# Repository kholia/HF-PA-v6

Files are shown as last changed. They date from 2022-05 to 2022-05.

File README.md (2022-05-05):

### HF-PA-v6

RF "Lego" blocks.

The idea behind this work is to build radio-things (TM) in stages which
connect to each other.

Note: This `HF-PA-v6` is like https://github.com/kholia/HF-PA-v5 which has been
broken out in stages. This makes the designing, and debugging processes much
easier.

#### Results

IRF510 @ 14 MHz -> 20v @ drain. RF output > 7.5W. No LPF. Clean'ish looking
output. No oscillations. BS170 @ 5.5v. DC bias set high for max'ish "Idq".

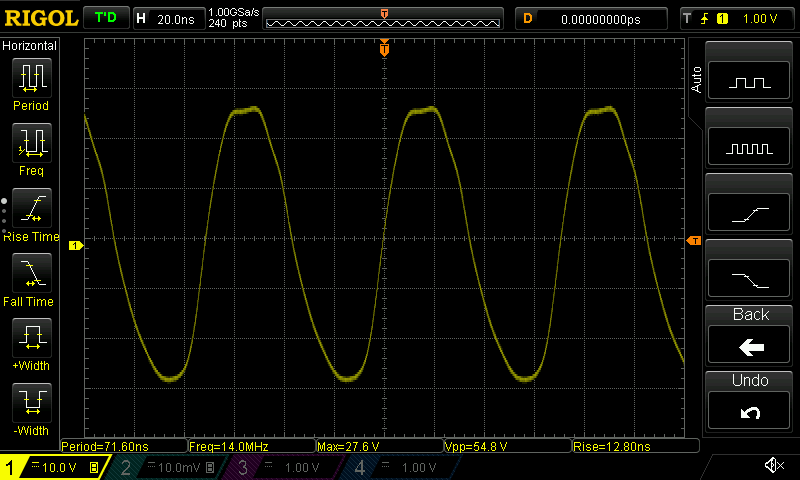
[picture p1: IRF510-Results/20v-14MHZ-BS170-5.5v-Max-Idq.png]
Lots of usable power @ 14 MHz


IRF510 @ 21 MHz -> 15v @ drain. 12.75W DC input. RF output > 3W. No LPF.
Clean'ish looking output. No oscillations. BS170 @ 5.5v. DC bias set high for
max'ish "Idq". Almost 4W can be achieved with max "Idq".

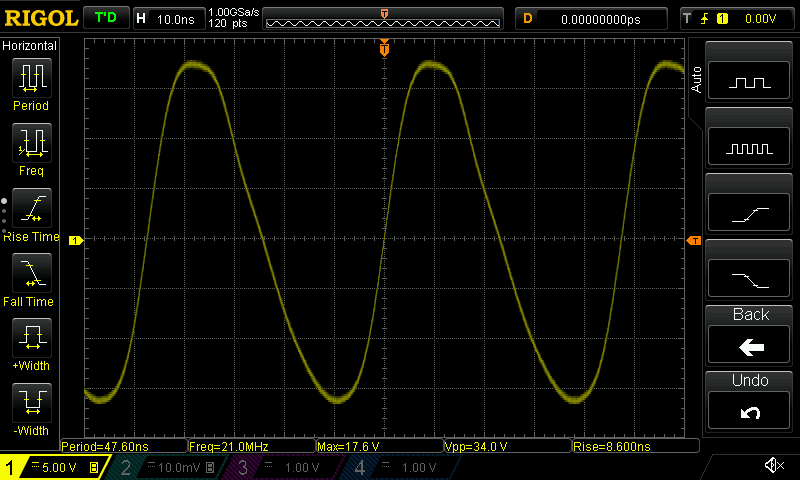
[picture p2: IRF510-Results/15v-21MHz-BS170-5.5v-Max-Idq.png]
Demo 0


IRF510 @ 28 MHz -> 14v @ drain. 9W DC input. RF output > 2W (on meter). No LPF.
Clean'ish looking output. No oscillations. BS170 @ 5.5v. DC bias set high for
max'ish "Idq".

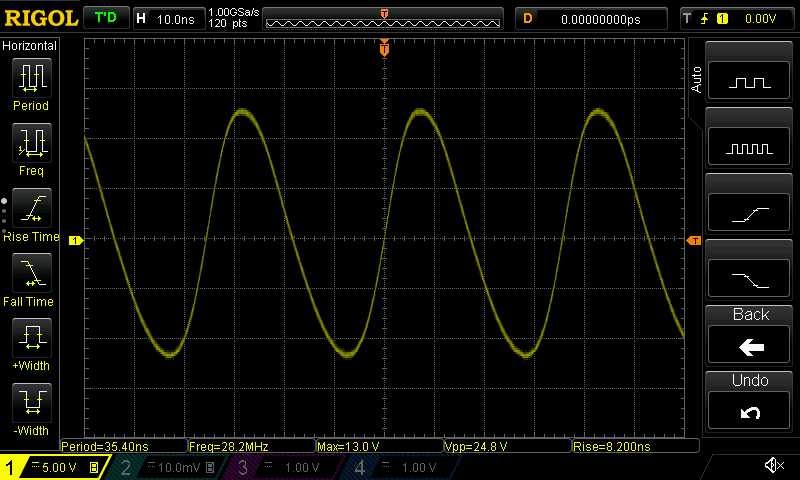
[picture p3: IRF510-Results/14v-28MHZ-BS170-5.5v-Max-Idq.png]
28 MHz - Usable Power


IRF510 @ 28 MHz -> 17v @ drain. RF output > 2.25W (on scope), 3.5W on RF power
meter. No LPF. Clean'ish looking output. No oscillations. BS170 @ 6v. DC bias
set high for max "Idq" @ 4.2v roughly.

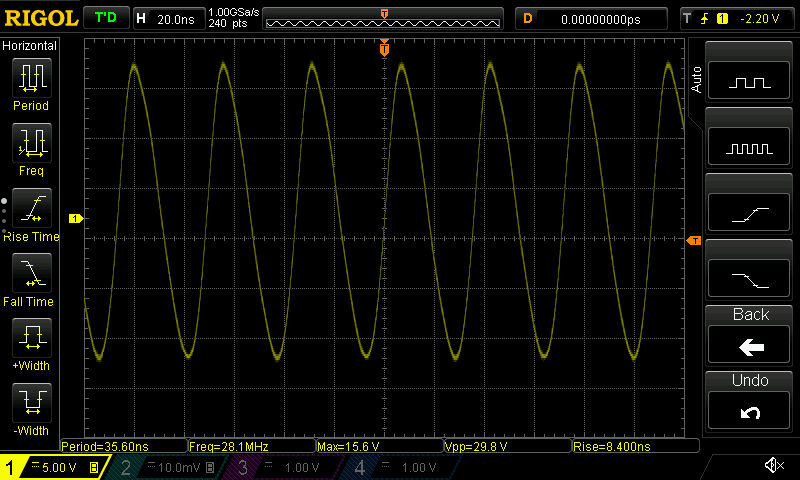
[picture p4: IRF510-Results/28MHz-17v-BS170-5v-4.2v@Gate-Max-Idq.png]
28 MHz - Usable Power 2


Note: We can even use 30v (and higher+) drain voltages (PA voltages) with
IRF510 - with much more care though!

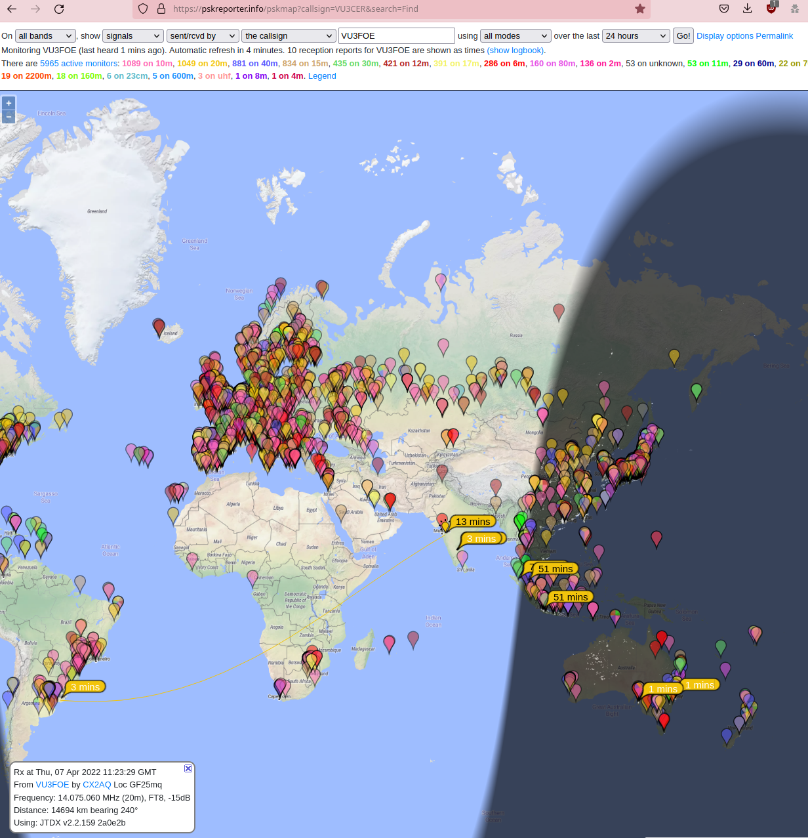
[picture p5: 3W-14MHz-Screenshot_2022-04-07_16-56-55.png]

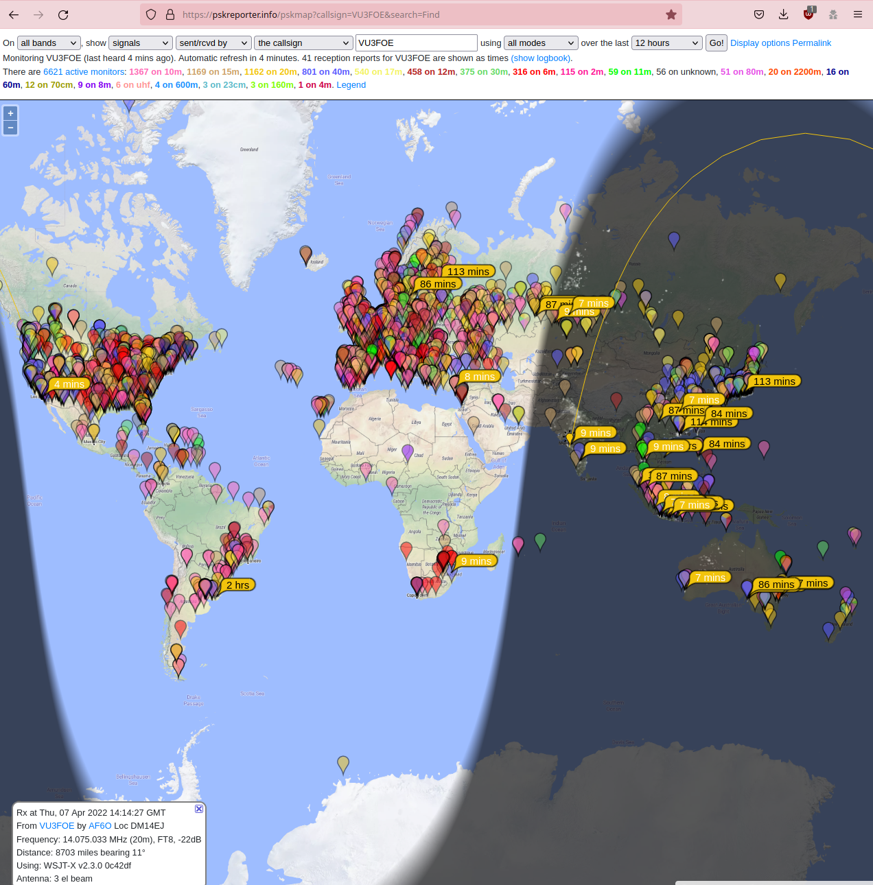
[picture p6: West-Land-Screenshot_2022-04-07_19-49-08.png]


Even 3W can get worldwide DX contacts when propagation is playing along ;)

7W (or less) of HF RF power offers global communications coverage when
propagation is good:

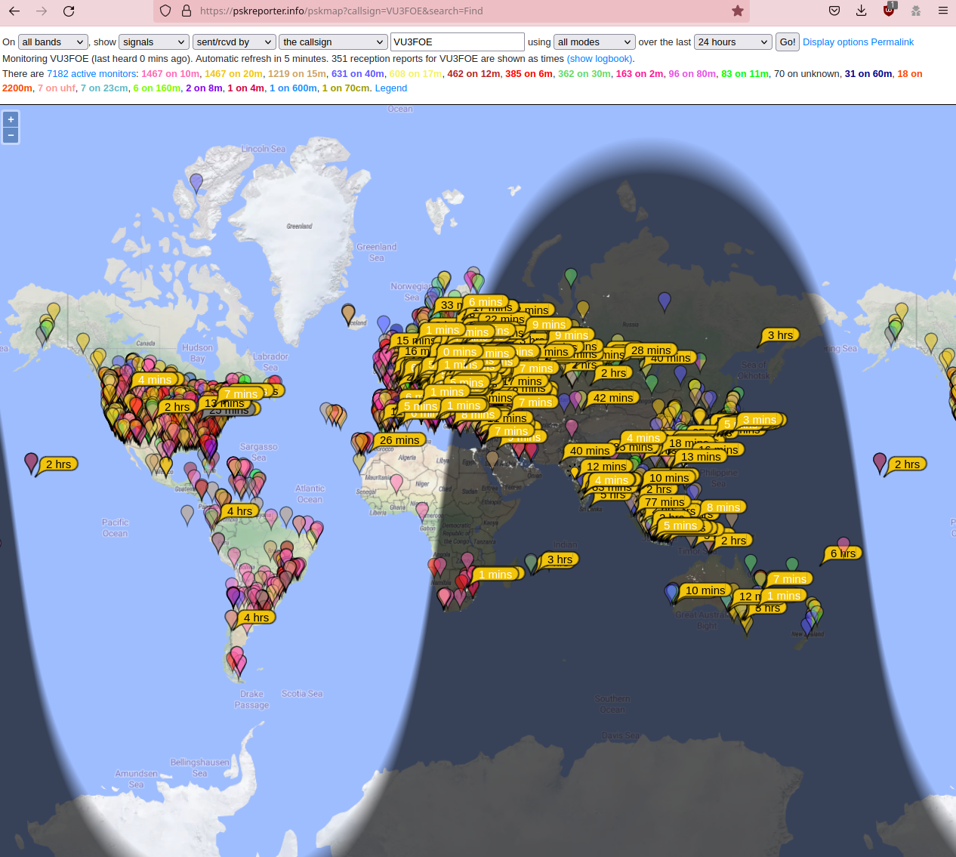
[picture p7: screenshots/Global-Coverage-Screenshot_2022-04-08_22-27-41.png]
Global Coverage

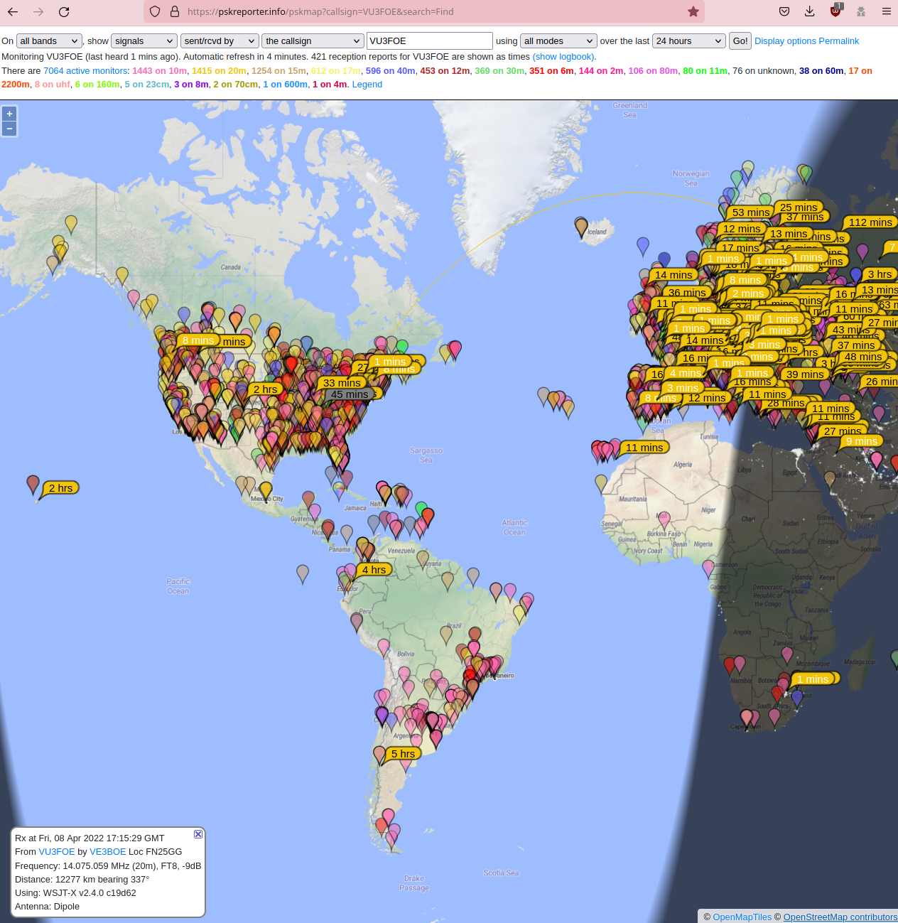
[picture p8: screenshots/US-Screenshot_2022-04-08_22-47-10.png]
US - Many Spots

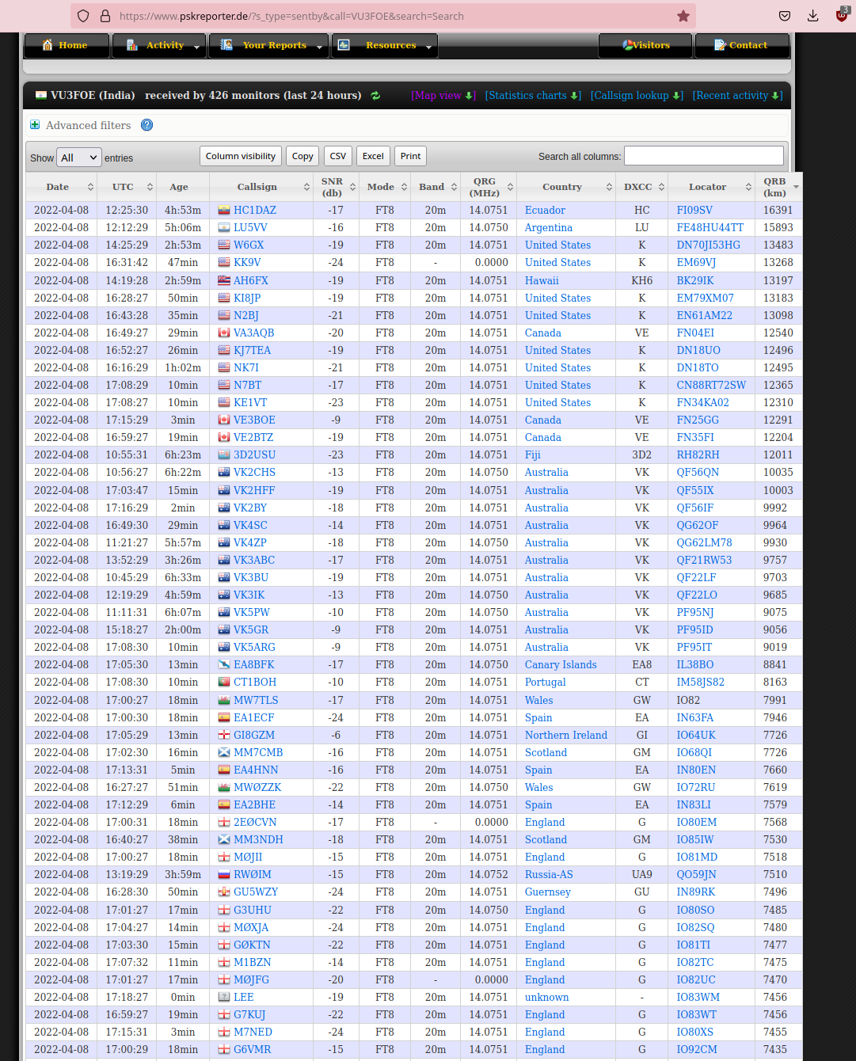
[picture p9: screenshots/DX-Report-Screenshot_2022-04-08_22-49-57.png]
DX Report


#### Notes

[BS170 Driver Performance](./BS170-Driver-Performance.txt)

As Vds is increased, the Vgs needs to be increased too - see the following
graph.

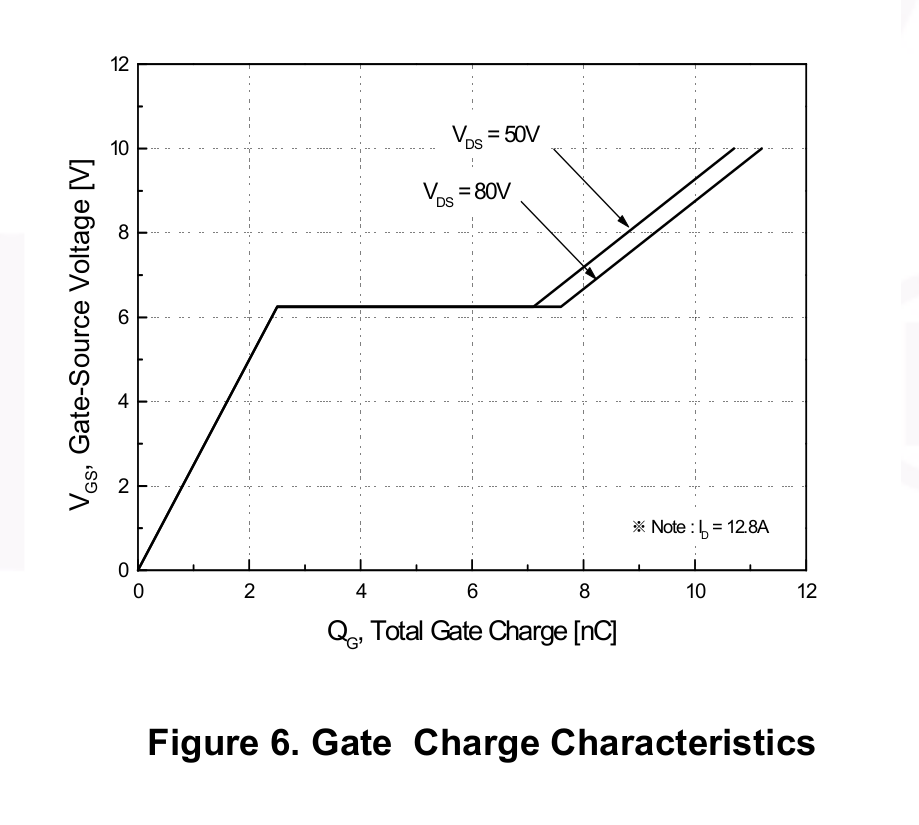
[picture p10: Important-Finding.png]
Finding


If the gate DC bias is too less, the MOSFET will not turn on properly, and will
generate a lot of distortion - one prominent distorted waveform will be at
half-the-operating frequency!

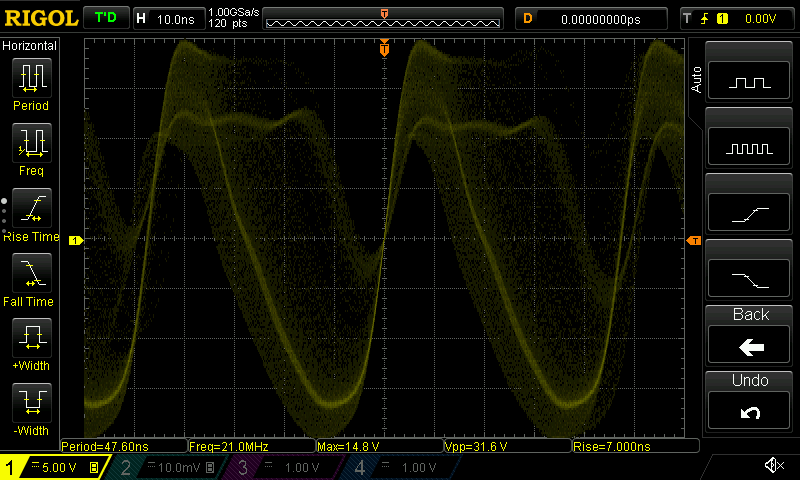
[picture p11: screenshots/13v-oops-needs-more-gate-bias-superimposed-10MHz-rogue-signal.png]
Oops - low DC bias


When operating at max "Idq" (for best linearity), the power to the IRF510
should be PTT controlled - otherwise too much (battery) power will turn to heat
instead of RF!

#### Special Notes

While IRF510 can get destroyed due to oscillations, in my case it has been a
failed 7805 (or 78L05) regulator which ultimately causes cascading failures.

A 7805 regulator can fail in fail-short mode, where `Vout == Vin`! This changes
the bias of the driver stage (BS170), and it goes in full conduction
immediately without any RF input because Vgs(th) is exceeded quite easily.
This causes further failures in the PA system!

My 7805s (and 78L05s) of dubious origin were failing (Vout shorted to Vin!)
around 20v to 24v. Here is what `bd139` (from https://www.eevblog.com/forum/)
has to say on this topic,

```
None of the voltage regulators work properly above about 20V if you want 5V
out. If you need to drop more, add a preregulator.

I found this out the hard way as well dropping 28V to 5V DC for logic in an RF
PA driver. Currently waiting for a board spin. I only needed 50mA and didn't
want RF noise so I went with a simple MOSFET/zener/resistor preregulator to
drop it down to 18Vish. Because the current requirements are relatively low I
don't need to heatsink either then as the load is spread evenly across both
MOSFET and 7805.

Also if you value the circuit it's driving, stick a 5W 5.6V zener across the
regulator output. That will smoke the prereg / regulator not the load!
```

Thank you `bd139`!

#### PCB Renderings

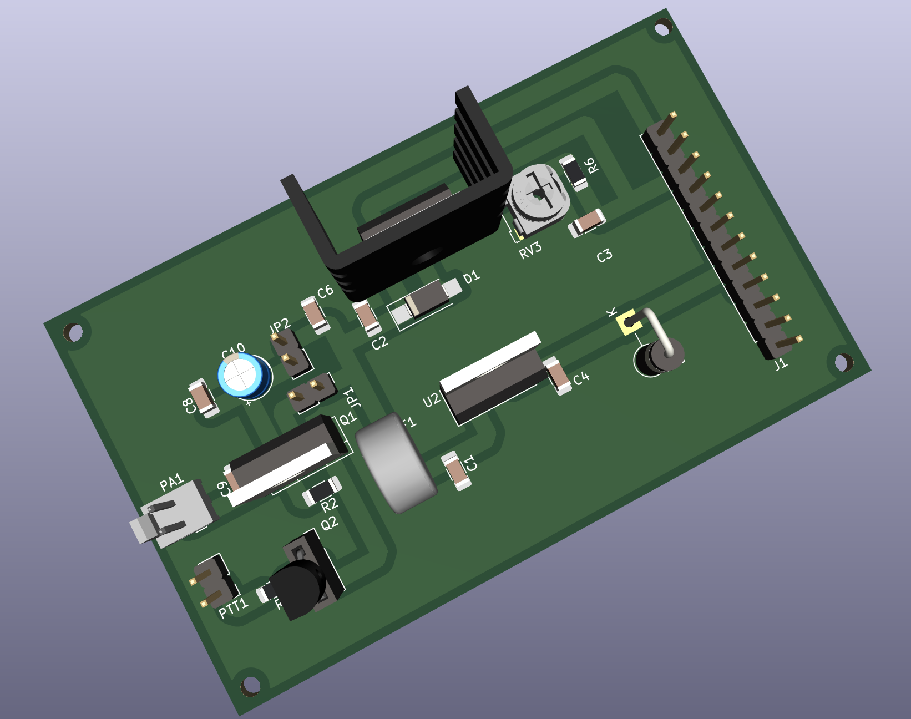
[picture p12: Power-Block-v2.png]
Power Block


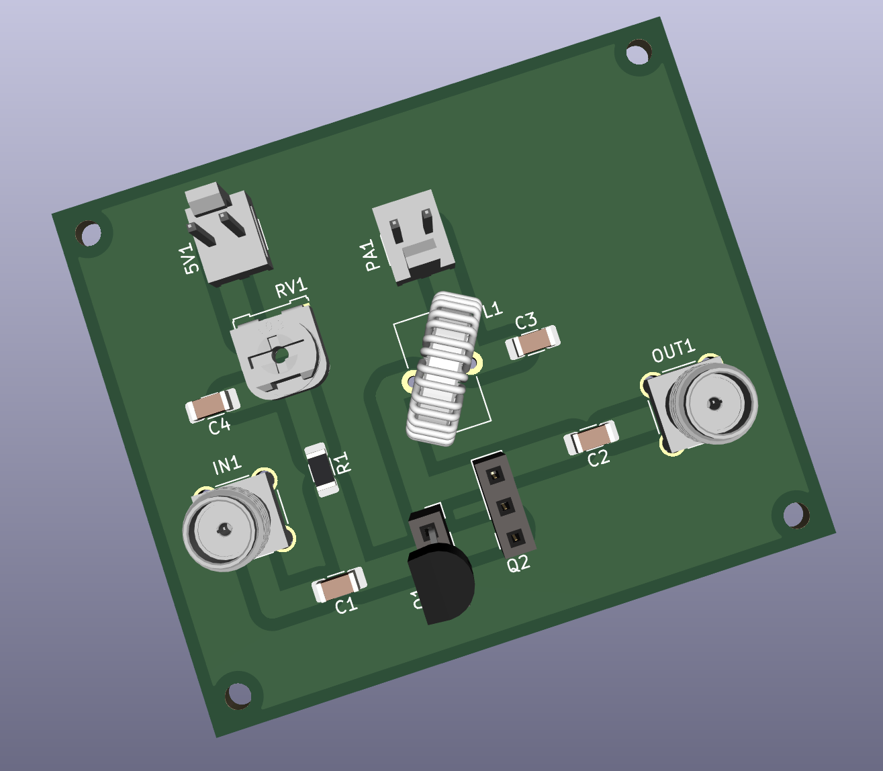
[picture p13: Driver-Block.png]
Driver Block


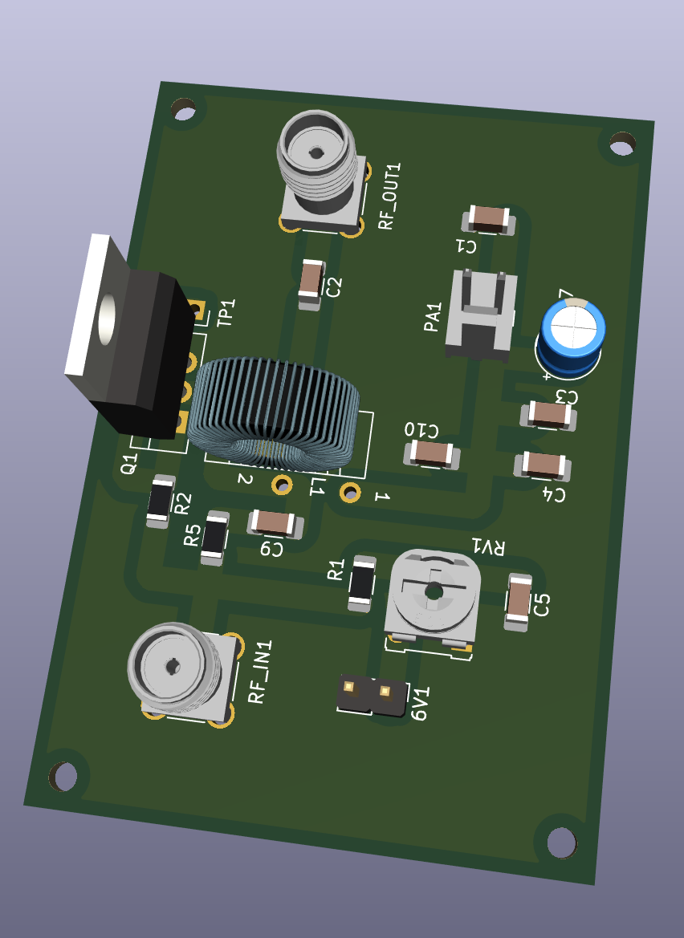
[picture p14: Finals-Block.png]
Finals Block


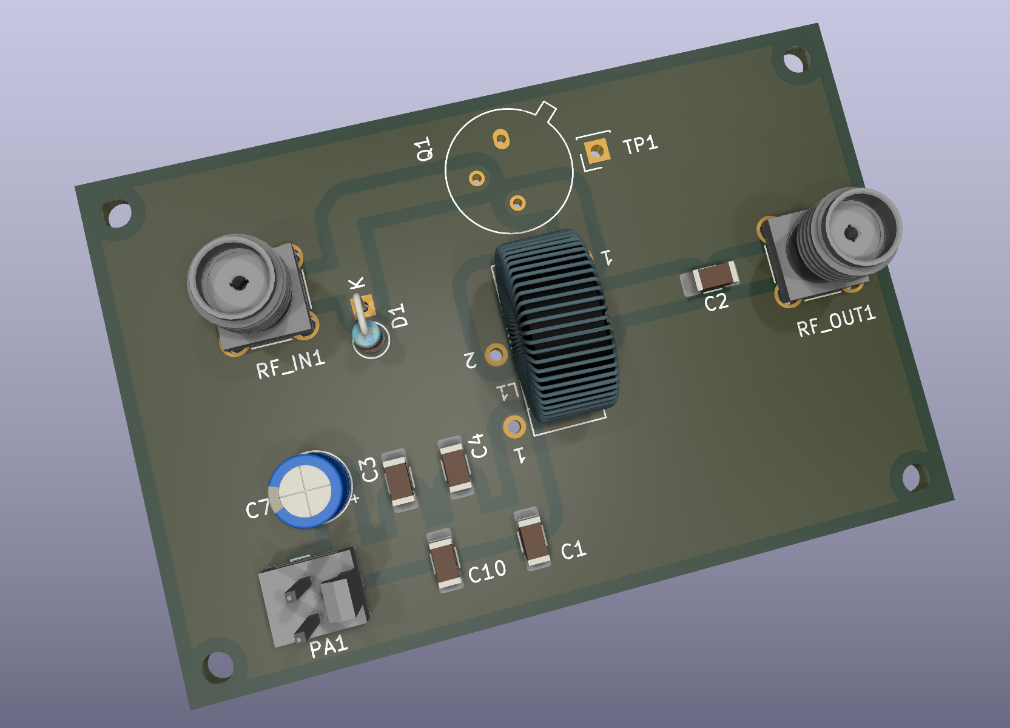
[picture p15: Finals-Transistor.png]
Finals Transistor Block


#### Joining In

Are you interested in such projects, and spam-free technical discussions?

If yes, you might be interested in joining [the 'HAMBREWERS' Telegram group](https://t.me/+TwzGyKGe8_QI_B3y).

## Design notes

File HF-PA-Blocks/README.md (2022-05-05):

The `Finals-RD15.kicad_pcb` is oversized on purpose for two reasons:

- To avoid the tedious job of cutting the larger 3x2 PCB into a smaller size.

- To save etchant by putting a copper pour over the larger area.

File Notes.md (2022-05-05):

In general terms, the PCB industry considers an RF circuit board to be any high
frequency PCB that operates above 100MHz.

IRF510 - The device dissipates 43 watts so as long as the kit doesn't draw more
that about 3.5 amps max at 12 volts, it won't fail. At 5 watts and 50%
efficiency it won't draw more than 1 amp and  can handle full reflected SWR.

https://www.rapidonline.com/Catalogue/Search?Query=CDIL

LED Wemos D1 Mini - The built-in led is on pin D4, and it is inverted.

```
Z=Vcc2 / 2PO
In [7]: (22 * 22) / (2 * 5)
Out[7]: 48.4
```

```
[dhiru@zippy DS1054Z_screen_capture]$ python2 OscScreenGrabLAN.py png 192.168.1.16
Instrument ID: RIGOL TECHNOLOGIES,DS1054Z,DS1ZA203916662,00.04.04.SP3

Receiving screen capture...
Saved file: 'captures/DS1054Z_DS1ZA203916662_2021-09-21_18.23.17.png'
```

From the internet,

7805 -> Without an extra heatsink, you can burn off up to 2W. If you need more
current heatsinks are cheap and effective. Every 11 degrees Celsius cooler you
run your semiconductors, reliability doubles.

- Get the max die temperature from the regulator datasheet

- Get the Theta(j-a) number from the datasheet in degrees C per watt.

- Calculate the power dissipated by your device. Example: 9 volts in, 5 volts
  out at 1 amp would be 4 watts.

- Multiply the watts dissipated by Theta(j-a) to get the temperature rise.

- Add the temperature rise to the maximum ambient temperature the device will
  be exposed to.

- If the number computed in #5 is greater than the max die temperature, then
  you need to use a heatsink or some other way to actively
  cool the device.

- If you use a heatsink, you will use a slightly different set of calculations
  involving the regulator's Theta(j-c) (Not Theta(j-a).

For a 7805 it's 65 C/W junction to air.

This means that if the regulator produces 1 W of heat, the die will be 65
degrees C hotter than the ambient air.  The maximum operating temperature is
125 C. Pune temperature (inside the case) -> 70 c.

Can dissipate -> (125 - 70) / 65 -> 0.84 watts. P = VI. This allows around
100mA of current when input voltage is 14v.

Note: Try the `Small mark` option instead of the regular `Real drill` option in
KiCad.

Note 2: Set track width to >= 2.2mm in KiCad - try to work with this. For the
copper pour, set clearance to 0.850.

...

LTspice notes:

- Download LTspice (Google "Download LTspice"). It's free.

- `~/Documents/LTspiceXVII/lib`

  Extract external components to this path.

- Extract the `contents` of `LTspiceXVII_2019Jan29.zip` (Google for this file) properly to `~/Documents/LTspiceXVII` path.

...

From Daniel Alonso:

A unnecessarily large L doesn't do harm by itself, but the 'series' self
resonant frequencies decrease when you increase the turns count. A
rule-of-thumb is choosing an inductive reactance of 4 times the load
resistance, at the lower frequency. Supposing the circuit is to drive a 50 ohm
load, to get a reactance of 200 ohms at 3.5MHz you will need L = 200/(2*pi*3.5)
= 9.1uH. Or if you are more conservative with 10 times the R, it should be
22.7uH.

From Sandeep Lohia:

Inductive reactance on primary side is critical and the magic number is `36`.

```
36 ÷ lowest operating frequency.
36 ÷ 7 = 5 uh
```

Inductance on secondary not critical but turns ratio is...

...

From Farhan:

At 25 watts, the RF peak voltage is 50v. This is easily handled by the regular
disc ceramics rated for 60v. Higher power will require expensive capacitors.

Pinout helper:

1 2 3 4
E B C E

BD139
B C E

NTE-224 results with BS170 driver:

- 4W @ 7 MHz
- 1.6W+ @ 14 MHz
- 0.8W @ 28 MHz

NTE-224 is usable, and offers OK'ish performance for the price (0.23 USD).

The IRF510 option is much better at this price point (with higher voltages
though).

Learnings `http://pa0o-jaap.blogspot.com`:

- http://pa0o-jaap.blogspot.com/2017/03/u3s-5w-pa.html
- http://pa0o-jaap.blogspot.com/2017/04/u3s-ultimate3-5w.html

- The QRP-LABS IRF510 5W PA will not deliver more then 1W at 28MHz not to
  speak of 50 MHz there it is an attenuator. Using the RD15HVF1 Mitsubishi did
  bring just a little more. 3-4 W at 28 and 1.5 W at 50MHz

- The 5W-PA (RD15HVF1 powered) is good for 10MHz and lower but very
  disappointing at higher bands.

- At 20W DC input it stays cool.

- Turning up the bias seems the only way to get 5W out at 50MHz 12V.

- Use 7 turns (instead of 10) on the output transformer.

- Use 1:9 (trifilar) output transformer instead of my bifilar one!?

- T1 modified to 8 turns (from 10 turns originally) also did not increase the
  10 and 6 output.

PDX-v2 PA (`HF-PA-Combined`):

3.3W+ @ 13.8v @ 21 MHz. 4.25v gate bias. 13.65W DC IN. RF meter shows ~4W.

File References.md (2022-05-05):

#### References

- http://shop.qrp-labs.com/pa
- http://shop.qrp-labs.com/kits/U3S
- https://github.com/kholia/HF-PA-v3/
- https://github.com/kholia/HF-PA-v2/
- https://github.com/agustinmartino/wsjt_transceiver
- https://www.qrp-labs.com/ultimate3/u3info/u3sbifilar.html
- https://www.qsl.net/py2ohh/trx/peanuts/peanuts.html
- https://www.qsl.net/py2ohh/trx/lpf100w/lpf100w.html (LPF filters)
- http://hyse.org/pdf/www.aoc.nrao.edu/~pharden/hobby/_ClassDEF1.pdf
- http://hyse.org/pdf/www.aoc.nrao.edu/~pharden/hobby/_ClassDEF2.pdf
- http://thestone.zone/radio/2020/12/13/multi-watt-amplifier.html
- http://thestone.zone/radio/2020/12/18/gate-driver-amplifier.html
- http://thestone.zone/radio/2021/01/14/capacitors.html
- http://thestone.zone/radio/2021/01/16/minor-enhancements.html
- https://www.g0kla.com/scpa/SimpleCheapPA.php
- https://www.linkedin.com/pulse/rf-pcb-design-rules-manufacturing-process-lisa-chu/
- http://thestone.zone/radio/2021/06/04/attenuator.html
- http://thestone.zone/radio/2021/06/05/power-amplifier.html
- https://on7dq.blogspot.com/2020/12/qcx-mini-measurements.html
- https://www.random-science-tools.com/electronics/dBm-Watts-volts.htm
- https://www.mitsubishielectric.com/semiconductors/php/oSearch.php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
- http://www.carnut.info/WSPR_Tx/WSPR_Tx.htm
- https://sites.google.com/view/andy-g0ftd/iron-fist-transmitter
- https://www.dj0abr.de/english/technik/dds/pa.htm
- https://www.qsl.net/py2ohh/
- https://hf5l.pl/en/transceiver-usdx-with-arduino-nano/#
- http://www.m0rzf.co.uk/PA_Old/index.html
- https://vk3hn.wordpress.com/2019/05/01/summit-prowler-6-a-pocket-sized-ssb-cw-transceiver-for-80-40-30-and-20m/
- http://am-transmitter.blogspot.com/2014/07/protect-your-mosfet-final-stage.html
- https://electronics.stackexchange.com/questions/11583/grounding-a-soldering-iron
- http://hfsignals.blogspot.com/p/25-watt-linear-for-40-and-20.html
- http://www.norcalqrp.org/nb6mminiboots.htm
- https://github.com/RoGeorge/DS1054Z_screen_capture
- https://github.com/profdc9/QRPAmplifier

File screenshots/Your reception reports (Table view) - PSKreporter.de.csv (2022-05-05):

ID | Date | UTC | Age | Callsign | SNR (db) | Mode | Band | QRG (MHz) | Country | DXCC | Locator | QRB (km)
398 | 2022-04-08 | 12:25:30 | 4h:53m | HC1DAZ | -17 | FT8 | 20m | 14.0751 | Ecuador | HC | FI09SV | 16391
403 | 2022-04-08 | 12:12:29 | 5h:06m | LU5VV | -16 | FT8 | 20m | 14.0750 | Argentina | LU | FE48HU44TT | 15893
353 | 2022-04-08 | 14:25:29 | 2h:53m | W6GX | -19 | FT8 | 20m | 14.0751 | United States | K | DN70JI53HG | 13483
279 | 2022-04-08 | 16:31:42 | 47min | KK9V | -24 | FT8 | - | 0.0000 | United States | K | EM69VJ | 13268
359 | 2022-04-08 | 14:19:28 | 2h:59m | AH6FX | -19 | FT8 | 20m | 14.0751 | Hawaii | KH6 | BK29IK | 13197
296 | 2022-04-08 | 16:28:27 | 50min | KI8JP | -19 | FT8 | 20m | 14.0751 | United States | K | EM79XM07 | 13183
250 | 2022-04-08 | 16:43:28 | 35min | N2BJ | -21 | FT8 | 20m | 14.0751 | United States | K | EN61AM22 | 13098
215 | 2022-04-08 | 16:49:27 | 29min | VA3AQB | -20 | FT8 | 20m | 14.0751 | Canada | VE | FN04EI | 12540
184 | 2022-04-08 | 16:52:27 | 26min | KJ7TEA | -19 | FT8 | 20m | 14.0751 | United States | K | DN18UO | 12496
321 | 2022-04-08 | 16:16:29 | 1h:02m | NK7I | -21 | FT8 | 20m | 14.0751 | United States | K | DN18TO | 12495
63 | 2022-04-08 | 17:08:29 | 10min | N7BT | -17 | FT8 | 20m | 14.0751 | United States | K | CN88RT72SW | 12365
66 | 2022-04-08 | 17:08:27 | 10min | KE1VT | -23 | FT8 | 20m | 14.0751 | United States | K | FN34KA02 | 12310
15 | 2022-04-08 | 17:15:29 | 3min | VE3BOE | -9 | FT8 | 20m | 14.0751 | Canada | VE | FN25GG | 12291
164 | 2022-04-08 | 16:59:27 | 19min | VE2BTZ | -19 | FT8 | 20m | 14.0751 | Canada | VE | FN35FI | 12204
417 | 2022-04-08 | 10:55:31 | 6h:23m | 3D2USU | -23 | FT8 | 20m | 14.0751 | Fiji | 3D2 | RH82RH | 12011
416 | 2022-04-08 | 10:56:27 | 6h:22m | VK2CHS | -13 | FT8 | 20m | 14.0750 | Australia | VK | QF56QN | 10035
94 | 2022-04-08 | 17:03:47 | 15min | VK2HFF | -19 | FT8 | 20m | 14.0751 | Australia | VK | QF55IX | 10003
6 | 2022-04-08 | 17:16:29 | 2min | VK2BY | -18 | FT8 | 20m | 14.0751 | Australia | VK | QF56IF | 9992
212 | 2022-04-08 | 16:49:30 | 29min | VK4SC | -14 | FT8 | 20m | 14.0751 | Australia | VK | QG62OF | 9964
412 | 2022-04-08 | 11:21:27 | 5h:57m | VK4ZP | -18 | FT8 | 20m | 14.0750 | Australia | VK | QG62LM78 | 9930
374 | 2022-04-08 | 13:52:29 | 3h:26m | VK3ABC | -17 | FT8 | 20m | 14.0751 | Australia | VK | QF21RW53 | 9757
421 | 2022-04-08 | 10:45:29 | 6h:33m | VK3BU | -19 | FT8 | 20m | 14.0751 | Australia | VK | QF22LF | 9703
401 | 2022-04-08 | 12:19:29 | 4h:59m | VK3IK | -13 | FT8 | 20m | 14.0750 | Australia | VK | QF22LO | 9685
414 | 2022-04-08 | 11:11:31 | 6h:07m | VK5PW | -10 | FT8 | 20m | 14.0750 | Australia | VK | PF95NJ | 9075
347 | 2022-04-08 | 15:18:27 | 2h:00m | VK5GR | -9 | FT8 | 20m | 14.0751 | Australia | VK | PF95ID | 9056
60 | 2022-04-08 | 17:08:30 | 10min | VK5ARG | -9 | FT8 | 20m | 14.0751 | Australia | VK | PF95IT | 9019
75 | 2022-04-08 | 17:05:30 | 13min | EA8BFK | -17 | FT8 | 20m | 14.0750 | Canary Islands | EA8 | IL38BO | 8841
62 | 2022-04-08 | 17:08:30 | 10min | CT1BOH | -10 | FT8 | 20m | 14.0751 | Portugal | CT | IM58JS82 | 8163
150 | 2022-04-08 | 17:00:27 | 18min | MW7TLS | -17 | FT8 | 20m | 14.0751 | Wales | GW | IO82 | 7991
130 | 2022-04-08 | 17:00:30 | 18min | EA1ECF | -24 | FT8 | 20m | 14.0751 | Spain | EA | IN63FA | 7946
80 | 2022-04-08 | 17:05:29 | 13min | GI8GZM | -6 | FT8 | 20m | 14.0751 | Northern Ireland | GI | IO64UK | 7726
111 | 2022-04-08 | 17:02:30 | 16min | MM7CMB | -16 | FT8 | 20m | 14.0751 | Scotland | GM | IO68QI | 7726
35 | 2022-04-08 | 17:13:31 | 5min | EA4HNN | -16 | FT8 | 20m | 14.0751 | Spain | EA | IN80EN | 7660
304 | 2022-04-08 | 16:27:27 | 51min | MWØZZK | -22 | FT8 | 20m | 14.0750 | Wales | GW | IO72RU | 7619
42 | 2022-04-08 | 17:12:29 | 6min | EA2BHE | -14 | FT8 | 20m | 14.0751 | Spain | EA | IN83LI | 7579
128 | 2022-04-08 | 17:00:31 | 18min | 2EØCVN | -17 | FT8 | - | 0.0000 | England | G | IO80EM | 7568
260 | 2022-04-08 | 16:40:27 | 38min | MM3NDH | -18 | FT8 | 20m | 14.0751 | Scotland | GM | IO85IW | 7530
148 | 2022-04-08 | 17:00:27 | 18min | MØJII | -15 | FT8 | 20m | 14.0751 | England | G | IO81MD | 7518
386 | 2022-04-08 | 13:19:29 | 3h:59m | RWØIM | -15 | FT8 | 20m | 14.0752 | Russia-AS | UA9 | QO59JN | 7510
290 | 2022-04-08 | 16:28:30 | 50min | GU5WZY | -24 | FT8 | 20m | 14.0751 | Guernsey | GU | IN89RK | 7496
127 | 2022-04-08 | 17:01:27 | 17min | G3UHU | -22 | FT8 | 20m | 14.0750 | England | G | IO80SO | 7485
92 | 2022-04-08 | 17:04:27 | 14min | MØXJA | -24 | FT8 | 20m | 14.0751 | England | G | IO82SQ | 7480
99 | 2022-04-08 | 17:03:30 | 15min | GØKTN | -22 | FT8 | 20m | 14.0751 | England | G | IO81TI | 7477
70 | 2022-04-08 | 17:07:32 | 11min | M1BZN | -14 | FT8 | 20m | 14.0751 | England | G | IO82TC | 7475
126 | 2022-04-08 | 17:01:27 | 17min | MØJFG | -20 | FT8 | - | 0.0000 | England | G | IO82UC | 7470
2 | 2022-04-08 | 17:18:27 | 0min | LEE | -19 | FT8 | 20m | 14.0751 | unknown | - | IO83WM | 7456
161 | 2022-04-08 | 16:59:27 | 19min | G7KUJ | -22 | FT8 | 20m | 14.0751 | England | G | IO83WT | 7456
9 | 2022-04-08 | 17:15:31 | 3min | M7NED | -24 | FT8 | 20m | 14.0751 | England | G | IO80XS | 7455
138 | 2022-04-08 | 17:00:29 | 18min | G6VMR | -15 | FT8 | 20m | 14.0751 | England | G | IO92CM | 7435
162 | 2022-04-08 | 16:59:27 | 19min | EA5OL | -20 | FT8 | 20m | 14.0751 | Spain | EA | IM99OK50 | 7433
176 | 2022-04-08 | 16:56:30 | 22min | M3BWF | -18 | FT8 | 20m | 14.0751 | England | G | IO91DP | 7430
203 | 2022-04-08 | 16:50:29 | 28min | EA5IZO | -17 | FT8 | 20m | 14.0751 | Spain | EA | IM98QJ | 7430
90 | 2022-04-08 | 17:04:27 | 14min | MØLCS | -24 | FT8 | 20m | 14.0751 | England | G | IO91GN | 7413
46 | 2022-04-08 | 17:11:30 | 7min | G4BRK | -14 | FT8 | 20m | 14.0751 | England | G | IO91HP | 7407
96 | 2022-04-08 | 17:03:30 | 15min | MØIZM | -24 | FT8 | 20m | 14.0751 | England | G | IO92KX | 7390
151 | 2022-04-08 | 17:00:27 | 18min | M7CLO | -19 | FT8 | 20m | 14.0751 | England | G | IO93KA | 7390
209 | 2022-04-08 | 16:50:27 | 28min | G7AAY | -21 | FT8 | 20m | 14.0751 | England | G | IO92NG | 7373
22 | 2022-04-08 | 17:15:27 | 3min | MØHOM | -10 | FT8 | 20m | 14.0751 | England | G | IO93QO | 7357
36 | 2022-04-08 | 17:13:30 | 5min | G7RDX | -18 | FT8 | 20m | 14.0752 | England | G | IO91RU | 7350
172 | 2022-04-08 | 16:57:29 | 21min | 2EØFVN | -24 | FT8 | 20m | 14.0751 | England | G | IO91WP | 7321
132 | 2022-04-08 | 17:00:30 | 18min | F1DXP | -15 | FT8 | 20m | 14.0751 | France | F | JN05CU | 7305
86 | 2022-04-08 | 17:04:31 | 14min | EA6FA | -14 | FT8 | 20m | 14.0751 | Balearic Islands | EA6 | JM08RQ | 7246
114 | 2022-04-08 | 17:02:29 | 16min | F4BHK | -12 | FT8 | 20m | 14.0751 | France | F | JN08LT | 7243
423 | 2022-04-08 | 10:38:42 | 6h:40m | VK6IR | -24 | FT8 | 20m | 14.0751 | Australia | VK | OF77WJ | 7231
74 | 2022-04-08 | 17:06:27 | 12min | VK6AS | -14 | FT8 | 20m | 14.0751 | Australia | VK | OF77WW05 | 7188
367 | 2022-04-08 | 14:01:29 | 3h:17m | VK4ABW/8 | -18 | FT8 | 20m | 14.0750 | Australia | VK | PH57MM | 7152
323 | 2022-04-08 | 16:16:29 | 1h:02m | DL8EX | -24 | FT8 | 20m | 14.0751 | Germany | DL | JO42 | 7122
195 | 2022-04-08 | 16:51:27 | 27min | ON4BAR | -18 | FT8 | 20m | 14.0751 | Belgium | ON | JO10RU | 7069
285 | 2022-04-08 | 16:29:29 | 49min | LA1ØØB | -24 | FT8 | 20m | 14.0751 | Norway | LA | JP20RH | 7055
178 | 2022-04-08 | 16:55:29 | 23min | LB9ZG | -17 | FT8 | 20m | 14.0751 | Norway | LA | JP20VR | 7045
16 | 2022-04-08 | 17:15:29 | 3min | PE1GCW | -24 | FT8 | 20m | 14.0751 | Netherlands | PA | JO21AK | 7032
202 | 2022-04-08 | 16:50:29 | 28min | ON4JON | -16 | FT8 | 20m | 14.0750 | Belgium | ON | JO20AN | 7026
14 | 2022-04-08 | 17:15:29 | 3min | PD5JOS | -9 | FT8 | 20m | 14.0750 | Netherlands | PA | JO21CW | 7024
252 | 2022-04-08 | 16:43:27 | 35min | ON7UDM | -24 | FT8 | 20m | 14.0751 | Belgium | ON | JO21BC | 7024
125 | 2022-04-08 | 17:01:28 | 17min | OZ2AFN | -24 | FT8 | 20m | 14.0751 | Denmark | OZ | JO57 | 7018
206 | 2022-04-08 | 16:50:27 | 28min | ON3PVC | -22 | FT8 | 20m | 14.0751 | Belgium | ON | JO20CX | 7017
235 | 2022-04-08 | 16:47:15 | 31min | ON3URE | -22 | FT8 | 20m | 14.0751 | Belgium | ON | JO20CW | 7017
11 | 2022-04-08 | 17:15:30 | 3min | LB8ZH | -24 | FT8 | 20m | 14.0750 | Norway | LA | JP30CI | 7015
24 | 2022-04-08 | 17:15:27 | 3min | NL13951 | -24 | FT8 | 20m | 14.0751 | unknown | - | JO21EV | 7012
26 | 2022-04-08 | 17:15:26 | 3min | ZS6TAN | -18 | FT8 | 20m | 14.0751 | South Africa | ZS | KG43CW | 7007
277 | 2022-04-08 | 16:33:43 | 45min | PD1HPB | -22 | FT8 | 20m | 14.0751 | Netherlands | PA | JO22JP | 6991
336 | 2022-04-08 | 16:11:30 | 1h:07m | ZS6ZO | -18 | FT8 | 20m | 14.0748 | South Africa | ZS | KG44CE | 6989
231 | 2022-04-08 | 16:47:30 | 31min | PDØRDD | -24 | FT8 | 20m | 14.0751 | Netherlands | PA | JO22MD14 | 6969
272 | 2022-04-08 | 16:35:29 | 43min | PAØADG | -13 | FT8 | 20m | 14.0751 | Netherlands | PA | JO22NB | 6963
145 | 2022-04-08 | 17:00:27 | 18min | ON4ATW | -24 | FT8 | 20m | 14.0751 | Belgium | ON | JO20NX55 | 6953
48 | 2022-04-08 | 17:11:29 | 7min | PD2SHB | -23 | FT8 | 20m | 14.0751 | Netherlands | PA | JO21PQ | 6948
133 | 2022-04-08 | 17:00:30 | 18min | F4FSY | -14 | FT8 | 20m | 14.0751 | France | F | JN25KN | 6942
193 | 2022-04-08 | 16:51:29 | 27min | PD9BG | -22 | FT8 | 20m | 14.0751 | Netherlands | PA | JO21QP | 6942
23 | 2022-04-08 | 17:15:27 | 3min | PDØWAG | -19 | FT8 | 20m | 14.0751 | Netherlands | PA | JO21TX | 6928
89 | 2022-04-08 | 17:04:28 | 14min | LA6HNA | -20 | FT8 | 20m | 14.0751 | Norway | LA | JP53AS | 6904
120 | 2022-04-08 | 17:01:30 | 17min | PD1DMO | -15 | FT8 | 20m | 14.0751 | Netherlands | PA | JO32FI | 6875
280 | 2022-04-08 | 16:31:30 | 47min | DL7CW | -22 | FT8 | 20m | 14.0750 | Germany | DL | JO31FH | 6863
261 | 2022-04-08 | 16:39:30 | 39min | DL2OAH | -17 | FT8 | 20m | 14.0751 | Germany | DL | JO31FE24 | 6862
157 | 2022-04-08 | 16:59:30 | 19min | LA5FJA | -17 | FT8 | 20m | 14.0751 | Norway | LA | JP41UP | 6860
312 | 2022-04-08 | 16:23:30 | 55min | LA7GM | -18 | FT8 | 20m | 14.0751 | Norway | LA | JP65DL | 6856
112 | 2022-04-08 | 17:02:30 | 16min | LB8PI | -14 | FT8 | 20m | 14.0751 | Norway | LA | JP53LL | 6851
189 | 2022-04-08 | 16:51:29 | 27min | PD7JLP | -24 | FT8 | 20m | 14.0751 | Netherlands | PA | JO32KQ | 6851
306 | 2022-04-08 | 16:27:27 | 51min | PA7KY | -14 | FT8 | 20m | 14.0751 | Netherlands | PA | JO32LR | 6846
247 | 2022-04-08 | 16:44:30 | 34min | DJ6JZ | -16 | FT8 | 20m | 14.0751 | Germany | DL | JO31KK37 | 6836
338 | 2022-04-08 | 15:55:27 | 1h:23m | F6BPZ | -12 | FT8 | 20m | 14.0751 | France | F | JN35DS79 | 6833
379 | 2022-04-08 | 13:45:29 | 3h:33m | LB1RJ | -22 | FT8 | 20m | 14.0751 | Norway | LA | JO49PN | 6830
375 | 2022-04-08 | 13:50:28 | 3h:28m | LA8AV | -20 | FT8 | 20m | 14.0750 | Norway | LA | JO49RT | 6827
198 | 2022-04-08 | 16:50:33 | 28min | DL8DBU | -20 | FT8 | 20m | 14.0751 | Germany | DL | JO30NP22 | 6810
232 | 2022-04-08 | 16:47:29 | 31min | F4CHF | -14 | FT8 | 20m | 14.0751 | France | F | JN35HW | 6808
264 | 2022-04-08 | 16:39:29 | 39min | DK9JC | -24 | FT8 | 20m | 14.0751 | Germany | DL | JN39MF | 6801
322 | 2022-04-08 | 16:16:29 | 1h:02m | LB4NI | -23 | FT8 | 20m | 14.0751 | Norway | LA | JO49XR | 6797
242 | 2022-04-08 | 16:45:28 | 33min | DM1YS | -19 | FT8 | 20m | 14.0751 | Germany | DL | JO30PJ | 6795
223 | 2022-04-08 | 16:48:29 | 30min | DF6DBF | -15 | FT8 | 20m | 14.0751 | Germany | DL | JO31SI | 6789
3 | 2022-04-08 | 17:18:26 | 0min | LA4MIA | -7 | FT8 | 20m | 14.0751 | Norway | LA | JO59HQ81 | 6760
78 | 2022-04-08 | 17:05:29 | 13min | OZ5XE | -24 | FT8 | 20m | 14.0750 | Denmark | OZ | JO47UF | 6752
229 | 2022-04-08 | 16:48:15 | 30min | DG5DH | -14 | FT8 | 20m | 14.0751 | Germany | DL | JO41DS | 6743
37 | 2022-04-08 | 17:13:29 | 5min | JF1JBO | -15 | FT8 | 20m | 14.0751 | Japan | JA | QM05FX | 6734
79 | 2022-04-08 | 17:05:29 | 13min | OZ4DCJ | -21 | FT8 | 20m | 14.0751 | Denmark | OZ | JO57BF | 6727
20 | 2022-04-08 | 17:15:27 | 3min | IW1AZF | -21 | FT8 | 20m | 14.0751 | Italy | I | JN35TC40 | 6726
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

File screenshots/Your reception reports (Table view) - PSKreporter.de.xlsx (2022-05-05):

ID | Date | UTC | Age | Callsign | SNR (db) | Mode | Band | QRG (MHz) | Country | DXCC | Locator | QRB (km)
398 | 2022-04-08 | 12:25:30 | 4h:53m | HC1DAZ | -17 | FT8 | 20m | 14.0751 | Ecuador | HC | FI09SV | 16391
403 | 2022-04-08 | 12:12:29 | 5h:06m | LU5VV | -16 | FT8 | 20m | 14.075 | Argentina | LU | FE48HU44TT | 15893
353 | 2022-04-08 | 14:25:29 | 2h:53m | W6GX | -19 | FT8 | 20m | 14.0751 | United States | K | DN70JI53HG | 13483
279 | 2022-04-08 | 16:31:42 | 47min | KK9V | -24 | FT8 | - | 0 | United States | K | EM69VJ | 13268
359 | 2022-04-08 | 14:19:28 | 2h:59m | AH6FX | -19 | FT8 | 20m | 14.0751 | Hawaii | KH6 | BK29IK | 13197
296 | 2022-04-08 | 16:28:27 | 50min | KI8JP | -19 | FT8 | 20m | 14.0751 | United States | K | EM79XM07 | 13183
250 | 2022-04-08 | 16:43:28 | 35min | N2BJ | -21 | FT8 | 20m | 14.0751 | United States | K | EN61AM22 | 13098
215 | 2022-04-08 | 16:49:27 | 29min | VA3AQB | -20 | FT8 | 20m | 14.0751 | Canada | VE | FN04EI | 12540
184 | 2022-04-08 | 16:52:27 | 26min | KJ7TEA | -19 | FT8 | 20m | 14.0751 | United States | K | DN18UO | 12496
321 | 2022-04-08 | 16:16:29 | 1h:02m | NK7I | -21 | FT8 | 20m | 14.0751 | United States | K | DN18TO | 12495
63 | 2022-04-08 | 17:08:29 | 10min | N7BT | -17 | FT8 | 20m | 14.0751 | United States | K | CN88RT72SW | 12365
66 | 2022-04-08 | 17:08:27 | 10min | KE1VT | -23 | FT8 | 20m | 14.0751 | United States | K | FN34KA02 | 12310
15 | 2022-04-08 | 17:15:29 | 3min | VE3BOE | -9 | FT8 | 20m | 14.0751 | Canada | VE | FN25GG | 12291
164 | 2022-04-08 | 16:59:27 | 19min | VE2BTZ | -19 | FT8 | 20m | 14.0751 | Canada | VE | FN35FI | 12204
417 | 2022-04-08 | 10:55:31 | 6h:23m | 3D2USU | -23 | FT8 | 20m | 14.0751 | Fiji | 3D2 | RH82RH | 12011
416 | 2022-04-08 | 10:56:27 | 6h:22m | VK2CHS | -13 | FT8 | 20m | 14.075 | Australia | VK | QF56QN | 10035
94 | 2022-04-08 | 17:03:47 | 15min | VK2HFF | -19 | FT8 | 20m | 14.0751 | Australia | VK | QF55IX | 10003
6 | 2022-04-08 | 17:16:29 | 2min | VK2BY | -18 | FT8 | 20m | 14.0751 | Australia | VK | QF56IF | 9992
212 | 2022-04-08 | 16:49:30 | 29min | VK4SC | -14 | FT8 | 20m | 14.0751 | Australia | VK | QG62OF | 9964
412 | 2022-04-08 | 11:21:27 | 5h:57m | VK4ZP | -18 | FT8 | 20m | 14.075 | Australia | VK | QG62LM78 | 9930
374 | 2022-04-08 | 13:52:29 | 3h:26m | VK3ABC | -17 | FT8 | 20m | 14.0751 | Australia | VK | QF21RW53 | 9757
421 | 2022-04-08 | 10:45:29 | 6h:33m | VK3BU | -19 | FT8 | 20m | 14.0751 | Australia | VK | QF22LF | 9703
401 | 2022-04-08 | 12:19:29 | 4h:59m | VK3IK | -13 | FT8 | 20m | 14.075 | Australia | VK | QF22LO | 9685
414 | 2022-04-08 | 11:11:31 | 6h:07m | VK5PW | -10 | FT8 | 20m | 14.075 | Australia | VK | PF95NJ | 9075
347 | 2022-04-08 | 15:18:27 | 2h:00m | VK5GR | -9 | FT8 | 20m | 14.0751 | Australia | VK | PF95ID | 9056
60 | 2022-04-08 | 17:08:30 | 10min | VK5ARG | -9 | FT8 | 20m | 14.0751 | Australia | VK | PF95IT | 9019
75 | 2022-04-08 | 17:05:30 | 13min | EA8BFK | -17 | FT8 | 20m | 14.075 | Canary Islands | EA8 | IL38BO | 8841
62 | 2022-04-08 | 17:08:30 | 10min | CT1BOH | -10 | FT8 | 20m | 14.0751 | Portugal | CT | IM58JS82 | 8163
150 | 2022-04-08 | 17:00:27 | 18min | MW7TLS | -17 | FT8 | 20m | 14.0751 | Wales | GW | IO82 | 7991
130 | 2022-04-08 | 17:00:30 | 18min | EA1ECF | -24 | FT8 | 20m | 14.0751 | Spain | EA | IN63FA | 7946
80 | 2022-04-08 | 17:05:29 | 13min | GI8GZM | -6 | FT8 | 20m | 14.0751 | Northern Ireland | GI | IO64UK | 7726
111 | 2022-04-08 | 17:02:30 | 16min | MM7CMB | -16 | FT8 | 20m | 14.0751 | Scotland | GM | IO68QI | 7726
35 | 2022-04-08 | 17:13:31 | 5min | EA4HNN | -16 | FT8 | 20m | 14.0751 | Spain | EA | IN80EN | 7660
304 | 2022-04-08 | 16:27:27 | 51min | MWØZZK | -22 | FT8 | 20m | 14.075 | Wales | GW | IO72RU | 7619
42 | 2022-04-08 | 17:12:29 | 6min | EA2BHE | -14 | FT8 | 20m | 14.0751 | Spain | EA | IN83LI | 7579
128 | 2022-04-08 | 17:00:31 | 18min | 2EØCVN | -17 | FT8 | - | 0 | England | G | IO80EM | 7568
260 | 2022-04-08 | 16:40:27 | 38min | MM3NDH | -18 | FT8 | 20m | 14.0751 | Scotland | GM | IO85IW | 7530
148 | 2022-04-08 | 17:00:27 | 18min | MØJII | -15 | FT8 | 20m | 14.0751 | England | G | IO81MD | 7518
386 | 2022-04-08 | 13:19:29 | 3h:59m | RWØIM | -15 | FT8 | 20m | 14.0752 | Russia-AS | UA9 | QO59JN | 7510
290 | 2022-04-08 | 16:28:30 | 50min | GU5WZY | -24 | FT8 | 20m | 14.0751 | Guernsey | GU | IN89RK | 7496
127 | 2022-04-08 | 17:01:27 | 17min | G3UHU | -22 | FT8 | 20m | 14.075 | England | G | IO80SO | 7485
92 | 2022-04-08 | 17:04:27 | 14min | MØXJA | -24 | FT8 | 20m | 14.0751 | England | G | IO82SQ | 7480
99 | 2022-04-08 | 17:03:30 | 15min | GØKTN | -22 | FT8 | 20m | 14.0751 | England | G | IO81TI | 7477
70 | 2022-04-08 | 17:07:32 | 11min | M1BZN | -14 | FT8 | 20m | 14.0751 | England | G | IO82TC | 7475
126 | 2022-04-08 | 17:01:27 | 17min | MØJFG | -20 | FT8 | - | 0 | England | G | IO82UC | 7470
2 | 2022-04-08 | 17:18:27 | 0min | LEE | -19 | FT8 | 20m | 14.0751 | unknown | - | IO83WM | 7456
161 | 2022-04-08 | 16:59:27 | 19min | G7KUJ | -22 | FT8 | 20m | 14.0751 | England | G | IO83WT | 7456
9 | 2022-04-08 | 17:15:31 | 3min | M7NED | -24 | FT8 | 20m | 14.0751 | England | G | IO80XS | 7455
138 | 2022-04-08 | 17:00:29 | 18min | G6VMR | -15 | FT8 | 20m | 14.0751 | England | G | IO92CM | 7435
162 | 2022-04-08 | 16:59:27 | 19min | EA5OL | -20 | FT8 | 20m | 14.0751 | Spain | EA | IM99OK50 | 7433
176 | 2022-04-08 | 16:56:30 | 22min | M3BWF | -18 | FT8 | 20m | 14.0751 | England | G | IO91DP | 7430
203 | 2022-04-08 | 16:50:29 | 28min | EA5IZO | -17 | FT8 | 20m | 14.0751 | Spain | EA | IM98QJ | 7430
90 | 2022-04-08 | 17:04:27 | 14min | MØLCS | -24 | FT8 | 20m | 14.0751 | England | G | IO91GN | 7413
46 | 2022-04-08 | 17:11:30 | 7min | G4BRK | -14 | FT8 | 20m | 14.0751 | England | G | IO91HP | 7407
96 | 2022-04-08 | 17:03:30 | 15min | MØIZM | -24 | FT8 | 20m | 14.0751 | England | G | IO92KX | 7390
151 | 2022-04-08 | 17:00:27 | 18min | M7CLO | -19 | FT8 | 20m | 14.0751 | England | G | IO93KA | 7390
209 | 2022-04-08 | 16:50:27 | 28min | G7AAY | -21 | FT8 | 20m | 14.0751 | England | G | IO92NG | 7373
22 | 2022-04-08 | 17:15:27 | 3min | MØHOM | -10 | FT8 | 20m | 14.0751 | England | G | IO93QO | 7357
36 | 2022-04-08 | 17:13:30 | 5min | G7RDX | -18 | FT8 | 20m | 14.0752 | England | G | IO91RU | 7350
172 | 2022-04-08 | 16:57:29 | 21min | 2EØFVN | -24 | FT8 | 20m | 14.0751 | England | G | IO91WP | 7321
132 | 2022-04-08 | 17:00:30 | 18min | F1DXP | -15 | FT8 | 20m | 14.0751 | France | F | JN05CU | 7305
86 | 2022-04-08 | 17:04:31 | 14min | EA6FA | -14 | FT8 | 20m | 14.0751 | Balearic Islands | EA6 | JM08RQ | 7246
114 | 2022-04-08 | 17:02:29 | 16min | F4BHK | -12 | FT8 | 20m | 14.0751 | France | F | JN08LT | 7243
423 | 2022-04-08 | 10:38:42 | 6h:40m | VK6IR | -24 | FT8 | 20m | 14.0751 | Australia | VK | OF77WJ | 7231
74 | 2022-04-08 | 17:06:27 | 12min | VK6AS | -14 | FT8 | 20m | 14.0751 | Australia | VK | OF77WW05 | 7188
367 | 2022-04-08 | 14:01:29 | 3h:17m | VK4ABW/8 | -18 | FT8 | 20m | 14.075 | Australia | VK | PH57MM | 7152
323 | 2022-04-08 | 16:16:29 | 1h:02m | DL8EX | -24 | FT8 | 20m | 14.0751 | Germany | DL | JO42 | 7122
195 | 2022-04-08 | 16:51:27 | 27min | ON4BAR | -18 | FT8 | 20m | 14.0751 | Belgium | ON | JO10RU | 7069
285 | 2022-04-08 | 16:29:29 | 49min | LA1ØØB | -24 | FT8 | 20m | 14.0751 | Norway | LA | JP20RH | 7055
178 | 2022-04-08 | 16:55:29 | 23min | LB9ZG | -17 | FT8 | 20m | 14.0751 | Norway | LA | JP20VR | 7045
16 | 2022-04-08 | 17:15:29 | 3min | PE1GCW | -24 | FT8 | 20m | 14.0751 | Netherlands | PA | JO21AK | 7032
202 | 2022-04-08 | 16:50:29 | 28min | ON4JON | -16 | FT8 | 20m | 14.075 | Belgium | ON | JO20AN | 7026
14 | 2022-04-08 | 17:15:29 | 3min | PD5JOS | -9 | FT8 | 20m | 14.075 | Netherlands | PA | JO21CW | 7024
252 | 2022-04-08 | 16:43:27 | 35min | ON7UDM | -24 | FT8 | 20m | 14.0751 | Belgium | ON | JO21BC | 7024
125 | 2022-04-08 | 17:01:28 | 17min | OZ2AFN | -24 | FT8 | 20m | 14.0751 | Denmark | OZ | JO57 | 7018
206 | 2022-04-08 | 16:50:27 | 28min | ON3PVC | -22 | FT8 | 20m | 14.0751 | Belgium | ON | JO20CX | 7017
235 | 2022-04-08 | 16:47:15 | 31min | ON3URE | -22 | FT8 | 20m | 14.0751 | Belgium | ON | JO20CW | 7017
11 | 2022-04-08 | 17:15:30 | 3min | LB8ZH | -24 | FT8 | 20m | 14.075 | Norway | LA | JP30CI | 7015
24 | 2022-04-08 | 17:15:27 | 3min | NL13951 | -24 | FT8 | 20m | 14.0751 | unknown | - | JO21EV | 7012
26 | 2022-04-08 | 17:15:26 | 3min | ZS6TAN | -18 | FT8 | 20m | 14.0751 | South Africa | ZS | KG43CW | 7007
277 | 2022-04-08 | 16:33:43 | 45min | PD1HPB | -22 | FT8 | 20m | 14.0751 | Netherlands | PA | JO22JP | 6991
336 | 2022-04-08 | 16:11:30 | 1h:07m | ZS6ZO | -18 | FT8 | 20m | 14.0748 | South Africa | ZS | KG44CE | 6989
231 | 2022-04-08 | 16:47:30 | 31min | PDØRDD | -24 | FT8 | 20m | 14.0751 | Netherlands | PA | JO22MD14 | 6969
272 | 2022-04-08 | 16:35:29 | 43min | PAØADG | -13 | FT8 | 20m | 14.0751 | Netherlands | PA | JO22NB | 6963
145 | 2022-04-08 | 17:00:27 | 18min | ON4ATW | -24 | FT8 | 20m | 14.0751 | Belgium | ON | JO20NX55 | 6953
48 | 2022-04-08 | 17:11:29 | 7min | PD2SHB | -23 | FT8 | 20m | 14.0751 | Netherlands | PA | JO21PQ | 6948
133 | 2022-04-08 | 17:00:30 | 18min | F4FSY | -14 | FT8 | 20m | 14.0751 | France | F | JN25KN | 6942
193 | 2022-04-08 | 16:51:29 | 27min | PD9BG | -22 | FT8 | 20m | 14.0751 | Netherlands | PA | JO21QP | 6942
23 | 2022-04-08 | 17:15:27 | 3min | PDØWAG | -19 | FT8 | 20m | 14.0751 | Netherlands | PA | JO21TX | 6928
89 | 2022-04-08 | 17:04:28 | 14min | LA6HNA | -20 | FT8 | 20m | 14.0751 | Norway | LA | JP53AS | 6904
120 | 2022-04-08 | 17:01:30 | 17min | PD1DMO | -15 | FT8 | 20m | 14.0751 | Netherlands | PA | JO32FI | 6875
280 | 2022-04-08 | 16:31:30 | 47min | DL7CW | -22 | FT8 | 20m | 14.075 | Germany | DL | JO31FH | 6863
261 | 2022-04-08 | 16:39:30 | 39min | DL2OAH | -17 | FT8 | 20m | 14.0751 | Germany | DL | JO31FE24 | 6862
157 | 2022-04-08 | 16:59:30 | 19min | LA5FJA | -17 | FT8 | 20m | 14.0751 | Norway | LA | JP41UP | 6860
312 | 2022-04-08 | 16:23:30 | 55min | LA7GM | -18 | FT8 | 20m | 14.0751 | Norway | LA | JP65DL | 6856
112 | 2022-04-08 | 17:02:30 | 16min | LB8PI | -14 | FT8 | 20m | 14.0751 | Norway | LA | JP53LL | 6851
189 | 2022-04-08 | 16:51:29 | 27min | PD7JLP | -24 | FT8 | 20m | 14.0751 | Netherlands | PA | JO32KQ | 6851
306 | 2022-04-08 | 16:27:27 | 51min | PA7KY | -14 | FT8 | 20m | 14.0751 | Netherlands | PA | JO32LR | 6846
247 | 2022-04-08 | 16:44:30 | 34min | DJ6JZ | -16 | FT8 | 20m | 14.0751 | Germany | DL | JO31KK37 | 6836
338 | 2022-04-08 | 15:55:27 | 1h:23m | F6BPZ | -12 | FT8 | 20m | 14.0751 | France | F | JN35DS79 | 6833
379 | 2022-04-08 | 13:45:29 | 3h:33m | LB1RJ | -22 | FT8 | 20m | 14.0751 | Norway | LA | JO49PN | 6830
375 | 2022-04-08 | 13:50:28 | 3h:28m | LA8AV | -20 | FT8 | 20m | 14.075 | Norway | LA | JO49RT | 6827
198 | 2022-04-08 | 16:50:33 | 28min | DL8DBU | -20 | FT8 | 20m | 14.0751 | Germany | DL | JO30NP22 | 6810
232 | 2022-04-08 | 16:47:29 | 31min | F4CHF | -14 | FT8 | 20m | 14.0751 | France | F | JN35HW | 6808
264 | 2022-04-08 | 16:39:29 | 39min | DK9JC | -24 | FT8 | 20m | 14.0751 | Germany | DL | JN39MF | 6801
322 | 2022-04-08 | 16:16:29 | 1h:02m | LB4NI | -23 | FT8 | 20m | 14.0751 | Norway | LA | JO49XR | 6797
242 | 2022-04-08 | 16:45:28 | 33min | DM1YS | -19 | FT8 | 20m | 14.0751 | Germany | DL | JO30PJ | 6795
223 | 2022-04-08 | 16:48:29 | 30min | DF6DBF | -15 | FT8 | 20m | 14.0751 | Germany | DL | JO31SI | 6789
3 | 2022-04-08 | 17:18:26 | 0min | LA4MIA | -7 | FT8 | 20m | 14.0751 | Norway | LA | JO59HQ81 | 6760
78 | 2022-04-08 | 17:05:29 | 13min | OZ5XE | -24 | FT8 | 20m | 14.075 | Denmark | OZ | JO47UF | 6752
229 | 2022-04-08 | 16:48:15 | 30min | DG5DH | -14 | FT8 | 20m | 14.0751 | Germany | DL | JO41DS | 6743
37 | 2022-04-08 | 17:13:29 | 5min | JF1JBO | -15 | FT8 | 20m | 14.0751 | Japan | JA | QM05FX | 6734
79 | 2022-04-08 | 17:05:29 | 13min | OZ4DCJ | -21 | FT8 | 20m | 14.0751 | Denmark | OZ | JO57BF | 6727
20 | 2022-04-08 | 17:15:27 | 3min | IW1AZF | -21 | FT8 | 20m | 14.0751 | Italy | I | JN35TC40 | 6726
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

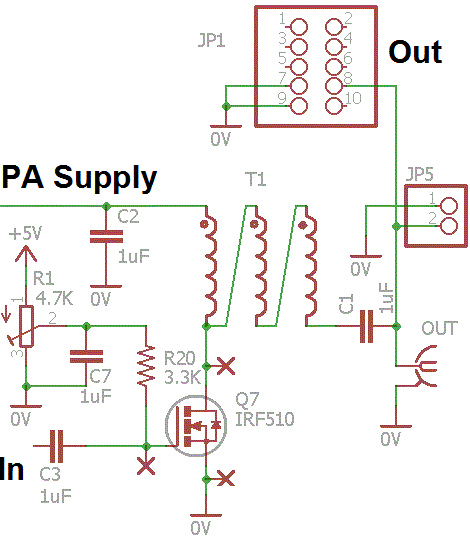
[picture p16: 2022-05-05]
Info/Simplified-PA-Schematic-2.png

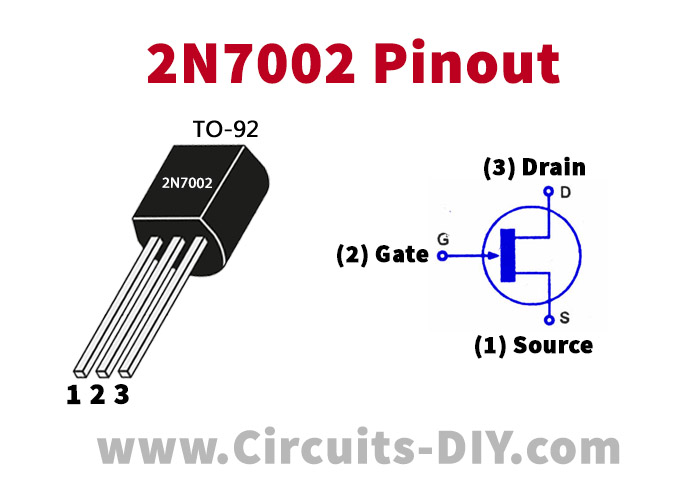
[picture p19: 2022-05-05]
datasheets/2N7002-Pinout.jpg

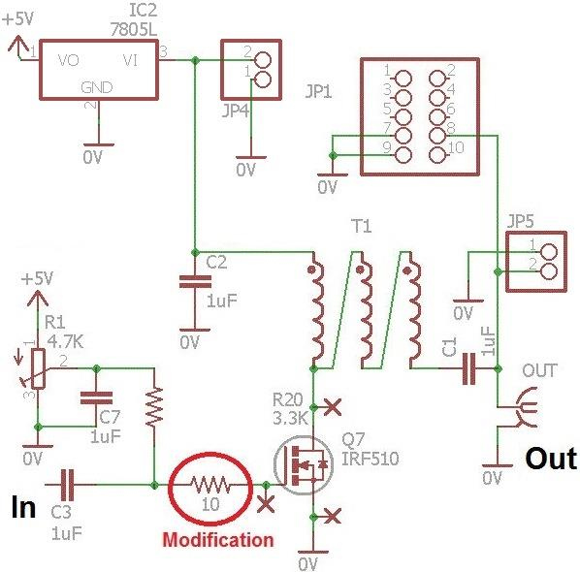
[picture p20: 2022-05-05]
Info/Simplified-PA-Schematic-1.png

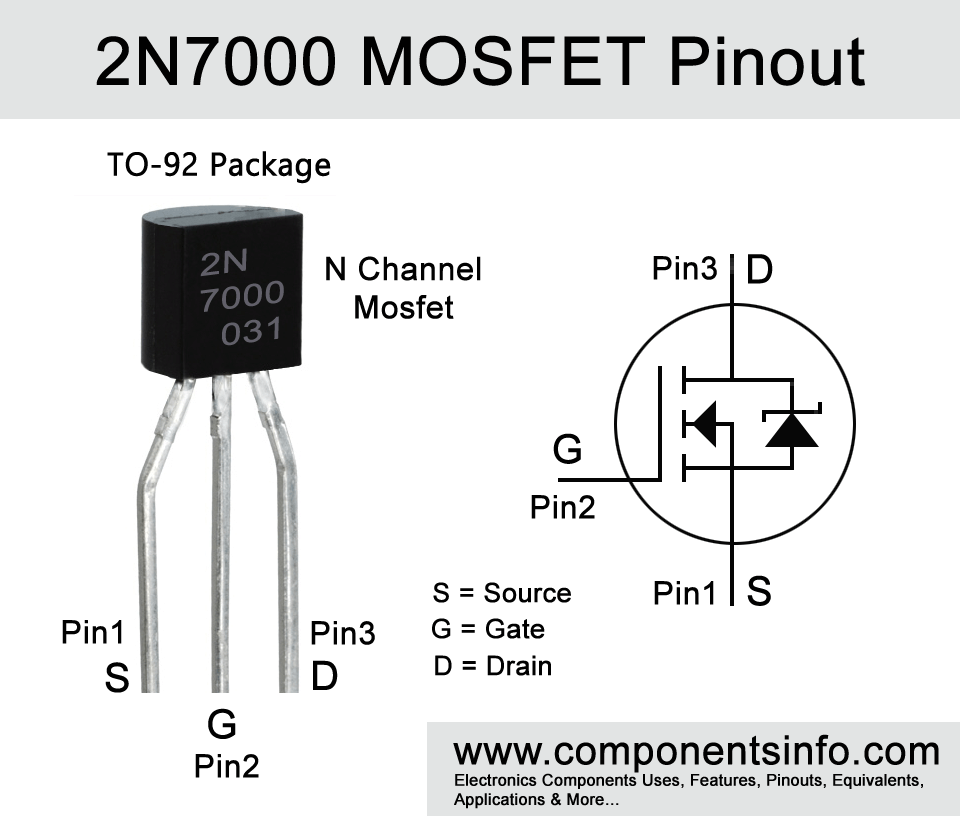
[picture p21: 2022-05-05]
datasheets/2n7000-pinout-datasheet.gif

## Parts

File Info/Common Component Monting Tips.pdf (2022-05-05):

wb5rvz.org (http://www.wb5rvz.org/common/Common_Component_Mounting)

## Common Component Monting Tips

33-41 minutes

Introduction/Contents

This page provides guidance to the builder on common components encountered Introductionbuilding the Softrock series of SDR kits. Click on the links below for techniques/tips on:

- Preparing and Installing Resistors
- Identifying and installing Ceramic Capacitors
- Installing SMT Capacitor Chips
- Installing SMT IC Chips
- Inductors-General
- Toroidal Inductors
- Coils
- Transformers
- Binocular Transformers

Resistors

The resistors are mounted with one of five orientations. The first four are the "hairpin" style, where the body of the resistor is snugged up against the board at the location indicated by the silkscreened circle and the other lead is bent into a hairpin shape and inserted into the hole pointed to by the small line on the resistor's silkscreened circle.

You can put a neat hairpin on a resistor lead by holding the resistor against a credit card and bending the lead over the top of the credit card and back down. In doing so, You want to keep the top of the hairpin as short as possible (e.g., no longer than 1/8"). See images below:

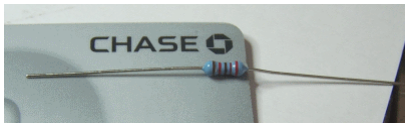
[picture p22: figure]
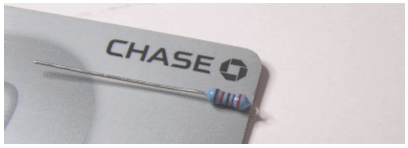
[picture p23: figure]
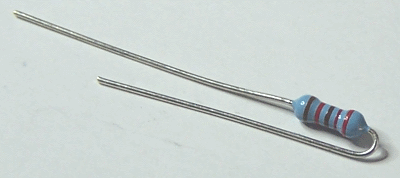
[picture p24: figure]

Hairpin resistor orientations are described in "to-from" terms, indicating the direction the hairpin is pointing in relation to the resistor's silkscreened circle. For example, "east west" means the resistor is mounted hairpin style with the hirpin lead to the west (left) of the body.

The fifth resistor orientation is "flat" ("flat-h" being horizontal and "flat-v" being vertical, with respect to the top edge of the board).

The pictures below illustrate these mounting techniques:

Orientation | Silkscreen | As Mounted

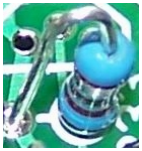
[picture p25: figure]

East-West ("E-W")

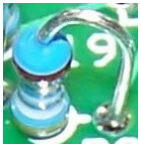
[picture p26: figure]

West-East ("W-E")

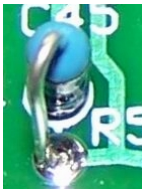
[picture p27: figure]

North-South ("N-S")

South-North ("S-N")

Flat ("flat-h" or "flat-v")

Return to top of page.

Ceramic Capacitors

If you get confused switching between pf and µF (or as we used to call them, "mmF and mF"), you can use this handy calculator. (http://www.unitconversion.org/electrostatic-capacitance/microfarads-to-picofarads-conversion.html) Values

Ceramic capacitor value codes are typically expressed as three digits where the first two digits are the significant figures of the capacitor value and the third digit indicates how many zeros to add to express the capacitor value in pF. Examples would be:

- code 471 would indicate a 470 pF capacitor code 2
- 20 would indicate a 22 pF capacitor.

Ceramic Capacitor Value

1st Digit | 2nd Digit | Multiplier Code | Multiplier | Tolerance Code | Tolerance
0 | 0 | 0 | 1 | B | ± 0.1pF
1 | 1 | 1 | 10 | C | ± 0.25pF
2 | 2 | 2 | 100 | D | ± 0.5pF
3 | 3 | 3 | 1,000 | F | ± 1%
4 | 4 | 4 | 10,000 | G | ± 2%
5 | 5 | 5 | 100,000 | H | ± 3%
6 | 6 | | | J | ± 5%

1st
Digit

2nd
Digit

Multiplier
Code
Multiplier | Tolerance
| Code

Tolerance

7 | 7 | | | K | ± 10%
8 | 8 | 8 | 0.01 | M | ± 20%
9 | 9 | 9 | 0.1 | Z | +80% / -20%

Installing the Ceramic Capacitor

- Lightly snug each capacitor as close to the board as the lead formation will allow.
- Slightly spread the capacitor leads on the bottom side of the board and solder one lead to hold the capacitor in position.
- Cut both leads flush to the bottom of the board and solder the second capacitor lead.

Return to top of page.

SMT Capacitors

Caveat: Note that the SMT caps in the Softrock kits are of two types:

Most of the kits use both types. Do not get them mixed up!

All SMT capacitor locations on Softrock kit boards are to be filled with 1206 size capacitors. You want to do your work on a cookie sheet or other "pan" with sides so, if you accidentally sneeze or otherwise "launch" one of these tiny chips, you may still have a chance of retrieving it.

Removing Caps from the Carrier

Most SMT components are supplied on a "cut tape" carrier strip from a reel of parts. This tape is normally a paper or plastic backing with a clear plastic strip on top. Tony marks the 0.1 µF strip with a black stripe for identification.

The way that works best for most builders is to somehow get a grip on the plastic strip and carefully seperate from the main strip. This will leave the exposed parts sitting in indents in the backing. Sometimes rather than just get one or two, you can take off the entire plastic strip so it won't somehow knock the rest on the floor !! The real trick is getting the plastic strip started: you can use your exacto knife or even a probe tip jabbed in the plastic. Takie care to avoid having the natural "springiness" of the carrier strip act as a slingshot that could launch the loosened chips into the air

Installation procedure is as follows for each SMT 1206 Capacitor

- Add a little solder to one pad and tack one end of a capacitor to a pad.
- Reheat and position the capacitor with the tip of the soldering iron and a toothpick.
- When the capacitor is properly positioned on its pads, solder the other end with enough solder to make a small fillet between the end of the capacitor and the pad.
- < Reheat the first end of the capacitor and add a little solder, if necessary, to make a small fillet at the tacked down end of the

capacitor.

- Excess solder may be removed with solder wick.

Leonard KC0WOX has an excellent video on installing SMT Caps. (http://golddredgervideo.com/kc0wox/softrock/surfacemountsoldering1.wmv)

Another very good video on Youtube by Steve "Soldersmoke" Weber KD1JV is viewable below:

Return to top of page. SMT ICs

SMT Integrated Circuits

Electro Static Discharge (ESD) Precautions

These ICs are very sensitive and subject to being destroyed by electrostatic discharge. You must use common-sense, protective ESD precautions when handling or working with these chips, such as:

- Avoid carpets in cool, dry areas.
- Leave PC cards and memory modules in their anti-static packaging until ready to be installed.
- Dissipate static electricity before handling any system components (PC cards, memory modules) by touching a grounded metal object, such as the recommended uncoated metal cookie sheet.
- If possible, use antistatic devices, such as wrist straps and antistatic mats (see Radio Shack's Set for $25 or the JameCo AntiStatic mat for $15)).
- Always hold a PC card or memory module by its edges. Avoid touching the contacts and components on the ICs.
- Before removing chips from insulator, put on the wrist strap connected to the ESD mat. All work with CMOS chips should be done with the wrist strap on.
- As an added precaution before first touching a chip, you should touch a finger to a grounded metal surface.
- If using a DMM, its outside should be in contact with the ground of the ESD mat, and both leads shorted to this ground before use.

Installation procedure is as follows for each Surface Mount Technology (SMT) IC:

- Orient the IC on its pads so that the pin 1 corner of the IC matches the small 1 (it also looks like a 0) mark in the copper on the bottom side of the board. In general, pin 1 of an SOIC packaged IC is in the lower left corner of the package when the printing on the package top reads upright, from left to right.
- Tack-solder one corner pin of an IC and reheat the tacked pin as necessary to line up the IC on its pads properly.
- Check the orientation of the IC and the line up of the IC on its pads with magnification and good lighting.
- If all is well, carefully solder the rest of the leads to their pads.
- Carefully and closely inspect the pins to look for bridges caused by excessive solder or debris on or around the pads.
- Use solder wick to remove any excess solder or solder bridges between IC pins.
- Using high (3x or better) magnification, carefully check each pad and solder joint.

Leonard KC0WOX has an excellent video on installing surface (http://golddredgervideo.com/kc0wox/softrock/surfacemountsoldering2.wmv)

mount ICs. (http://golddredgervideo.com/kc0wox/softrock/surfacemountsoldering2.wmv) The Sparkfun website also has some good video materials on soldering and wicking SMT ICs. (http://www.sparkfun.com/commerce/present.php?p=BEE-7-SMDSoldering)

The video below describes techniques for soldering SOIC 14 (and 16 and 8) SMDs

View the above in full-screen mode on Youtube. (http://www.youtube.com/watch?v=lauw0bSe-Cw)

Return to top of page.

Inductors - General Info

Inductors in the Softrock kits are generally wound by the builder on one of two different types of magnetic cores: Toroids or "Binoculars".

Toroidal Cores

A Toroidal core is doughnut-shaped and its color (usually either red or yellow) identifies the type of material. Toroids are typically used for coils and transformers. The toroid's component identifier is of the form "Tdd-m", where the "dd" refers to the outside diameter of the toroid in hundredths of an inch and the "m" designates the material used. Some of the more common toroids found in these kits are:

Identifier | Color | Type Material | O.D.
T25-2 | Red | 2 | 0.25"
T25-6 | Yellow | 6 | 0.25"
T30-2 | Red | 2 | 0.3"
T30-6 | Yellow | 6 | 0.3"
T37-2 | Red | 2 | 0.37"

T37-6 | Yellow | 6 | 0.37"
T50-2 | Red | 2 | 0.5"
T50-6 | Yellow | 6 | 0.5"

Binocular Cores

Binocular cores are so-called because their shape calls mind a pair of binoculars. Binocular cores are typically used for chokes and transformers. These kits use binocular cores of two types:

- BN-43-202 (http://toroids.info/BN-43-202.php)
- BN-43-2402 (http://toroids.info/BN-43-2402.php)
- BN-61-2402 (http://toroids.info/BN-61-2402.php)

If your kit calls for two different types of BN-*-2402 cores, take great care in keeping them separate and marked. The Softrock kits will always - in such case - provide the cores in separate, marked bags. DO NOT MIX THEM UP!

Preparing Binocular Cores for Winding

It is highly recommended to "debur" the holes on the binocular cores to allow for smooth insertion of the wires and avoid inadvertent shorts caused by rough edges to the holes. This can be done using a drill bit that just fits into the holes and "twirling" it between your fingers. Better still (as suggested by Iain,MW0XEN) use a mounted stone from a Dremel type tool (just held in your fingers - not powered). This leaves a very nice rounded edge to the holes.

Winding Specifications

Winding specifications provide the information on the number of windings, the role (e.g., primary or secondary) for each winding on a transformer, and the length and type of wire for the windings.

Specification Format

Winding specs will generally resemble the following:

5.0 uH 17T bifilar/34T #30 on T30-2 (red)

(19").

This can be interpreted as:

- Use a T30-2 toroid (color is red and O.D. is 0.3")
- You will need two 19" lengths of #30 wire.
- For toroids, one turn is a single pass through the center hole.
- For binocular cores, one turn is a pass in which the wire goes in the bottom, comes out the top, goes back in the other hole at the top, and comes out the other hole at the bottom.
- The transformer will have a single, 34 turn, secondary winding of 19" of #30 wire. Usually the single winiding is wound onto the core first. Winding should be evenly spaced and ideally cover all but a 15 degree "wedge" of the toroid. Sometimes, it may be necessary to wind over the top of existing turns where there is more wire than there is bare core left.
- The transformer will have two primary windings each of 17 turns of #30 wire. The term "bifilar" means to take one of the two lengths of wire, bend it at the half-point so the resultant "hairpin" is composed of the two 9.5" long halves, and then twist the two

strands together to make a "bifilar" strand with approximately 3 twists to the inch. The bifilar windings are usually wound AFTER (and over) the single strand winding. You should wait until you have wound it correctly before cutting the "hairpin" end of the bifilar strand.

- The inductance value is provided primarily to help validate the number of turns. It is the inductance of the single-strand winding.

Wires

Sometimes the various wires in the kit may be of different colors. Attach no significance to the color; recognize that when the spec calls for a #nn wire, that the "nn" is the gauge of the wire and the higher the gauge number, the thinner the wire.

See the sections below for further details on winding Toroidal and Binocular inductors.

Toroid Coils

Toroids

Identifying the toroids becomes simple once you figure out the coding. The toroids are designated using the pattern "T-NN-M". The critical pieces are the "NN", representing the outside diameter of the "donut" in hundredths of an inch, and the "M", representing the type of material used to make the core. Tony uses the following toroids in his kits:

- T30-2 (red)
- T37-2 (red)

- T25-2 (red)
- T25-6 (yellow)
- T30-6 (yellow)

Toroids are used in single-winding coils and multi-winding transformers. In either case, the number of turns must be counted. Any pass through the center of the Toroid is counted as a "turn" (see below).

Coils

The winding of a single-winding toroidal inductor is fairly straight-forward. Each pass through the center counts as a turn. The windings should be spaced evenly around the circumfrence of the toroid, ideally leaving about a 15 degree "wedge" between the beginning and ending of the winding. The image below is of a 22 turn coil wound on a toroid.

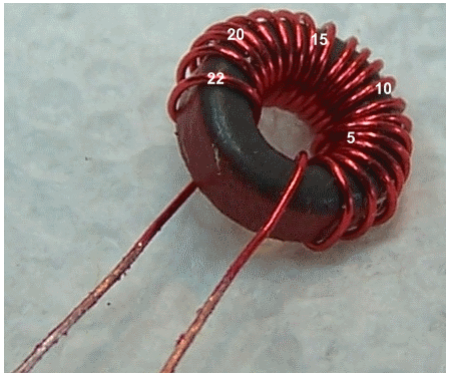
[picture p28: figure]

Occasionally, you may find that there is not enough room on the toroid to place all of the windings without having to go back and add a layer of winding. Tony Parks suggests that you overlap some turns as you put on windings around the circumference of the core so that all turns are on the core by the time you get back to the start end of the winding. This should have negligible effect on the coil's performance in the radio.

Alan Wolke, W2AEW has a very helpful 8 minute video on Youtube, showing his clever technique for winding toroidal coils using a "sawed-off" chopstick.

Alan also has another video showing how to wind a trifilar transformer of 10 turns:

Leonard, KC0WOX, also has an excellent (if large - 183 Mb!) video showing the winding (http://www.golddredgervideo.com/bitx20/torroidalinductorspart1.wmv) of a 26 turn coil on a T-37 core. While the turns andcore size in the video are not used in any of the Softrock kits, the technique is essentially the same. The actual process of winding the core begins at about 8.5 minutes into the video.

Clockwise or Counterclockwise?

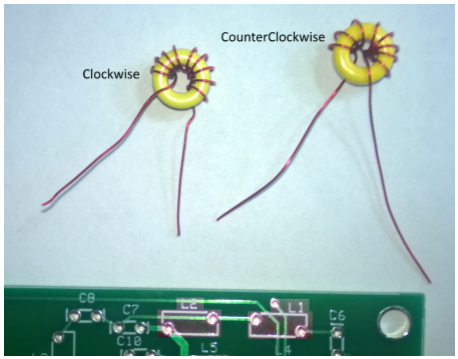
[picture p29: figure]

While the direction of winding of a toroidal coil really makes no difference so long as all windings on that core are in the same direction, it can make a difference in the physical placement of the finished coil on the circuit board. This picture shows two 10-turn coils, one wound clickwise and one wound counterclockwise. It also shows a typical circuit Board and its silkscreened coil templates. Notice how the clockwise coil will fit correctly in the holes for L2, but will have an awkward fit to the holes for L1. Similarly, notice how the counterclockwise wound coil works for the L1 slot but only awkwardly for the L2 slot. If you wish to have your coils line up like the designer intended, you need to pay attention to the silkscreen slots and the hole positions, mentally trying to place a clockwise-wound coil vs. a counterclockwise-wound one into the slot. You can use these

rules of thumb:

- If the coil template is horizontal and the left-hand hole is at the lower left, wind clockwise
- If the coil template is horizontal and the left-hand hole is at the upper left, wind counter clockwise
- If the coil template is vertical and the top hole is on the left, wind clockwise
- If the coil template is vertical and the top hole is on the right, wind counterclockwise

Toroidal Transformers

Winding toroidal transformers usually involves 2 to 3 windings on the same core. The most common is a transformer with a single winding (primary or secondary) over which two "bifilar" windings are superimposed (two secondaries or primaries). See the Toroid Winding Hints from the Experts (http://www.wb5rvz.org/common/ToroidWindingHints.htm) for good tips on how to wind a toroidal transformer.

In general the transformer outlines on the circuit boards, 4 hole or 6 hole patterns, correspond to the shape of the core involved. The silkscreen lines between opposing hole pairs correspond to the connections for one winding. All that is needed is to connect the leads from one side of the core, or one hole of the core in the case of the binocular cores, to the holes on one side of the pattern the the leads from the other side of the core, or other hole of a binocular core, to the holes on the other side of the pattern. Secondary and primary leads need to be sorted out

properly.

When you have finished winding, stripping, and tinning the toroidal transformer's windings, you will two leads for each winding. Each lead will come out on a different side of the toroid. For example, consider a three-winding transformer with one primary ("P") and two secondary windings ("S1" and "S2"). It will have a total of six leads, three on one side of the toroid and three on the opposite side:

- The two primary leads, "Pa" and "Pb" ("P" stands for primary; "a" is one side of the toroid, "b" is the opposite side)
- The two leads for the 1st secondary winding, "S1a" and "S1b" ("S1" stands for the 1st secondary winding; "a" is one side of the toroid, "b" is the opposite side)
- The two leads for the 2nd secondary winding, "S2a" and "S2b" ("S2" stands for the 2nd secondary winding; "a" is one side of the toroid, "b" is the opposite side)

•


To mount the transformer you insert the leads into the holes annotated on the board as "P", "S1", and "S2". The holes may also be annotated as to the "row" ("a" row or "b" row) which corresponds to the leads on the "a" side or the "b" side of the toroid.

the builder should start with the single winding, inserting its two leads into the appropriate holes and then do the same with the first of the two bifilar windings, and finally do the same with the second of the two bifilar windings

After inserting the leads, the builder should pull each lead pair through the holesuntil the transformer is snug to the board. Soldering the leads completes the process.

Leonard, KC0WOX, has an excellent (large - 100+ Mb!) video showing the winding and mounting of a bifilar transformer (http://www.golddredgervideo.com/kc0wox/softrock/softrockt4.wmv) on an earlier Softrock (transceiver) kit. He also has a 2 minute video clarifying how bifilar transformers are mounted on Softrock boards. (http://golddredgervideo.com/kc0wox/softrock/t4winding.wmv)

Return to top of page.

Binocular Transformers

Debur the Core Before Winding

Binocular cores

Winding and Installing transformers on binocular cores is a hard process to clearly describe. There are two aspects to it.

- One is the actual winding of the coil. Bino cores can be wound either:
- with all leads coming out of the same end or
- with some leads coming out of one end and some coming out of the other.
- All Tony's kits - so far - have used the winding convention where all windings come out of one end of the binocular core, with one turn counted each time the wire goes in one hole and comes out the other, at the same end (see below).

•


- The other aspect is the correct polarity. That is a little easier, since Tony has designed the boards such that the polarity is pretty well handled for you.
- The key is to start each winding in the same hole of the bino core and end each winding in the other hole (on the same end of the core).
- When you finish winding the typical bino transformer with one single wire winding and one bifilar (i.e., twisted pair of wires) wire winding (yielding two windings), you have three wires coming out of each hole on the same end of the core, corresponding to the leads of the three windings.
- You should carefully strip the insulation from the leads (up to within an eighth of an inck of the core) and tin the leads. Sandpaper can be used to strip the insulation, or you can use an Exacto kinfe to scrape it off. Note that the insulation on the wire Tony provides is normally the heat-strippable type (which you can strip by repeatedly pulling the wire end through a HOT solder blob on the iron tip)..
- In most of Tony's kits the core is mounted "standing up"

vertically and the windings' lead pairs are inserted into the holes corresponding to the winding.

- For example, if you wind a transformer with one primary (P) and two secondary windings (S1 and S2), you end up with three leads (Pa, S1a and S2a) coming out of one hole and three leads (Pb, S1b, and S2b) coming out of the other hole.
- The board layout in the enhanced builders notes will usually have annotations on the six holes (for a common transformer) that indicate the lead pairs for the primary, and each of the 2 secondaries.
- The builder then needs to match the holes with the appropriate winding leads. This graphic is an example:

•


- T201 (above) has one primary and two secondary windings. When wound, it will have 6 leads in all:
- two leads (Pa and Pb) and
- four secondary leads (S1a, S2a, S1b, S2a).


•

- You should use an ohmmeter to identify each winding pair.

Then slip a 1/8" pice of hookup wire insulation onto the Pa and Pb leads to temporarily provide identification of the primary. Also slip a 1/8" piece of insulation onto the S1a and S1b leads to act as a "spacer for the actual mounting.

- To mount the core, the builder typically starts with the Primary leads, removing the insulation piece and orienting the core such that (in the above instance):
- the core hole from which Pa lead exits is aligned with the P hole on the top row of the holes and
- the core hole from which the Pb lead exits is aligned with the P hole on the bottom row.
- Then insert those primary leads into their corresponding holes.
- Then take the first pair of S leads (e.g., S1a and S1b) and similarly align with and insert into the "S1" holes (S1a on the top and S1v on the bottom row of holes in the graphic above).
- Finally do the same thing with the remaining lead pair (S2a and S2b).
- Then pull through all of the leads from the bottom of the board to ensure no leads have any loose ends or loops topside and the transformer is nice and snug on the board and the 1/8" spacer
- Solder all leads and you're ready to test them.

Return to top of page.

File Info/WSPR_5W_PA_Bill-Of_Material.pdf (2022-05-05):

Sheet1

# 5W PA for WSPR Ultimate

vk3pe | Feb-16

"0805-1206" means most footprints can be fitted, 0805 preffered though

Part Type | Designator | Footprint | Description | Notes
1.09uH | L1 | T50_TOROID | Inductor | for 30M band (refer to Ultimate web page for other band values)
1.09uH | L2 | T50_TOROID | Inductor | for 30M band (refer to Ultimate web page for other band values)
1.257uH | L3 | T50_TOROID | Inductor | for 30M band (refer to Ultimate web page for other band values)
270pF | C17 | 0805-1206 | Capacitor | for 30M band (refer to Ultimate web page for other band values)
270pF | C16 | 0805-1206 | Capacitor | for 30M band (refer to Ultimate web page for other band values)
560pF | C14 | 0805-1206 | Capacitor | for 30M band (refer to Ultimate web page for other band values)
560pF | C15 | 0805-1206 | Capacitor | for 30M band (refer to Ultimate web page for other band values)
100K | R5 | 0805-1206 | RES FIXED
100nF | C6 | 0805-1206 | Capacitor
100nF | C5 | 0805-1206 | Capacitor
100nF | C4 | 0805-1206 | Capacitor
100nF | C11 | 0805-1206 | Capacitor
100nF | C7 | 0805-1206 | Capacitor
100nF | C8 | 0805-1206 | Capacitor
100nF | C9 | 0805-1206 | Capacitor
100nF | C10 | 0805-1206 | Capacitor
100nF | C2 | 0805-1206 | Capacitor
100nF | C3 | 0805-1206 | Capacitor
10K | R3 | 0805-1206 | RES FIXED
10K | R2 | 0805-1206 | RES FIXED
10K | R4 | 0805-1206 | RES FIXED
10R | R7 | 0805-1206 | RES FIXED

Page 1

Sheet1

10uF/16V | C12 | ccase | polarized cap
180R | R10 | 0805-1206 | RES FIXED
180R | R8 | 0805-1206 | RES FIXED
1K | RV1 | trim-pot | POTENTIOMETER
1N4001 | D1 | axial0.5 | Diode
1nF | C1 | 0805-1206 | Capacitor
22uF/16v | C13 | ccase | polarized cap
270R | R6 | 0805-1206 | RES FIXED
2N7000 | Q1 | TO-92B | FET
33R | R9 | 0805-1206 | RES FIXED
4K7 | R1 | 0805-1206 | RES FIXED
78L05 | U1 | to-92a | Regulator IC
BN43-202 | T1 | BALUN | balun core
NDT2955 | Q2 | SOT-223 | FET
RD16HHF1 | Q3 | TO-220 | FET

Page 2

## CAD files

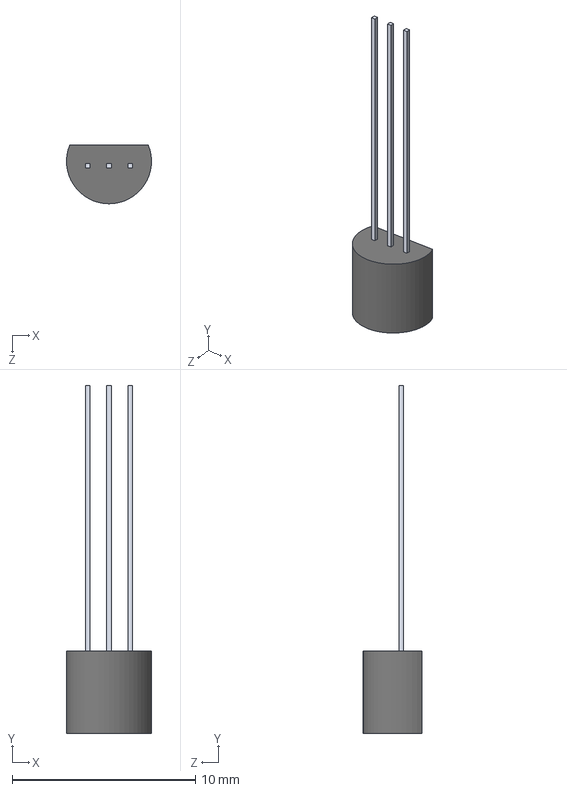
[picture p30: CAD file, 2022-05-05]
HF-PA-Blocks/models/Transistor_TO-92_Type.STEP
4.64 x 19.0 x 3.20 mm

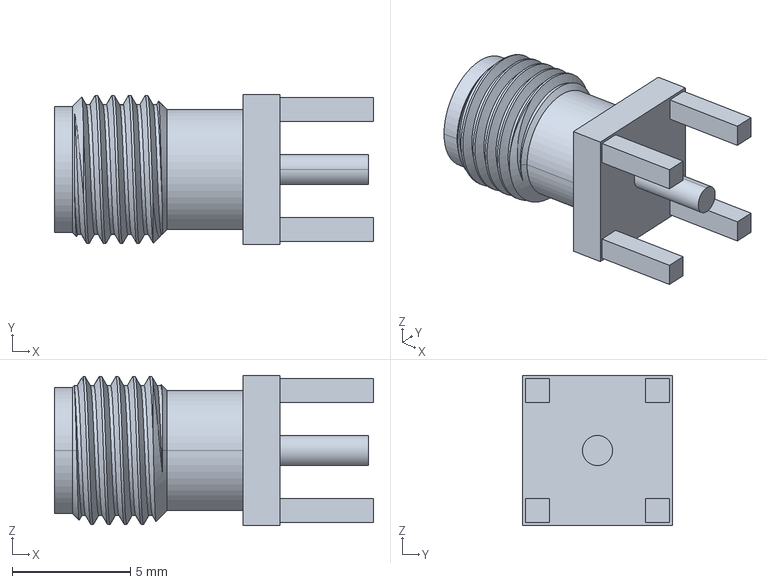
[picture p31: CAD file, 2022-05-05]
HF-PA-Combined/models/901-144.stp
13.5 x 6.35 x 6.35 mm

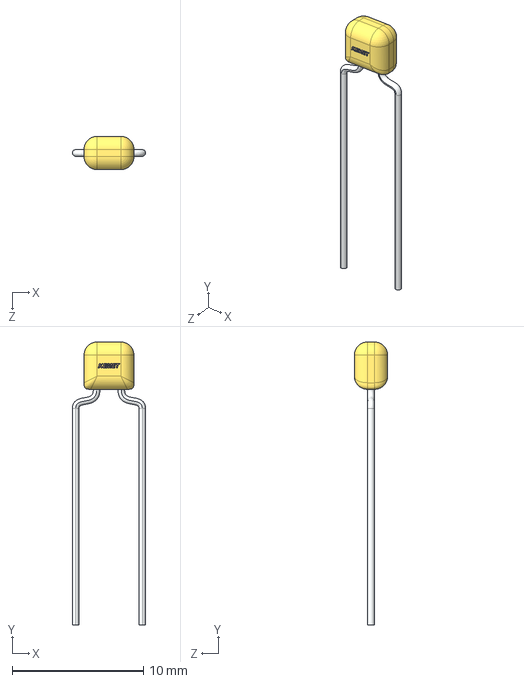
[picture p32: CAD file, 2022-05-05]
HF-PA-Blocks/models/C317C104K1R5TA7301.step
5.59 x 21.6 x 2.54 mm

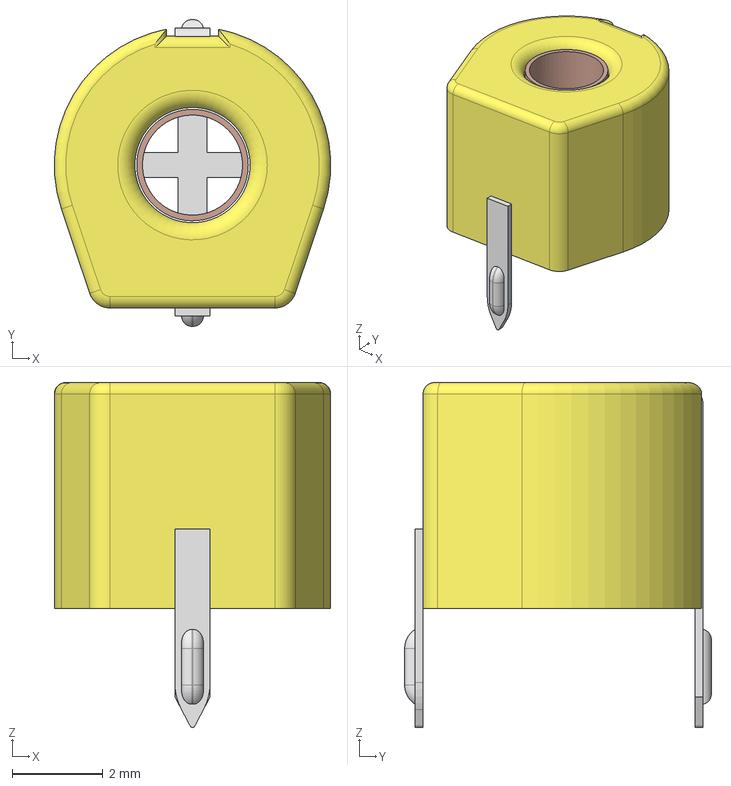
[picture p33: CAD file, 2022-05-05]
HF-PA-Blocks/models/Trimmer Cap - Yellow.stp
6.09 x 6.76 x 7.61 mm

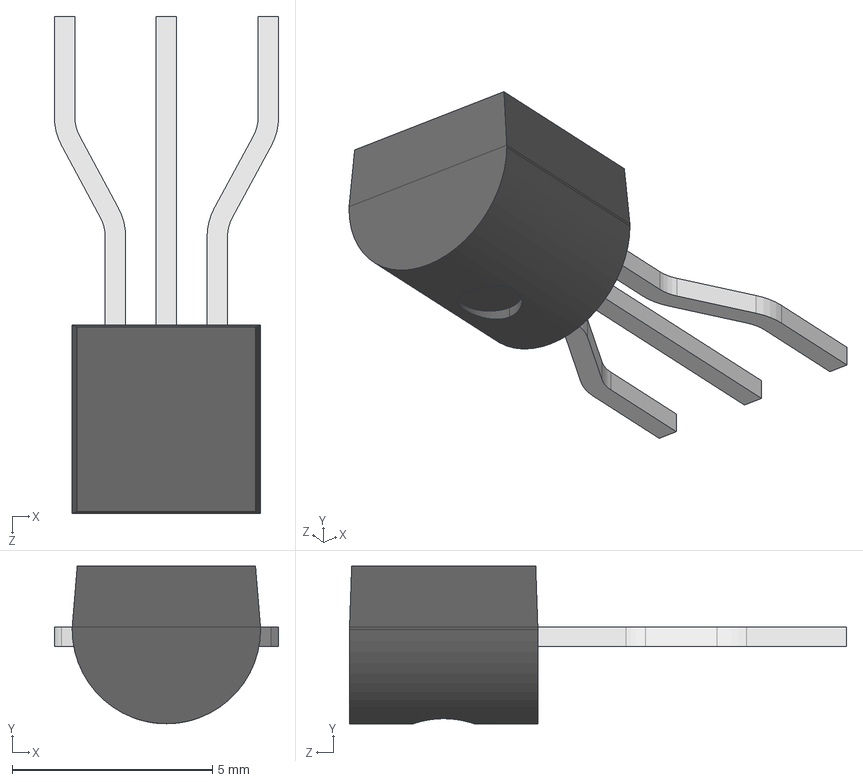
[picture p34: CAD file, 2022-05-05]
HF-PA-Combined/models/User Library-TO-92-2_54-line.STEP
5.60 x 3.93 x 12.4 mm
User Library-TO-92 Version2_TO-92 Part1
User Library-TO-92 Version2_TO-92 Part3
User Library-TO-92 Version2_TO-92 Part4
User Library-TO-92 Version2_TO-92 Part5

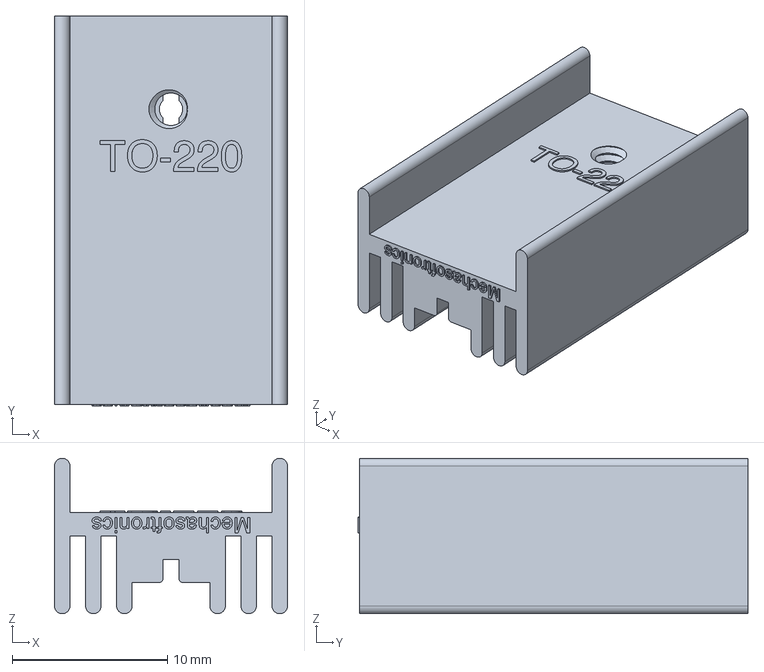
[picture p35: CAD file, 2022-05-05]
HF-PA-Blocks/models/heatsink_to-220.stp
15.0 x 25.1 x 10.0 mm

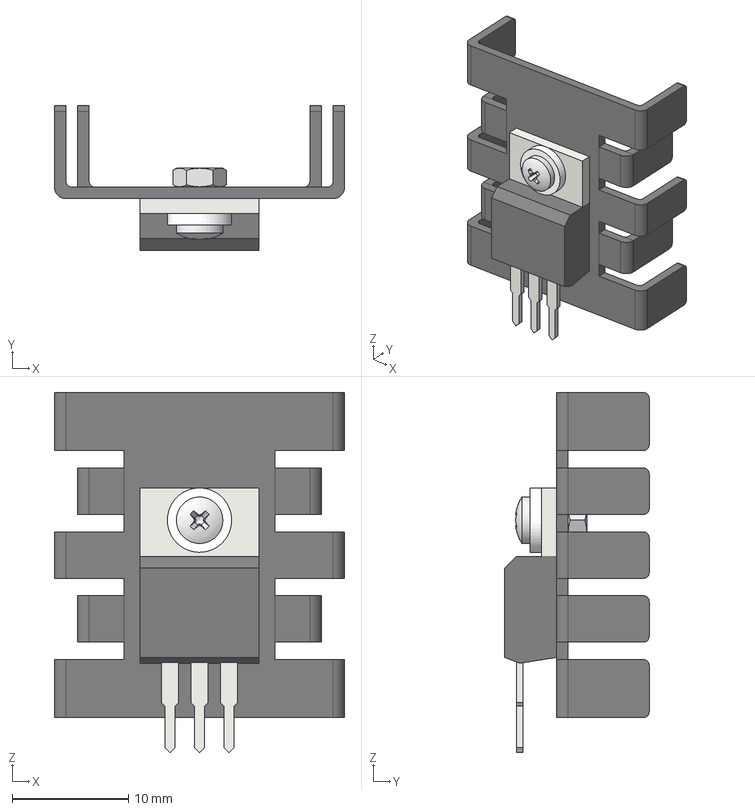
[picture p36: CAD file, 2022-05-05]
HF-PA-Combined/models/Heatsink TO-220 28x25x8mm.stp
25.0 x 12.4 x 31.0 mm
TO-220_3_Vertical
Isolator
Screw
Nut
Heatsink_28x25x8mm

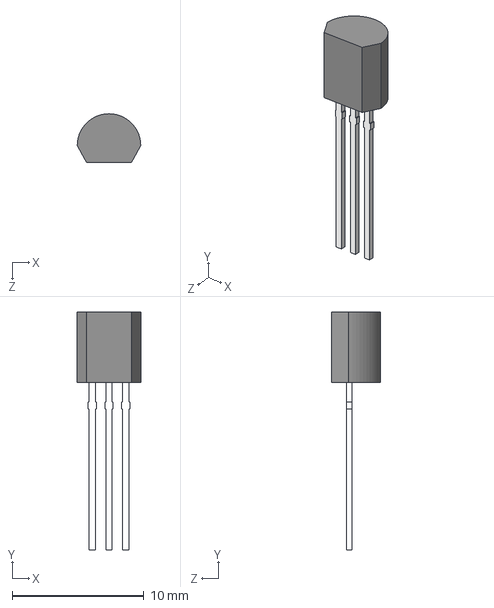
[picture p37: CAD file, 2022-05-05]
HF-PA-Blocks/models/LM78L05ACZ_NOPB.step
4.83 x 18.0 x 3.68 mm

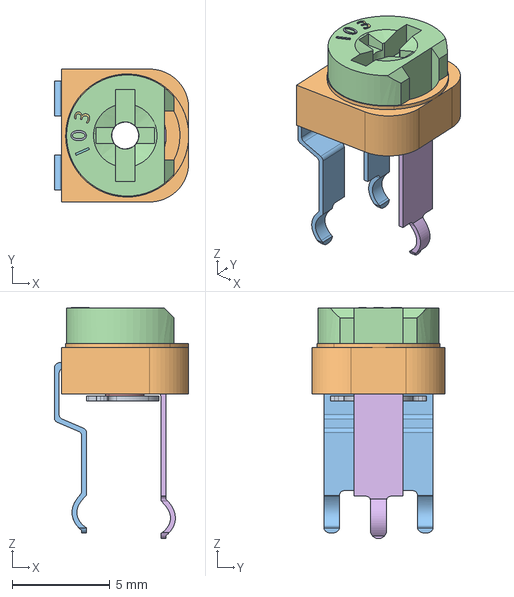
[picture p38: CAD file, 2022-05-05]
HF-PA-Blocks/models/Poti_10kohm.stp
6.88 x 6.80 x 11.8 mm

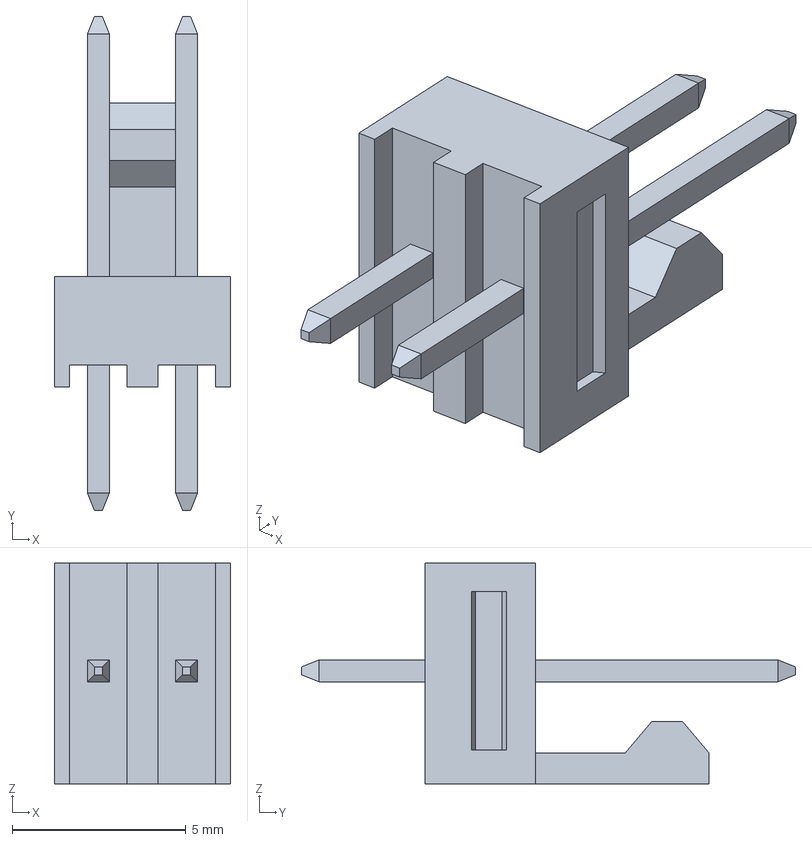
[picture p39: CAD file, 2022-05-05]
HF-PA-Blocks/models/22-23-2021.stp
5.08 x 14.2 x 6.35 mm

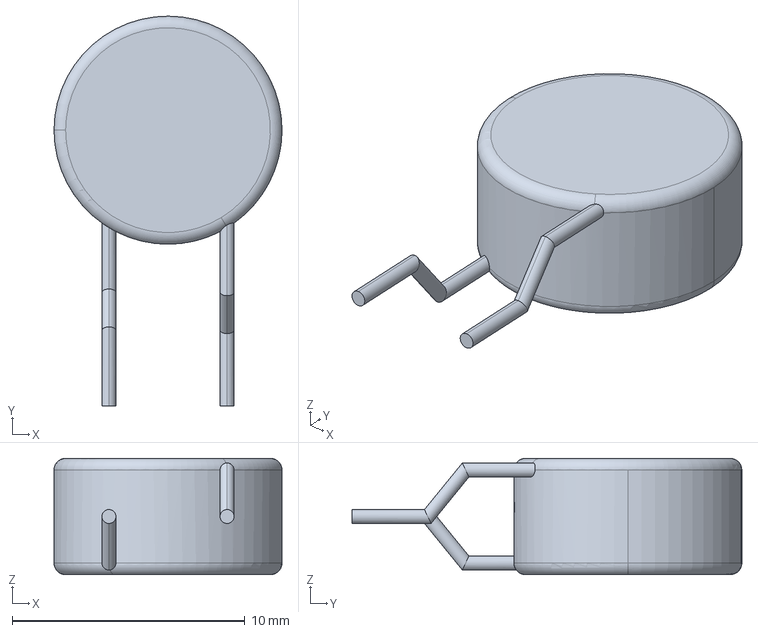
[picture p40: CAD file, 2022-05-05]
HF-PA-Blocks/models/cmf-rl35.stp
9.80 x 16.8 x 5.00 mm

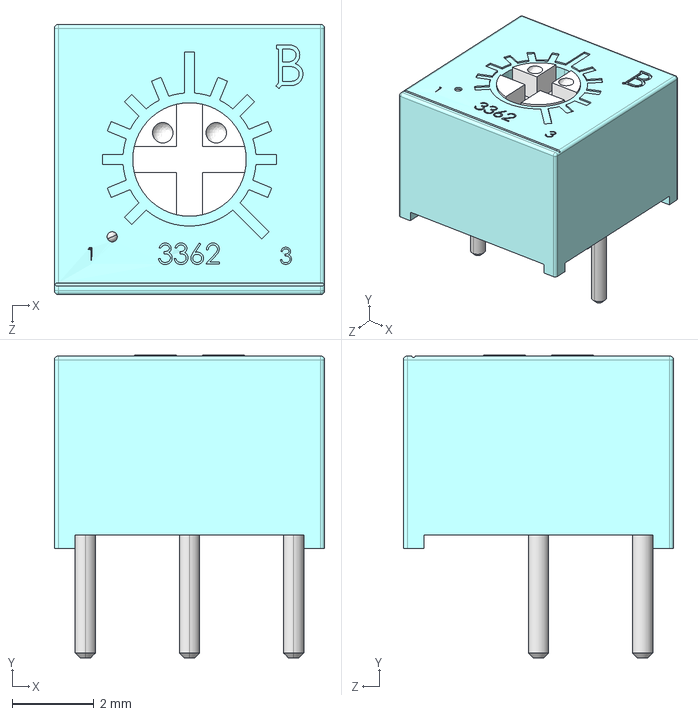
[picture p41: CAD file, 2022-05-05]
HF-PA-Combined/models/3362P-1-102LF.STEP
6.60 x 7.40 x 6.60 mm

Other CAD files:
HF-PA-Combined/models/Trimmer Cap - Green.stp
HF-PA-Blocks/models/Trimmer Cap - Green.stp
HF-PA-Blocks/models/577102B00000.STEP
HF-PA-Blocks/models/DC inductor.stl
HF-PA-Blocks/models/LM7805CT_NOPB.step
HF-PA-Blocks/models/R125.426.000 D.STEP
HF-PA-Blocks/models/c-221789-1-e-3d.stp
HF-PA-Combined/models/577102B00000.STEP
HF-PA-Combined/models/DC inductor.stl
HF-PA-Combined/models/LM7805CT_NOPB.step
HF-PA-Combined/models/R125.426.000 D.STEP
HF-PA-Combined/models/c-221789-1-e-3d.stp

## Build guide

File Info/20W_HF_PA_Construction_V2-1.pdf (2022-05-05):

Version date 03-04-06

## G6ALU 20W FET PA – Construction Information

The requirement
This amplifier was designed specifically to complement the Pic-A-Star transceiver developed by Peter Rhodes G3XJP. From the band pass filter an output of approximately –10dBm can be obtained, this requires amplifying to a useable power level to be of use. Although developed for a specific application the design presented here is flexible enough to be used with any low level HF signal source. Adjustment of the attenuator value and possible removal of the first stage can accommodate a higher input power.
Circuit description
A 3 stage topology has been used requiring a nominal input of –13dBm (0.05mW) for an output of 20W at 1.8MHz falling to 16W at 30MHz (typically 25W on 80M). Typical current consumption is 2.7Amps @ 13.8V, giving a stage efficiency of 53% at 20W output.

Field effect transistors have been used for the power stages, these are low cost and have so far proven to be very robust. One failure mode that must be looked out for is excessive device dissipation; ensure that the gate is not left “floating”. If for any reason there isn’t a DC connection the gate may rise in voltage and turn the device on drawing excessive current leading to device failure. The devices used here are in a TO220 package which differ from switching devices in that the tab is connected to the source electrode, so in this design are grounded by the PCB and heat sink. No insulating washers are used when bolting the devices down to the heat sink and PCB.

To ensure a good match to the band pass filters a 5dB attenuator has been incorporated before Q1, this is required as the input impedance will vary with frequency. When used with the Pic A Star any additional attenuation required should be placed in the IF stage – refer to the STAR “Set up information” document.

The first gain stage follows the input attenuator, this is a simple common emitter bipolar circuit using emitter feedback, the gain of which is set by the load impedance of T2 (200 Ohms) and that of emitter resistor R8 (33 Ohms). These components set the voltage gain at about 8 or 18dB power gain.

Stage 2 comprises of two field effect transistors (FETs), as previously stated no negative feedback is provided giving a stage gain of about 23dB, providing ¼ watt of drive to the output stage. FETs are broadband devices, if driven from a constant voltage source their output can be expected to be flat across the HF band. Unfortunately FETs have a relatively high input capacitance, in the case of the RD06HHF1s used here it is about 27pF giving a capacitive reactance of 196 Ohms @ 30Mhz. Rather than trying to provide a broad-band match to this reactance it is simpler just to load the gate with a resistor of much smaller value, this does of course limit the stage gain but to me 23dB is still quite adequate! Q2 and Q3 gates are loaded with 100R resistors, these also provide a DC path for the bias voltage.

Matched device pairs haven’t been used so separate gate bias is provided for each device, this bias is provided from a common source; ZD1 a 5.6 volt zener diode in series with D1 giving some temperature compensation. The driver transistors are running with a quiescent current set at 125mA each, gate load resistors R10 and R11 are decoupled to ground via C9 and C10 so T2 “sees” a total load of 200 Ohms. The output load of Q2 and Q3 is provided by a centre-tapped transformer wound on a BN43-1502 or Epcos B62152A4X1 type core. As the two types have different AL values, different winding instructions are given for each.

The output stage is very similar to that of the driver having a gain of about 21dB, the main difference being with the output transformer arrangement and gate load resistors. This transformer consists of two cores, the primary of each are connected in series and the outputs in parallel, this arrangement ensures that both transistor drains are tightly coupled in anti-phase so giving good even harmonic suppression. The quiescent current of each transistor is set to 250mA.
Construction
The PCB has been designed to have a continuous ground plane on the underside with connecting tracks on the top. To enable a PCB to be manufactured using your preferred method I have included a reversed positive plot of the top side, when plotting ensure that Acrobat isn’t resizing the plot for you by checking with the 100mm reference provided.

As they are easier to apply and have lower parasitic inductance, surface mount capacitors have been used where practical, in addition all transformers are surface mounted. Other components are leaded types and pass through the PCB, note that anywhere a grounded lead passes through the PCB it should be soldered top and bottom, in addition there are 6 through board links that need soldering both sides. All non-grounded leads which pass through the board should have the ground plane relieved on the underside.

Transformer winding - All transformers are simple to wind, wire diameter for transformers T1 and T2 isn’t critical. For T3 don’t be tempted to greatly increase the diameter of wire although the core holes would allow it, using a wire significantly thicker increases its self capacitance affecting the transformer wide band performance.

The one turn primary of T4 and T5 can be made from a piece of braid removed from RG58 or similar coax, for the secondary winding use PVC covered hook up wire. Use the heaviest type that will pass through the cores.

As previously noted no insulating washers are used between the heat sink, transistors and PCB. A direct ground connection must be made between the PCB and heat sink, grounding for the Fets is mainly made via their tabs. Two options are provided for output HF compensation, the low cost route is to use two 1nF surface mount ceramic capacitors but due to their questionable suitability (due to max current handling) provision has been made for a 2n2 silver mica part. So far though there are no reported failings of ceramic capacitors, the choice is yours.

The following pictures are of the prototype, some component positions have changed with the published version.

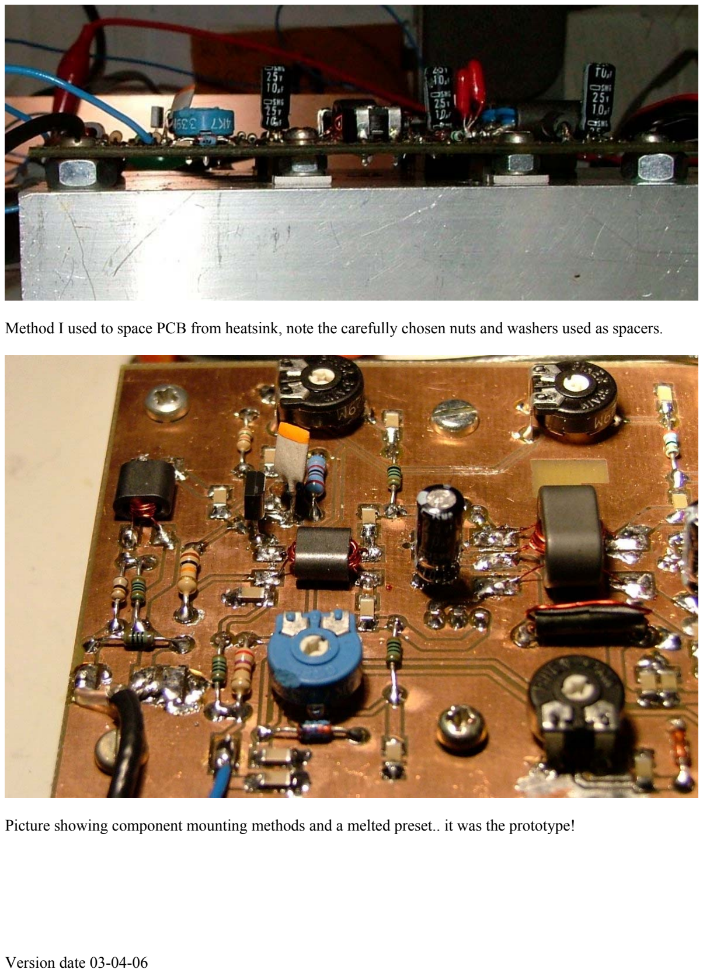
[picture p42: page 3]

Method I used to space PCB from heatsink, note the carefully chosen nuts and washers used as spacers.

Picture showing component mounting methods and a melted preset.. it was the prototype!

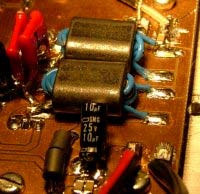
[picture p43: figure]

Output transformer mounting detail.

Testing and alignment
Before applying power check and make sure there are no bridges between any pads and the ground plane. Turn all bias presets anticlockwise (lowest bias voltage). Momentarily apply a supply to the 13V8 terminal and check current drawn is practically zero; C28 will draw initial charging current.

Apply supply to the Bias input and separately to the 13V8 input via an ammeter capable of reading 1 Amp, connect a power meter and 50-Ohm dummy load to the output. Adjust VR1 for a quiescent current of 125mA, VR2 for an increase of 125mA (250mA total), VR3 for an increase of 250mA (500mA total) and finally VR4 for another 250mA increase giving 750mA total quiescent current. Bias adjustment will be sensitive but actual values achieved aren’t critical. At this stage there shouldn’t be any RF power appearing at the dummy load!

Disconnect power, attach to the band pass filter transmit output of the STAR and apply power. Select 80M and adjust the drive level to a low level, with key down slowly increase the drive and monitor the output level. If an oscilloscope is available monitor the output waveform, it should be easy to achieve an output of 20W on 80M before the output becomes distorted. Repeat drive adjustment for all bands.
In Use
Note that the input and output circuits are “floating”, in normal use the coaxial screen connection will be linked to the PCB ground pad. This facility has been provided for situations where a specific cabinet construction generates a ground loop, a floating input or output may “break” the loop.

No output filter is provided, the amplifier still has considerable gain in to the VHF region so must be used with an effective low pass filter, typically the second harmonic is 40dB down on carrier but third harmonic only 25dB down.

When used with a STAR the bias supply is provided directly by the timer board (12V Tx PA bias) and 13V8 terminal left permanently connected to supply, the transistors were developed for use in mobile equipment so can be safely supplied with higher than the normal shack voltage of 13.8V. For an increase in output up to 14.5V may be used safely.

Component Sources
Q1 is specified as a ZTX327 or ZTX313, both of which are now obsolete! An alternative may be the MPSH10 or indeed any other RF transistor of suitable current and frequency rating, watch the pin outs though and adjust C3 to compensate the HF end of band.

The FET devices were obtained from European Microwave Components, contact details:

European Microwave Components Ltd.
36 Priors Way Business Park,
Coggeshall,
Essex.
United Kingdom.
CO6 1TW

Web http://www.emc.uk.com and email sales@emc.uk.com , note that their minimum order charge before VAT is £25, the value of transistors used in this design total about £8.00!

Ferrite cores can be obtained from any of the normal vendors; no doubt substitutions can be made especially with T1 – T3 whose characteristics aren’t critical.

Change log:
28-04-05 | Corrected input power requirements following robustness test
| Changed harmonic output level
| Added note about PCB grounding
| Added note on through board links
| Added notes on transformer construction
02-05-05 | Corrected value of C3 in parts list to 220pF
03-04-06 | Input attenuator changed from 10dB to 5dB, additional attenuation now placed in IF stage.
| R2 and R3 were 100R, now 180R. R1 was 68R now 27R

Quantity | Component reference | Description | Notes | Function
23 | C1, 2, 4, 5, 6, 7, 8, 9, 10, 12, 13, 14, 15, 16, 17, 18, 20, 21, 22, 23, 24, 26, 27 | 100nF 1206 SM | | Coupling - decoupling
3 | C11, 19, 28 | 10uF 25V PC electrolytic | | LF decoupling
1 | C25 | 330pF Silver Mica > 100V | Can be made up of multiple capacitors | HF frequency compensation of T4 & T5
2 | C29, 30 | 1nF 1206 SM | Not used if C31 fitted, see text | LF frequency compensation for T4 & T5
1 | C3 | 220pF 1206 SM | | HF peaking for Q1
1 | C31 | 2200pF Silver Mica | Not used if C29 & 30 fitted, see text | LF frequency compensation for T4 & T5
1 | D1 | 1N4148 | Partial temperature compensation for bias supply
1 | ZD1 | 5V6 400mW | Bias voltage regulation
1 | Q1 | ZTX313, ZTX327 | | First stage amplification
2 | Q2, Q3 | RD06HHF1 | See text | Second stage amplification
2 | Q4, Q5 | RD16HHF1 | See text | Third stage amplification
3 | R5, R10, R11 | 100R | | R5 decoupling, R10 & R11 load for 1st stage amplifier and gate reactance swamp resistors
3 | R1, R12, R13 | 27R | | R1 part of input attenuator. R12, 13 Gate reactance swamping resistors for Q4 and 5
1 | R4 | 10K | | Part of Q1 bias
1 | R6 | 1K5 | | Part of Q1 bias
1 | R7 | 270R | Resistor will dissipate about 0.3W so miniature 0.6W MF recommended | Series resistor for FET bias supply
2 | R2, R3 | 180R | | Input attenuator
1 | R8 | 33R | | Q1 gain setting
1 | R9 | 82R | | Q1 emitter resistor
| | | Unless otherwise stated all resistors 1/8 watt or higher , 5% tolerance or better
4 | VR1, VR2, VR3, VR4

2K2 Horizontal
preset | Q3-6 gate bias setting
1 | L1 | 2* type 43 beads | 2 passes of 0.25mm enamelled copper wire through 2 type 43 beads - see photos | Supply decoupling
1 | L2 | 2* type 43 beads | 1 pass of 1.25mm tinned copper wire through 2 type 43 beads -see photos | Supply decoupling
1 | T1 | BN43-2402 | Primary 3 turns, secondary 6 turns of 0.25mm enamelled copper wire wound on to BN43-2402 core
1 | T2 | BN43-2402 | Primary 6 turns, secondary 4 turns of 0.25mm enamelled copper wire wound on to BN43-2402 core
1 | T3 | BN43-1502 or Siemens (Epcos) B62152A4X1 | Primary 8 turns centre tapped (I.E. 4+4), secondary 4 turns 0.25mm enamelled copper wire wound on type BN43-1502 or for Epcos B62152A4X1 core, 12 turns centre tapped primary with 6 turn secondary.
2 | T4, T5 | BN43-202 | Primary 1 turn of braid removed from RG58 cable or similar, secondary 4 turns of PVC covered hook up wire wound on BN43-202 core - see photo.

### 20W HF PA Component list

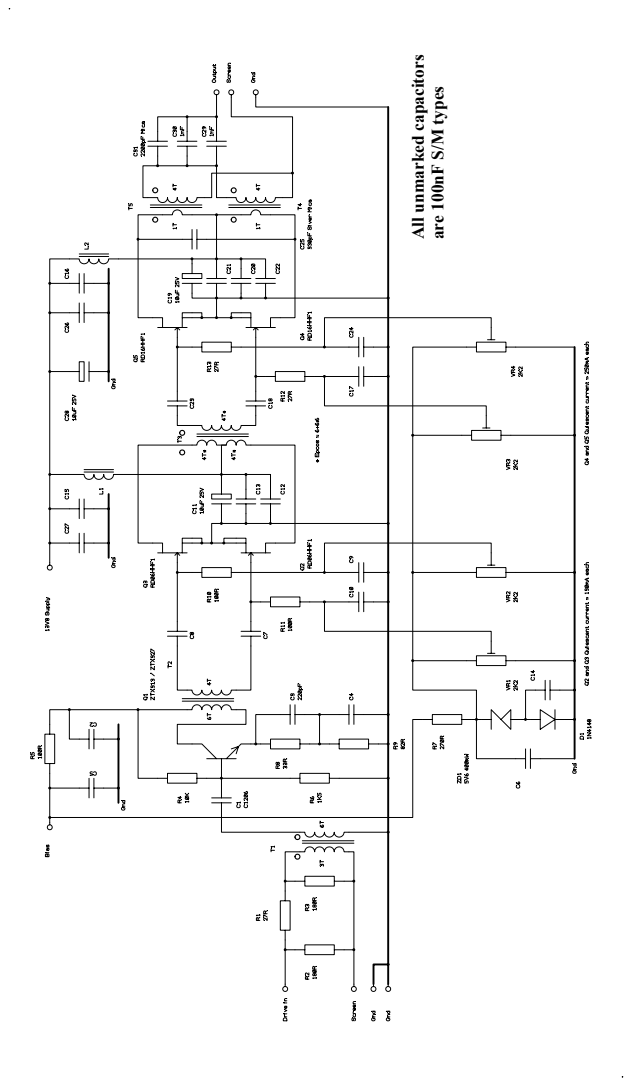
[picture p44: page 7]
are 100nF S/M types

All unmarked capacitors

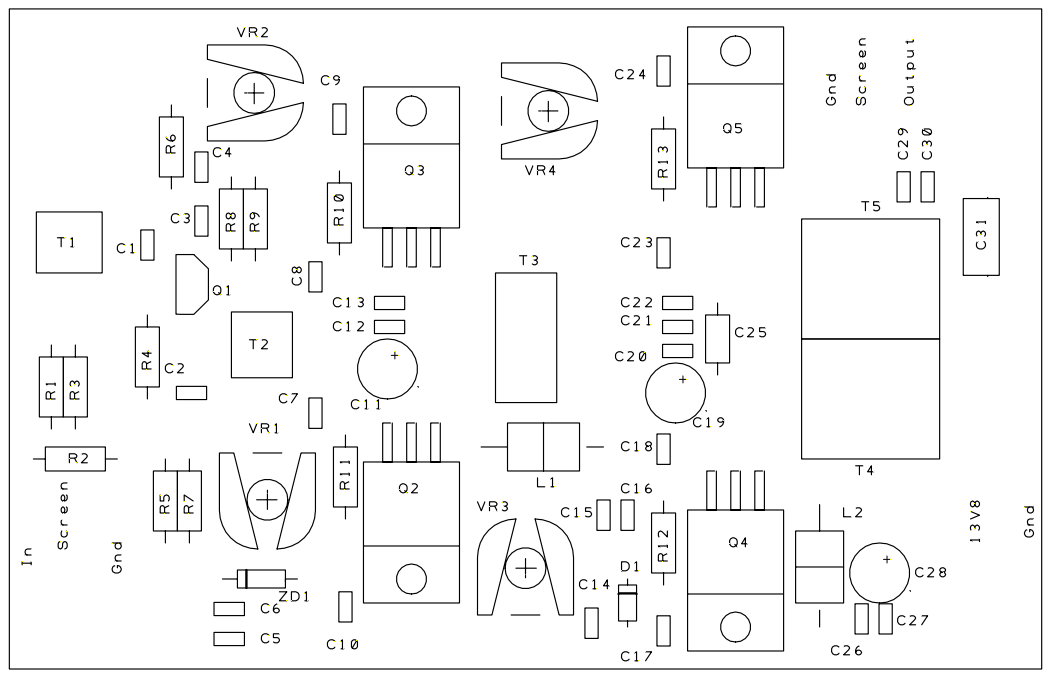
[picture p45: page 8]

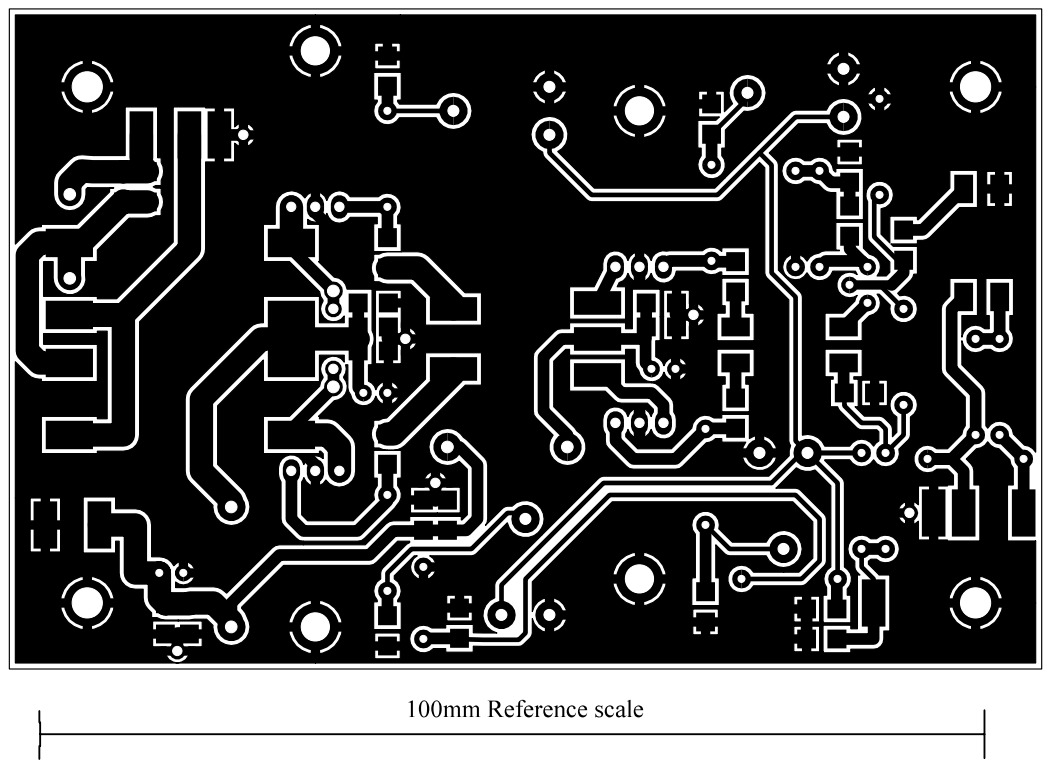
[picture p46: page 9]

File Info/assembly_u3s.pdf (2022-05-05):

## Ultimate3S: Multi-mode QRSS/WSPR transmitter kit

## PCB Revision: “QCU Rev 1”

## 1. Introduction

Thank you for purchasing this QRP Labs kit. You will also plug in other modules. You need to download assembly instructions for those kits also. You will need the following assembly manuals:

- This Ultimate3S assembly manual
- Low Pass Filter kit (bands 2200m to 6m)
- Si5351A Synthesiser kit
- OCXO/Si5351A Synthesiser kit (if you will use this option)
- Relay-switched LPF kit (if you will use this option)
- QLG1 GPS receiver kit (if you will use this option)

Recommended approach to building the kit: This is a simple design but there are a large number of features which provide a great deal of flexibility. Read this WHOLE manual and understand it! Follow the construction section to build the kit.

This assembly manual must be read in conjunction with the operation manual!

## 2. Design

The ATmega328 AVR microcontroller (IC1) is pre-programmed with firmware to control the LCD, buttons, and GPS interface.

For best results, please ensure the use of a well-regulated, clean and solid 5V power supply. The majority of problems with the kits arise due to poor power supplies! Not all wall-wart type or switched mode supplies are clean enough to power the kit.

The PCB contains the microcontroller, Power Amplifier (PA) and connections to other boards and interfaces. The LCD module, Si5351A Synth module, Low Pass Filter module, Relay-switched LPF module all plug into this main PCB. The separate Si5351A Synthesiser module kit includes its own on-board 27MHz crystal reference oscillator.

On/off keying is handled in software by switching on/off the output stage of the Si5351A synthesiser IC. The Q1 BS170 MOSFET is the power amplifier, producing about 250mW from a 5V supply on 30m (power output varies on different bands). Finally standard 7-element low pass filter plug-in modules remove harmonics of the transmission frequency. The schematic diagram on the following page shows the Ultimate3S QRSS/WSPR transmitter.

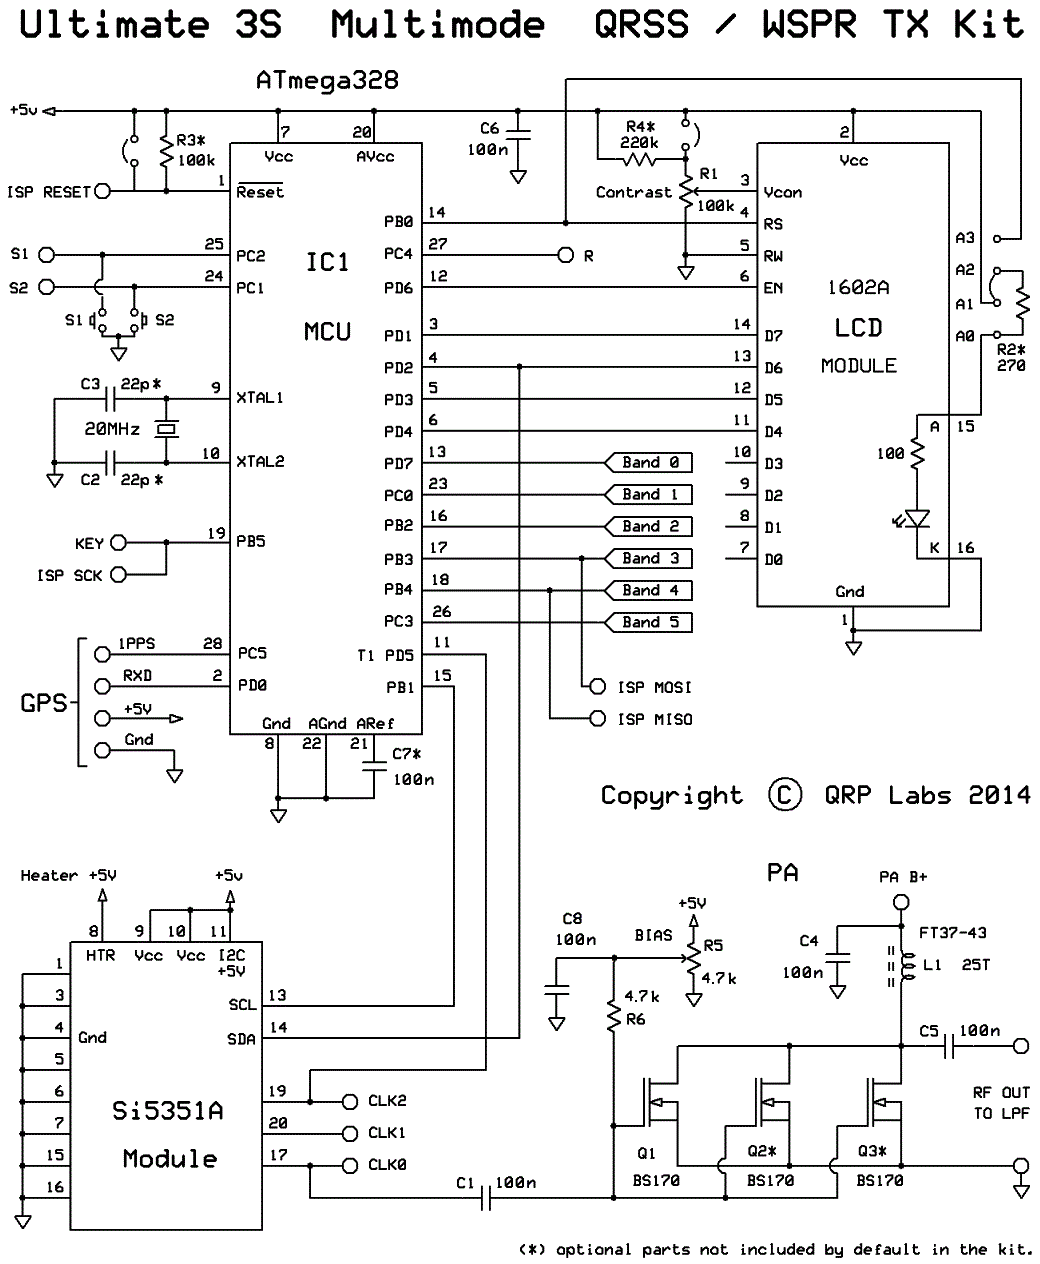
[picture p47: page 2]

## 3. Parts List

In the following parts list, components which are not supplied are shown in grey. They are optional, or supplied with other optional kits such as the relay-switched LPF kit, if you are going to use it.

### 3.1 Resistors

R1 | 100K preset potentiometer, for LCD contrast adjustment (code “104”)
R2 | No resistor – space is provided on the PCB only for reducing LCD backlight brightness
R3 | No resistor – space is provided for a 100K resistor, if you want to do AVR firmware upgrades
R4 | No resistor – space is provided for a 220K resistor, for smoother contrast adjustment
R5 | 4.7K preset potentiometer, for setting the PA bias (code “472”)
R6 | 4.7K resistor (colour coding yellow-purple-red-gold)

### 3.2 Capacitors

C2, 3 | No capacitor – space is provided for optional 22pF capacitors if required
C1,4,5,6,8 | 100nF (ceramic, marking 104)
C7 | No capacitor – optional, reduces noise when using analogue to digital conversion

### 3.3 Inductors

L1 | 25 turns, FT37-43 core (black)

### 3.4 Semiconductors

Q1, 2, 3 | BS170 (note: only one BS170 is provided in the kit, to be installed at the Q1 position.
| For use with higher PA supply voltages, more transistors may be added, i.e. Q2 and Q3).
D1 | No diode - provided for use with relay-switched LPF board kit
IC1 | Pre-programmed ATmega328 microcontroller

### 3.5 Miscellaneous

Two push buttons, S1 and S2
16-column x 2-row LCD (HD44780-compatible) with blue LED backlight Printed circuit board, 80 x 37mm size
Wire for winding toroid
Socket for IC1
20MHz quartz crystal
Two 10-pin female header sockets Two 4-pin female header sockets 16-pin female header socket
Two 16-pin male header plugs
Four 12mm nylon hex PCB spacers
Eight 6mm M3 screws
Relay RL0 – not supplied, provided for use with relay-switched LPF board kit

## 4. Construction

### 4.1 General construction tips

Parts placement is defined by the silkscreen printed legend on the PCB, so please observe it carefully, paying particular attention to the correct orientation of the semiconductors.

The PCB is quite small and the parts are close together. You are recommended to use a low wattage iron with a fine tip, and fine solder e.g. 1mm diameter or less. Take care not to overheat the PCB and risk damaging it. A well-lit area and magnifying glass are useful. Be careful not to bridge solder across closely packed connections. Some of the joints are very close to each other. I recommend checking with a DVM to make sure no solder bridges have been created.

Note that components D1, Q2, Q3, R2, R3, R4, C1, C2 and C7 are not required or supplied in the kit (R2 may be added by the builder if lower LCD backlight brightness is desired). Q2 and Q3 are not supplied, additional BS170 transistors may be installed here to increase the output power (see below).

IC1 (the microcontroller) has an IC socket, in case in future you wish to change the microcontroller e.g. for a firmware upgrade for new features, etc., or in case you wish to program it yourself. Sockets are provided for the synthesiser module and the low-pass-filter module, if applicable to your kit.

### 4.2 Construction steps

Please refer to the parts placement diagram below.

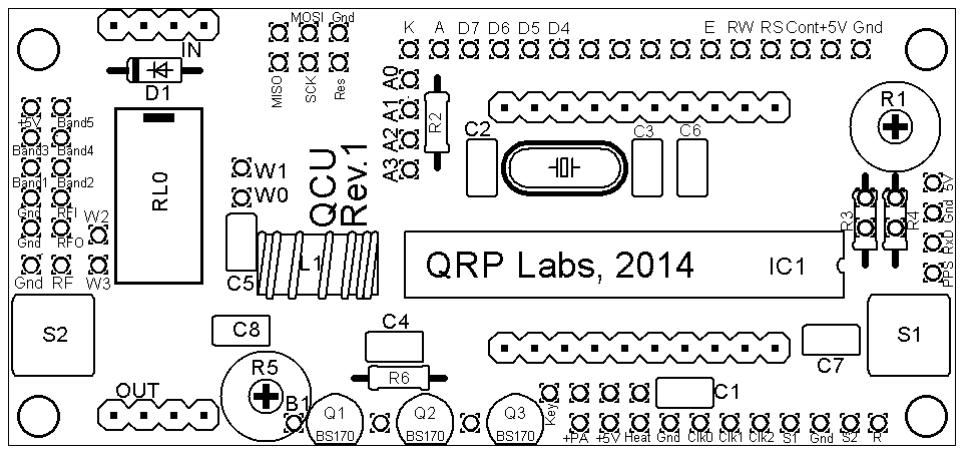
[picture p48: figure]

Pay special attention to the orientation of the semiconductors. For IC1, the dimple in the PCB silkscreen must be aligned with the dimple at the top of the IC socket and the IC.

The order of construction is not important. However, a good principle to follow is to install the smaller components first, so that the larger ones do not prevent easy access. One suggested order of construction is described below. I recommend following it carefully.

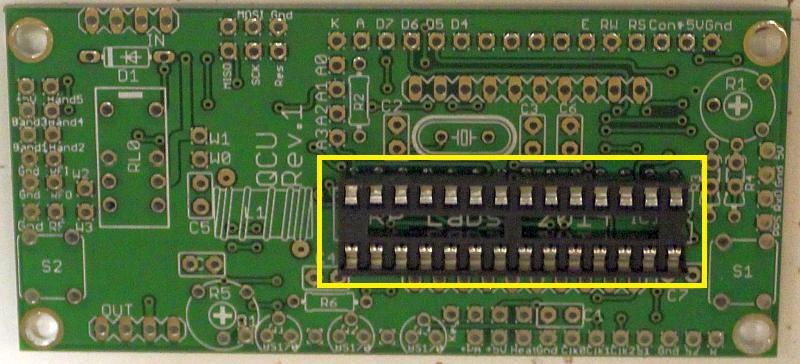
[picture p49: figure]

1) Solder in the socket for IC1.

To avoid confusion or mistakes later, align the dimple at one end of the socket, with the dimple illustrated on the PCB. The dimple should be at the end nearest the right-hand edge of the PCB.

2) Solder all capacitors, quartz crystal, and buttons S1/S2

There are five 100nF (0.1uF) capacitors. These are fitted in locations C1, C4, C5, C6, C8.

Note that the 22pF capacitors C2 and C3 either side of the crystal are NOT fitted – the 20MHz
crystal has been found to oscillate reliably without
them (there were some occasional issues when the

22pF capacitors were fitted). Therefore 22pF capacitors C2 and C3 are not supplied.

3) Wind and install the toroid

The silkscreen printing on the PCB shows vertical mounting of the toroid. If you prefer horizontal mounting, there is enough space for it. Please mount horizontally if you intend to use the OCXO/Si5351A Synth kit! When winding the toroid, remember that each time the wire goes through the centre of the toroid counts as one turn.
35cm of wire should be enough for 25 turns. Trim
the ends of the wire, scrape the enamel off and tin

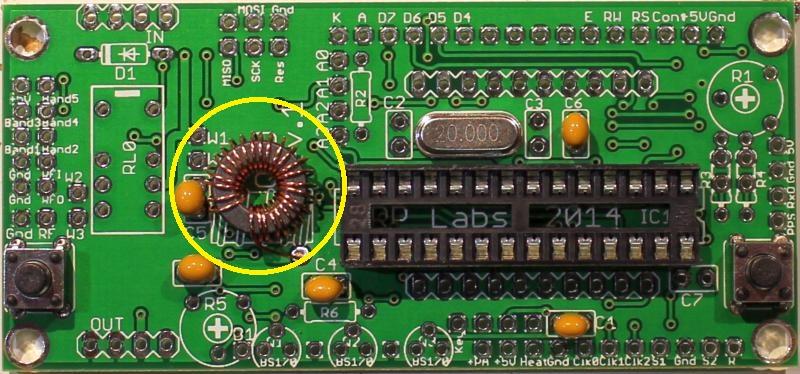
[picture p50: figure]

them with solder. As an alternative to scraping the enamel off, the wire ends may be held in a hot blob of solder on the iron tip for a few seconds, and the enamel will bubble away. Check continuity on the board with a DVM.

4) Solder the sockets for the low-pass-filter (LPF) module.

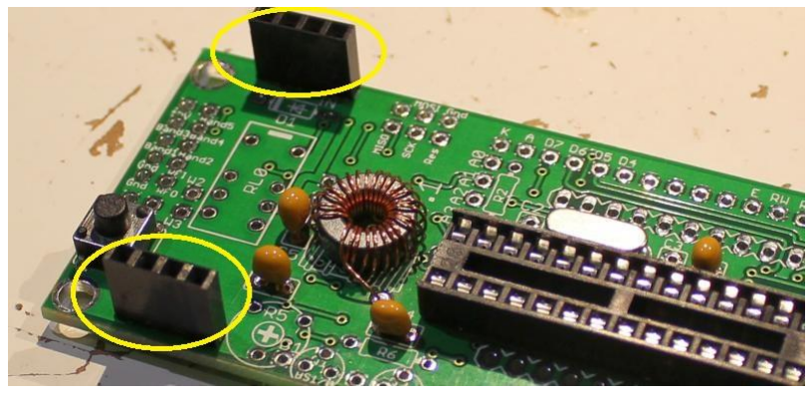
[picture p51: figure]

These are the two 4-way sockets. Some care
needs to be taken with the alignment, to ensure
that there is a good fit when the plug-in board is added. One method is to build the plug-in LPF module first; then plug it into the sockets. You can then solder the pins, ensuring correct alignment.

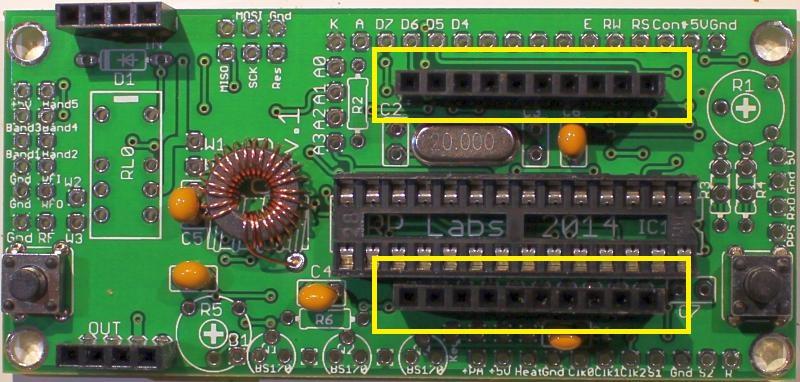
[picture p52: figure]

5) Solder the sockets for the Si5351A synthesiser module

These are the two 10-way sockets. Again take care of the alignment of the sockets, to ensure that there is a good fit when the plug-in board is added.

6) Fit and solder R1, the preset potentiometer that sets the LCD contrast.

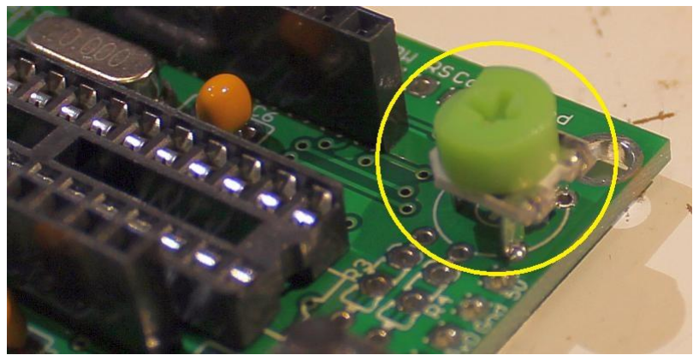
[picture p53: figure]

Be careful not to mix up the presets R1 (100K) and R5 (4.7K)! The code on R1 is “104”.

It is a slightly tight fit but apply pressure carefully and evenly, and the pins of the potentiometer will fit into the PCB perfectly.

Adjust this potentiometer to the fully clockwise position initially.

7) Fit and solder R5, the preset potentiometer that sets the PA bias.

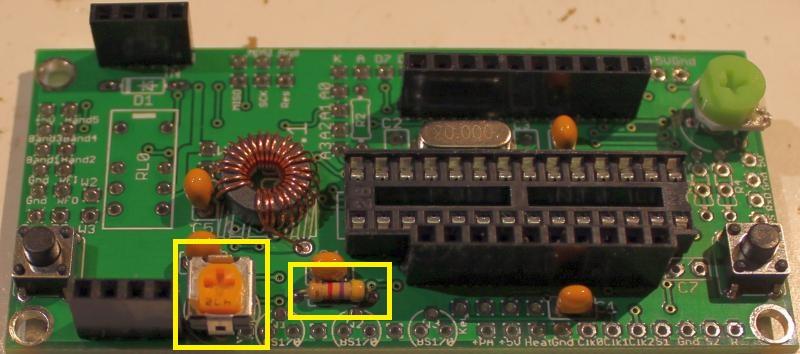
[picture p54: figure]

Also fit and solder the fixed 4.7K resistor R6. Be
careful not to mix up R1 and R5!

IMPORTANT: Turn the trimmer potentiometer all the way ANTI-clockwise, BEFORE applying power to the board. Please see section "PA bias set-up" below. The photograph (right) shows R5 in the mid position. In the correct completely ANTI-clockwise position, the “472” text will be to the right side, next to the Q1 position.

8) Solder wire jumpers as shown in the photograph and diagram below, depending on your requirements.

Typical jumper connections are shown in the photograph circled in yellow, and by red lines on the parts placement diagram below.

Please read the "Hardware options" sections
below, to decide which jumpers to fit.

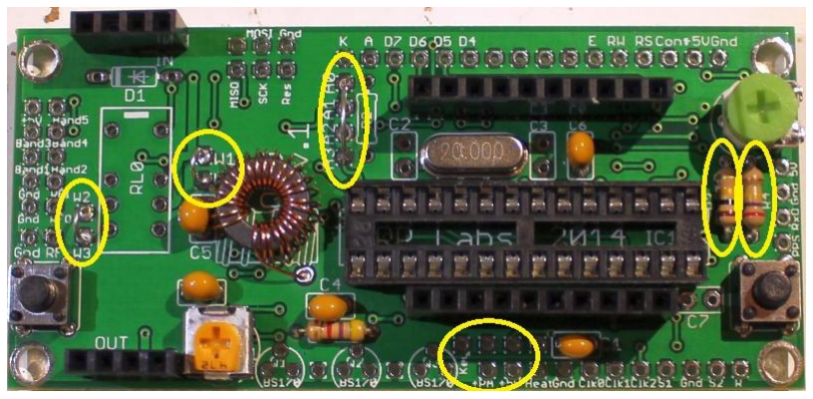
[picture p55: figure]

The wire jumpers can be made from offcuts from the other components e.g. capacitor leads. When installing these wire jumpers, I find it convenient to install them as a small semi-circular arch, perhaps 5mm high off the board. This is so that later, if they need to be removed (for different hardware options configuration), you can easily cut the links using wire cutters. It is easier than un-soldering them.

The W0-W1 and W2-W3 jumpers hard-wire the LPF into the circuit. Note that when a relay is fitted at RL0, you do NOT connect these two jumper wires. The relay is part of another kit, the relay-switched LPF board, which expands the capability of the Ultimate3S kit to sequence through up to 6 different bands.

If R2 is installed, in order to reduce LCD brightness, then connect A1-A2 instead of A0-A1 (see “hardware options” section below). You may decide to connect A0-A3 to use the software-implemented brightness control.

You may also install a jumper at the +PA and +5V connections at the bottom of the picture below, in order to power the power amplifier (PA) with the 5V supply. You should leave out this jumper if you intend to run the PA at a higher voltage. See more details in the “Hardware options” section below.

The "Heat" connection should be connected to +5V also, if you are using the OCXO version of the Si5351A module. It provides +5V to the oven heater, using a thick track on the PCB. This avoids voltage drop on narrow traces. If you are using the non-OCXO version of the Si5351A synthesiser module, then you do not need to connect the "Heat" connection.

Also pay attention to the jumpers at R3 and R4 on the right-hand side of the diagram. R3 is an optional resistor, to be fitted to enable in-circuit-programming for those wishing to update their own firmware and having the necessary equipment.

If you do not fit a 100K resistor for R3, then you must fit a wire jumper here as shown.

Resistor R4 is an optional resistor, which is in series with the top of the contrast adjustment potentiometer R1 and +5V. Typically the contrast voltage required is less than 1V and the adjustment is rather sensitive. If you wish, you can fit a 220K resistor in this position, which will make the contrast potentiometer less sensitive to adjust.

If you do not fit a 220K resistor for R4, then you must fit a wire jumper here as shown.

An example of typical jumper wire installations for basic operation of a single-band Ultimate3S QRSS/WSPR kit is shown in the following diagram.

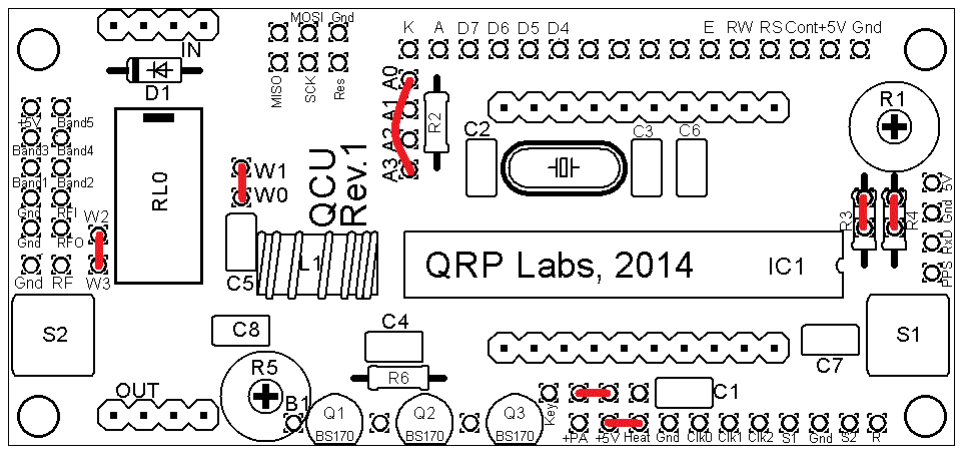
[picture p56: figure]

9) Solder in transistor Q1.

If you have purchased additional transistors for Q2 and Q3 to increase the power output, I still recommend starting with just the basic, single transistor, 5V PA supply setup. Get things working basically first, then later install the additional
transistors. Walk before you try to run!

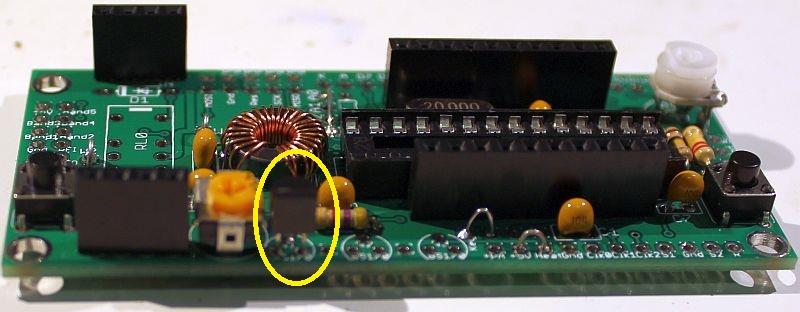
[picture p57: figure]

The transistors are located at the edge of the PCB with their flat side outwards. This is to allow easy attachment of a heatsink if desired (for higher voltage and hence higher power operation).

10) Install two 16-way connectors on the main PCB and LCD.

Install two 16-way connectors on the main PCB and LCD. Either way is fine, but my recommendation for installing the LCD connectors, is to use the female (socket) connector on the LCD side and the male (plug) on the PCB side.

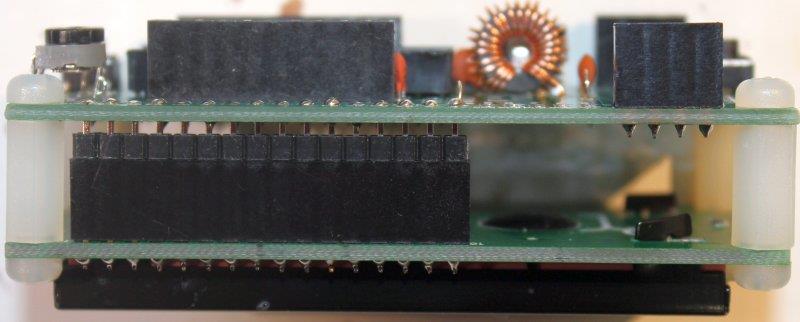
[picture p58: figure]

Be sure to solder the socket to the reverse of the
main U3S PCB!! Not the top side! It is very hard
to fix later, if you get this wrong!

Bolt together the LCD module and the PCB, with the 16-way connectors in place but not soldered. Then when you solder them, you will ensure perfect alignment. Use the eight 6mm M3 screws, and four 12mm nylon hex spacers, to bolt the PCB to the LCD.

The combined 16-way plug and socket when mated together, have a height of a little under 12mm. Therefore it is necessary to have a gap somewhere.

My suggested method is illustrated to the right here.
Closely mate the plug and socket. Leave the gap

between the male header (plug) and the PCB. I have found this method works successfully.

As you can see in the photo, the remaining pin length poking through to the component side of the PCB is short. However, the pins are still present in the holes and solder will fill the holes and connect to the pins.

At this stage, also solder the pins of the 16-way socket to the LCD module.

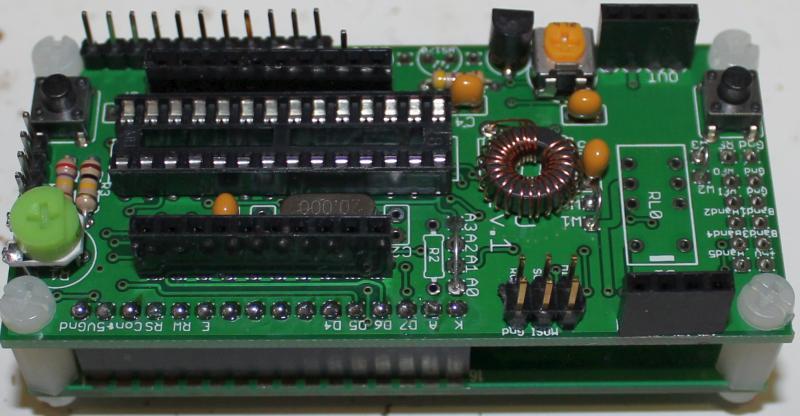
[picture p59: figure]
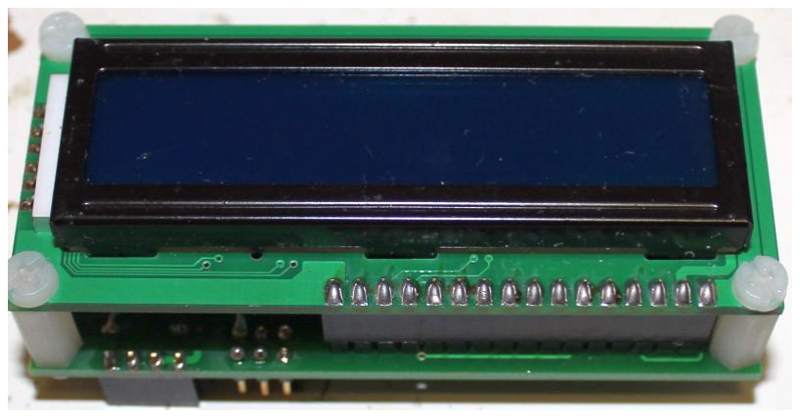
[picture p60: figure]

11) Optional header pins

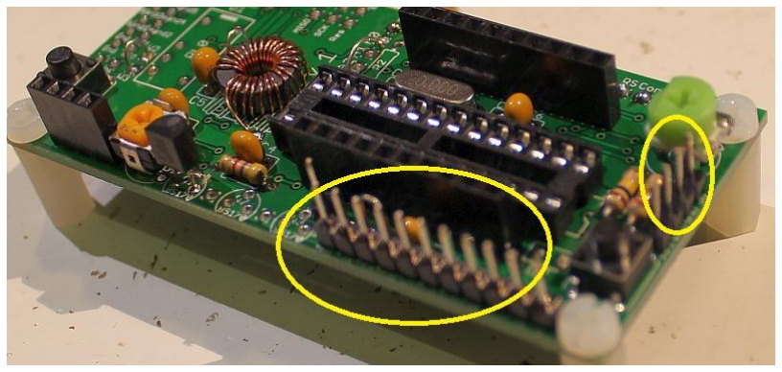
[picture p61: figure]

The kit is supplied with TWO of the 16-pin headers. Only one is needed for the connection to the LCD module. The other is supplied so that if you wish, you can solder it to the PCB and use it for more convenient connections to the kit. You can either solder directly to the pins, or use the appropriate connector.

The 16-pin header strip can easily be snapped into smaller pieces. In the photograph (right) I have broken off a 4-pin section to use for the GPS connector, and installed an 11-pin section along the board edge. The final pin was installed in the “Key” connection pad.

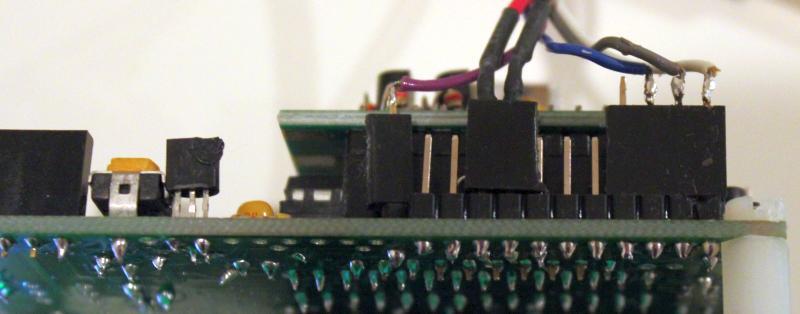
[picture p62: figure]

The photograph (right) shows an example of making connections to this header.

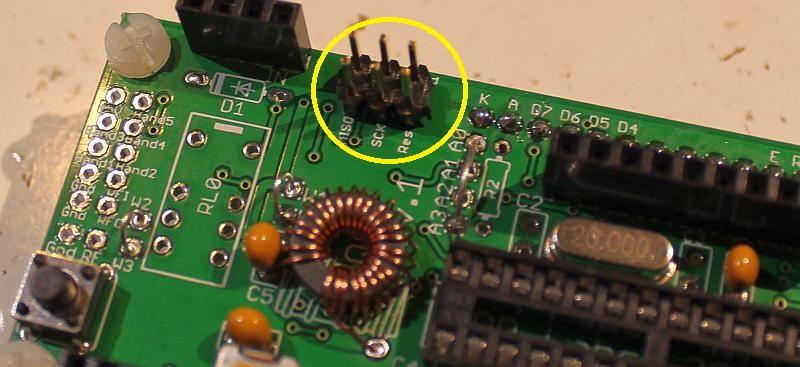
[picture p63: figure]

12) Optional In-circuit programming header

The QCU kit has provision for installing a standard Atmel 3 x 2 header (not supplied), for in-circuit programming of IC1 the ATmega328 processor.

This option is useful if you want to use one of the many inexpensive AVR programmers to upgrade the kit firmware, when updates are published by QRP Labs.

### 4.3 Module assembly

First the microcontroller IC1 should be inserted in its socket. Be sure to align the microcontroller chip correctly. The dimple on the chip must be at the same end as the dimple on the socket, and the dimple on the silkscreen legend on the PCB.

Next, plug together in the other modules (LPF, Si5351A Synth). These pictures show the U3S PCB Revision 1, but the module assembly is the same.

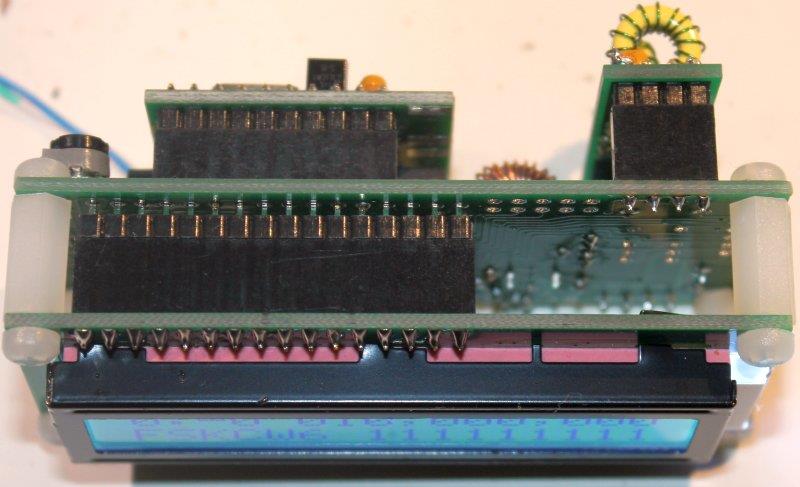
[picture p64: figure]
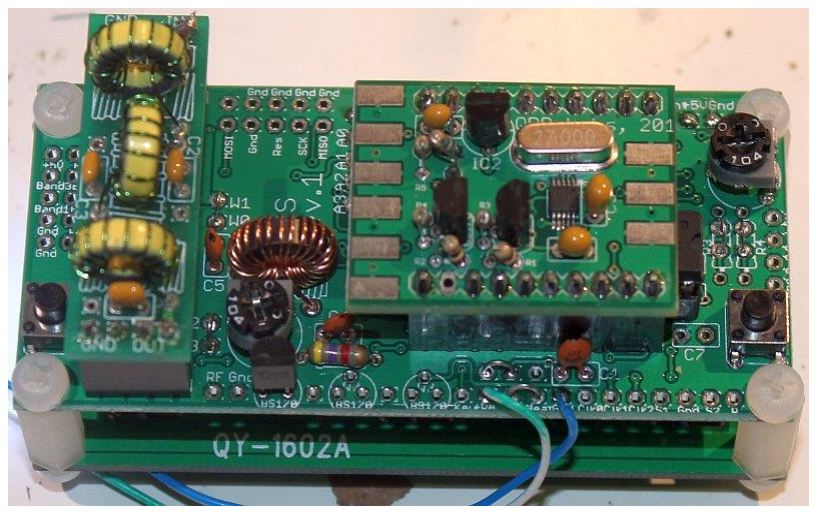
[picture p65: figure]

Ensure that the Si5351A synthesiser module is inserted the correct way round as shown in the photograph. The Low Pass Filter kit module should be plugged in with the “Out” legend aligned next to the RF Output connector of the main PCB (see photo).

Important! Upon power-up, you will need to adjust the contrast potentiometer R1 to view the LCD properly. Turn it fully clockwise to start with (before applying power). Then turn it gradually anticlockwise until the displayed text looks correct.

The series of photographs below show the display with a) fully clockwise; b) fully anti-clockwise; c) adjusted perfectly. When adjusted perfectly, you will see "Diagnostic Mode" message on the screen.

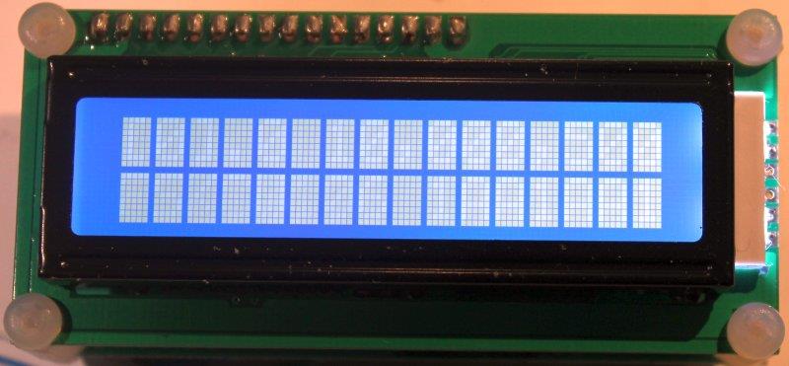
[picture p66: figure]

When you see "Diagnostic Mode" it means all is well with the

processor and the LCD communication. When you press the left button, diagnostic mode will be cleared. Then you should see the splash screen, which shows the firmware type and version number.

If you cannot see any text on the screen even after
adjusting the contrast setting, you have a problem. Please
refer to the "Troubleshooting" page on the QRP Labs website (see resources section below).

## 5. Hardware Options

### 5.1 Explanation of connections

The table to the right details the purpose of the connection points around the right-hand and bottom edges of the PCB.

The pin-spacing is 0.1-inches and a suitable connector could be used (see section above).

These connections are further described in the following sections.

Note that the cluster of connections at the left board edge are for fitting the connector to the relay-switched LPF board kit. They
can be ignored for now.

Connections A0, A1, A2 and A3 allow options concerning the LCD backlight, as described below. Typically you should connect A0 and A3, this enables the software controlled backlight control.

### 5.2 Connection for basic operation

For the most basic operation of this kit as QRSS/WSPR transmitter using 5V supply, it needs only a power supply and RF output connection. To allow use of a higher voltage supply for the PA, there are separate connections for the PA voltage and +5V supply. To run the transmitter using the 5V supply, be sure to connect a wire between the +5V and PA pins. This is shown by the short red horizontal line in the diagram (below).

The "Heat" connection is only required if you are using the OCXO version of the Si5351A synthesiser module. You must connect it to +5V to power the oven heater.

Label | Group | Description
5V | GPS | +5V supply to GPS module
Gnd | GPS | Ground connection to GPS module
RxD | GPS | Serial data input from GPS module
Pps | GPS | 1 pulse per second input from GPS module
R | Future | No connection – for future enhancements
S2 | Buttons | Optional external button S2, switch to Gnd
Gnd | Buttons | Ground for optional external buttons
S1 | Buttons | Optional external button S1, switch to Gnd
Clk2 | Signal | Clk2 Si5351A output, 3.3V p-p squarewave
Clk1 | Signal | Clk1 Si5351A output, 3.3V p-p squarewave
Clk0 | Signal | Clk0 Si5351A output, 3.3V p-p squarewave
Gnd | Power | Ground connection to Power supply
Heat | Power | +5V heater for OCXO/Si5351A module option
+5V | Power | +5V power supply
+PA | Power | PA power supply – may be connected to +5V
Key | Control | “Keying” output: high during transmit
Gnd | RF | Ground for RF output
RF | RF | RF output

### 5.3 Alternative button mounting option

You may use an external pair of buttons to control the kit. The button input signals are available at the edge of the board, labelled S1 (left button) and S2 (right button). The buttons should be of the push-to-make variety. The left button should be connected between the S1 signal and ground; similarly the right button should be connected between the S2 signal and ground. Suitable buttons are supplied in the official QRP Labs U3 Case and accessories kit.

### 5.4 Optional connection of GPS module

A GPS module may be connected to the kit, to provide frequency stability, accurate time, and latitude and longitude which can be converted to Maidenhead locator format for encoding in the WSPR message transmission.

Check that your module is powered from 5V. Many modules specify a 3.3V supply - in this case you will need to provide an external 3.3V voltage regulator. Some GPS modules may need a pull-up resistor however.

The QRP Labs QLG1 GPS receiver module kit is powered from 5V and
does not require pull-up resistors. It is suitable for direct connection to the Ultimate3S kit.

In cases where the location information is not required (modes other than WSPR) or you wish to enter it manually, the serial data input can be left unconnected. The 1 pps input is enough for the frequency lock function. A 1pps signal could be supplied from a non-GPS source, such as a laboratory frequency standard. Note that the frequency locking function can only operate if you have selected a wait period between message transmission (i.e. a non-zero “Frame” parameter).

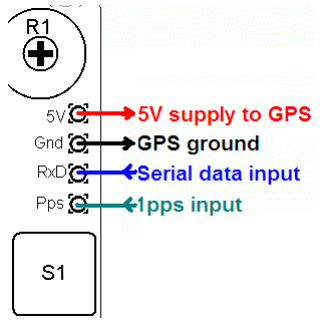
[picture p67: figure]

See operation instructions for details on how to configure the GPS interface.

### 5.5 Higher power output

The PA in the kit provides around 250mW of output power using a 5V supply and a single BS170 transistor (depending on the band). The transistor gets warm to the touch. If higher output powers are desired, this can be achieved by using a higher supply voltage for the Power Amplifier (PA). The microcontroller must still be run at a voltage not
exceeding its 5.5V rating (5V is recommended). To
facilitate running the PA at higher voltages to

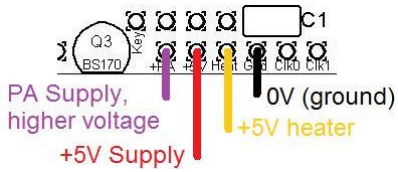
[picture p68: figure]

provide more power, the PA supply connection is a separate pin.

At higher supply voltages and power outputs, the heat dissipation in the BS170 will increase and its temperature will be higher. Provision is made on the PCB for two more transistors in parallel with the first. This will slightly increase the power output even at 5V supply, but more importantly at higher voltages it should share the heat dissipation between the devices.

It may be necessary to fix a heat sink to the transistors if the temperature rise is excessive. The transistors are located near the edge to the board to allow a heatsink. Experiment is needed in this area, with PA voltages up to perhaps 12V.

### 5.6 LCD backlight options

a) Full brightness: For basic operation connect A0 to A1 using a wire jumper (made from a capacitor lead offcut, for example). The blue LED backlight of the LCD module will be at full brightness. This is shown as the Red line (left). In this case, do not fit any resistor at the R2 position.
b) Reduced brightness: You may find the LED backlight of the LCD module too bright for your liking, or if you wish to operate from battery power, perhaps you consider that it consumes too much current. In that case, fit a wire jumper between A1 and A2, and use a suitable valued resistor at the R2 position: experiment, e.g. starting at 100-ohms. 180-ohms has been reported to work well. 220-ohms or 270-ohms may also suit your taste.
c) Software variable brightness: The U3 firmware contains a "Backlight" configuration setting which can be set from 0 (backlight OFF) to 9 (maximum brightness). This is achieved using pulse width modulation. To enable this setting, you must connect A0 to A3 using a wire jumper (do not fit any resistor at the R2 position).
d) Switched backlight: If you do not wish the LCD module's LED backlight to be on all the time, then instead of the wire jumper, you could connect wires to an on/off switch. This could be useful for battery powered operation, to reduce current consumption. For example, you could switch the display on to set up the kit, then leave it switched off during operation. The official QRP Labs U3 Case and accessories kit includes a spare switch which could be used for this purpose.

### 5.7 Si5351A outputs

For possible use in other projects, the connection points labelled Clk0, Clk1 and Clk2 provide direct connection to the Si5351A module's outputs. They are 50-ohm impedance and provide up to a 3.3V peak-peak squarewave. Actual peak-peak amplitude may be less than this (worst case 2.1V p-p), particularly at higher frequencies – please refer to the Si5351A datasheet. Do not draw excessive loads from these connections.

### 5.8 In-circuit programming of AVR

If you own an AVR programmer, you can make connections to the QCU PCB to allow updating the firmware without removing the AVR chip.

In this case, you should fit a 100K resistor as R3, not a jumper link. This is shown enclosed in RED on the right side of the below diagram. The other connections required to your programmer, are MISO, MOSI, SCK and Res (reset), these are indicated in the RED square on the diagram. The connection layout is designed to fit a 2 x 3-pin header, to match common AVR programmer cables. Before use, you should check that the connections match your programmer, because there are several standards in use. This board is designed to be as flexible as possible.

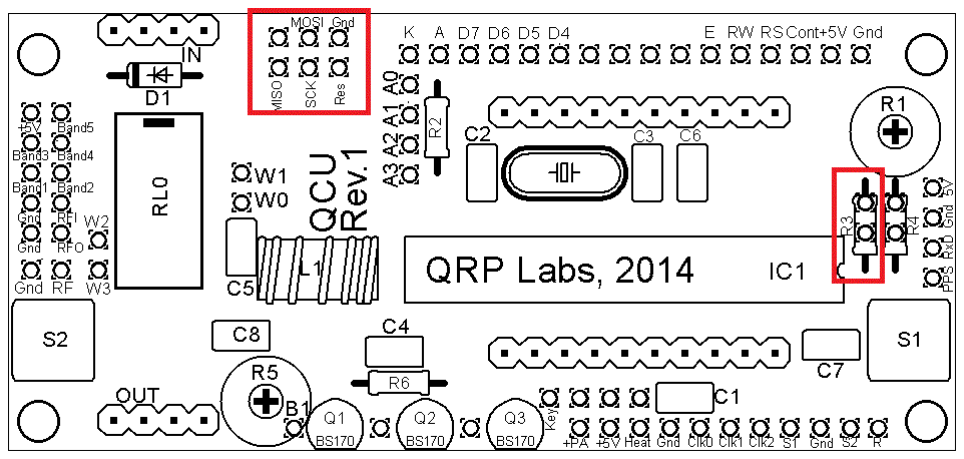
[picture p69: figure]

Notes:

1) Power needs to be applied to the kit during programming! When you start programming, whatever the processor is doing at that moment will be interrupted.
2) Some constructors have reported that if the relay-switched LPF board is fitted, the relays chatter because the programming lines are shared with relays 3 and 4, and programming errors. If this happens with YOUR programmer, you need to either remove the relay board during programming, or cut the wires to relays 3 and 4 and put a DPST switch in, to disconnect them when required.
3) Some programmers require a connection to sense the voltage level of the target processor. They do this on the 6th header pin (the top right of the 3 x 2 matrix in the picture above). On this QCU PCB, this pin is not connected. If your controller needs to sense the board voltage on this pin, then you need to wire a connection from this pin to +5V. A convenient (and nearby) place to do this is the cathode of the D1 diode. This connection is shown by the purple wire in the below diagram. The wire should be soldered on the underside of the PCB.

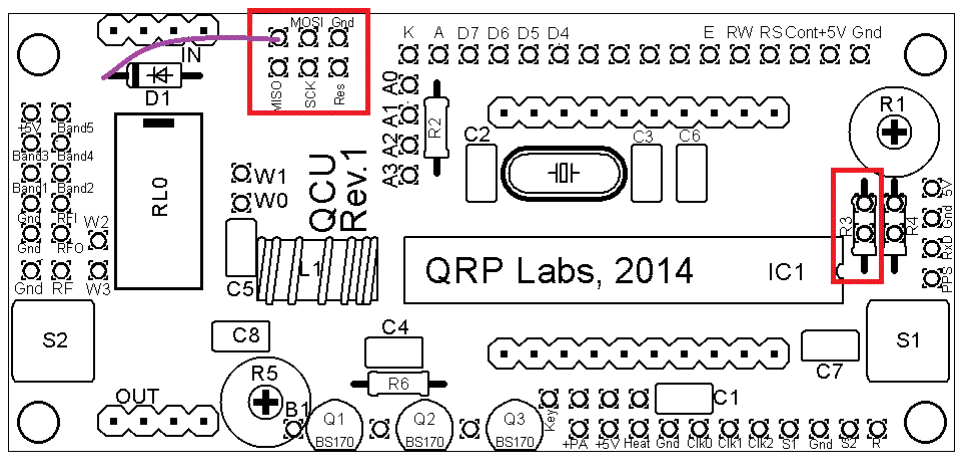
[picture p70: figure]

### 5.9 Higher sensitivity contrast potentiometer adjustment

The contrast voltage required by the LCD is typically under one volt, but the potentiometer R1 is connected between +5V and Gnd. Therefore most of the available travel of the potentiometer adjustment is redundant, and the contrast adjustment is rather sensitive. If you wish to improve this, you may fit a resistor at R4 instead of the wire jumper. A suitable resistor value is 220K or 270K, for example.

## 6. Calibration

It is very important to realise that by far the hardest part of any successful QRSS beacon operation, is tuning the oscillator to the correct frequency. For example, most 30m QRSS stations monitor a narrow 100Hz-wide band from 10,140,000 to 10,140,100. The WSPR sub-bands are 200Hz wide. If you are much outside this, the chances are that nobody will see your signal. It is therefore essential either to adjust your output frequency using an accurately calibrated frequency counter, or an accurately calibrated receiver.

If you are going to use a GPS receiver module to provide a 1pps signal to the kit, no calibration is required: the kit will self-calibrate from the 1pps signal.

In the case that you will not be using a GPS signal, you need to calibrate the kit by entering the correct value of the 27MHz reference oscillator frequency into the “Ref. Frq.” configuration setting.

It is possible that you have an accurate means to measure the 27MHz reference oscillator frequency itself by probing the correct point on the Si5351A module. However most kit builders will not have the necessary equipment, and such a measurement is not easy to make without itself risking disturbing the frequency.

The easiest method is to set the output frequency to something convenient such as 13.500000 MHz, and measure it. Measurement can either be by using an accurately calibrated frequency counter, or by setting up an accurately calibrated receiver with Argo and monitoring the output signal frequency that way.

Once you have measured the actual output frequency, you can calculate the required correction to the 27MHz reference frequency and enter it in the “Ref. Frq.” configuration setting. For example, suppose you set the output frequency to 13.500000 MHz but you actually measure 13.500075. Your output frequency is 75 Hz too high. Since your output frequency setting is 2 times less than the 27MHz reference oscillator frequency, this means that the actual reference oscillator value is 150Hz too high. So enter 27,000,150 in the “Ref. Frq.” setting.

## 7. PA bias set-up

If you are using the OCXO/Si5351A Synth you will find that the R5 trimmer potentiometer is only just accessible under the OCXO when plugged in. This is a great improvement over earlier PCB revisions in which the trimmer potentiometer was completely covered by the OCXO! There is only so far it could be moved, before falling off the board edge. An alternative method of setting up described below, can be used – and does not require the OCXO to be present.

Initially the bias trimmer potentiometer R5 should be set all the way anti-clockwise. With the Si5351A module plugged in, and when you have set up the software to configure your U3S for some transmission, connect a 50-ohm dummy load (two 100-ohm resistors in parallel is fine, or a 47-ohm resistor is fine too). Monitor the power output. As you turn R5 gradually clockwise, the power output will increase. At some point beyond half way, the power output will peak, and as you continue to turn clockwise, power will decrease. This is too far! Now your BS170 will start getting hot. Maybe very hot. So back-off a little. My recommendation is to set the power output a little below the peak setting. A little ANTI-clockwise, from the peak power output setting.

An alternative adjustment procedure also works very nicely. I recommend this method, if you have access to a means to measure the current consumption of the kit with reasonable accuracy. You should measure the overall current consumption of the U3S kit in “idle” mode (key up, not transmitting). You do not even need to plug in the Si5351A module for this. It is a useful method for those using the OCXO, who find accessing R5 to be difficult. Monitor the current consumption of the U3S in “idle” mode and adjust R5 until you just about see a slight increase. This will be a fairly reasonable bias point for good operation of the PA, when you plug in the Si5351A module.

## 8. Resources

Please see the kit pages at http://www.qrp-labs.com for any information on latest updates and issues.

For troubleshooting please refer to http://www.qrp-labs.com/ultimate3/u3trouble for troubleshooting.

Further references are listed in the Operation manual.

## 9. Version History

0 18-Jan-2016

- First version, based initially on Ultimate3S kit assembly manual for U3S Rev2 PCB

1 04-Apr-2016

- Correction to diode connection mentioned on page 16, should be cathode (was anode)
- Clarification of the “anticlockwise” bias potentiometer photograph

2 06-Oct-2016

- Correction to circuit diagram, R4 shown as 100K should be 220K; also on page 7 R4 was referred to as 200K, should be 220K.

3 25-Oct-2016

- Simplified and clarified the assembly manual

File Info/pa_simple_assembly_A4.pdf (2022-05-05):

Rev 1.03 | 1

PA

## 5W HF PA kit SIMPLIFIED assembly instructions

## 1. Introduction

This is a Power Amplifier kit (PA) for CW or FSK modes. The output power is approximately 5W in the middle of the HF frequency range, using a 13.8V supply. A single inexpensive IRF510
MOSFET is the amplification device. An unusual feature of this PA is the built-in facility for envelope shaping, which can create a precise raised-cosine keying envelope shape. This greatly reduces key-clicks when using on/off keyed modes such as CW or at the commencement/completion of an FSK mode transmission.

I highly recommend building the full kit as described in the assembly instructions. The kit has a discrete component power modulator (voltage regulator) which is controlled by an 8-bit R-2R Digital Analogue Converter, and allows an external microcontroller to control the amplitude of the output by loading the on-board 8-bit shift register using three I/O signals, and thereby create the raised cosine shape.

These instructions are for a simplified assembly of the PA kit, which omits raised cosine envelope shaping, or the power modulator with fold-back current limiting. It is easier to build this way, but the functionality is less.

The kit has a PCB of size 80 x 37mm, which is the same size as the other QRP Labs modules such as the Ultimate3S QRSS/WSPR transmitter kit, the VFO kit and the Relay-switched LPF kit. It is therefore physically (as well as electrically) compatible with the other QRP Labs kits and can be bolted behind them in the familiar PCB sandwich. Alternatively this PA can be used with your own homebrew projects. The PCB has space for SMA connectors (not supplied by default with the kit), if you wish to use SMA cables.

The PA kit must always be followed by a low pass filter to attenuate unwanted transmitter harmonics, as usual for RF power amplifiers.

Carry out an inventory of the components according to the parts list to make sure all the components required are present. Remember that there will be many surplus components that are required only for the full build and will not be used here. Read the assembly instructions first before starting the assembly, understand everything, and then finally start the assembly, following all the steps carefully!

The following diagram shows the simplified circuit diagram of this HF PA.

This diagram includes a 10-ohm resistor modification which is highly recommended, and will be described later in this document.

## 2. Parts list

Unused parts are coloured grey – these are used only in the full build.

Resistors

R27 | 0.33-ohm, 2 watt resistor
(none) | 10-ohm resistor
R2, 19 | 15K resistor (2 pieces)
R4..10, 28 | 1.1K resistor (8 pieces)
R3, 11..18, 24 | 2.2K resistor (10 pieces)
R20, 22 | 3.3K resistor (1 pieces used, 1 piece not used)
R21, 30 | 330-ohm resistor (2 pieces)
R23 | 8.2K resistor
R29 | 47K resistor
R1 | 4.7K trimmer potentiometer resistor
R26 | 3.3K resistor (not supplied)
R25 | 4.7K trimmer potentiometer resistor (not supplied)

Capacitors

C1, 2, 3, 7, 8 | 1uF capacitor (5 pieces)
C5, 6 | 1uF capacitor (2 pieces)
C4 | 1nF capacitor

Semiconductors

IC1 | 74HC595 8-bit shift register, 16-pin DIP package
IC2 | 7805L 5V regulator, TO92 package
Q3, 4 | 2N3904 NPN transistor, TO92 package
Q1, 2, 6, 8 | 2N3906 PNP transistor, TO92 package
Q5 | 2SC4242 NPN power transistor, TO220 package
Q7 | IRF510 N-channel power MOSFET, TO220 package
Q9 | BS170 N-channel MOSFET, TO92 package

Miscellaneous

16-pin socket | 16-pin DIP socket for IC1
10-pin header | 10-pin 0.1-inch header
Heatsink | 65mm long PCB-mounting heatsink and pins
Insulation sets | 2 pieces silicone rubber insulation pads + washers for the TO220 transistors
Nut and bolt | 12mm long M3-size bolt and matching nut
FT50-43 | FT50-43 toroid
Wire | 100cm 0.33mm diameter wire
PCB | 80 x 37mm Printed Circuit Board (PCB)

## Theoretical circuit explanation

The chosen amplification device is the IRF510 MOSFET. It is inexpensive, robust, easily able to handle the power requirements, and in a convenient TO220 package. On the other hand, the IRF510 does have high gate capacitance. It is originally intended as a switch for switched-mode power supplies and other such industrial switching requirements. Using it as an RF amplifier wasn’t the manufacturer’s original intention! But it works well on HF, nevertheless! The power output does drop off at the higher frequencies.

For this reason the PCB has been designed to also accept the RD15HVF1 transistor (and similar devices) which are intended and designed for RF applications. They perform very well right up into VHF, 2m band etc. So if you wish to use this PA kit for 6m and 2m you may want to replace the supplied IRF510 with
a RD15HVF1 or one of its siblings. The pinout
of the RD15HVF1 is different to that of the

IRF510. The PCB has a second set of pads to suit the RD15HVF1.

The incoming RF is coupled to the IRF510 gate via a 1uF capacitor. The largish 1uF value is intended to help the PA work well on LF and MF. A DC bias voltage must be applied to the IRF510 gate, this is supplied by 4.7K preset potentiometer R1 via the 3.3K resistor R20.

A trifilar output transformer wound on an FT50-43 toroid provides matching to the 50-ohm output. There are pads/holes on the PCB for an optional SMA connector. This is not supplied in the kit but is available in the QRP Labs shop. You can also fit an SMA connector at the PA kit’s RF input instead of the 2-pin header. The RF output is also available at the 2-pin header JP5, and at a 2 x 5-pin header JP1 (not supplied). The 2 x 5-pin header matches the headers on the Ultimate3S QRSS/WSPR Transmitter PCB and the 6-band relay-switched filter kit PCB. This option may be used when using this PA kit with Ultimate3S, and is described in the application note AN004.

The PA kit also contains a TO92-package 5V regulator IC type 78L05, IC2 (also equivalently called 7805L by some manufacturers). Note that this is shown on the main circuit diagram but in not the sub-block above. This 5V is used for the PA bias. Providing the regulator on board simplifies the use of this PA kit module because you only need to provide a single PA supply e.g. 13.8V. However do not be tempted to power other circuits from this 5V regulator output, such as the Ultimate3S kit or other. The 78L05 is only a low power voltage regulator and has no heatsink. The 78L05 is rated for 100mA maximum supply current.

## 3. Assembly

Assembly of this kit is quite straightforward. The usual kit-building recommendations apply: work in a well-lit area, with peace and quiet to concentrate. Some of the semiconductors in the kit are sensitive to static discharge. Therefore observe Electrostatic discharge (ESD) precautions. And FOLLOW THE INSTRUCTIONS!!

A jeweller’s loupe is really useful for inspecting small components and soldered joints. You’ll need a fine-tipped soldering iron too. It is good to get into the habit of inspecting every joint with the magnifying glass or jeweller’s loupe (like this one I use),
right after soldering. This way you can easily identify any
dry joints or solder bridges, before they become a
problem later on when you are trying to test the project.

It is always best to detect and correct any mistakes as early as possible (immediately after soldering the incorrect component). The board is quite compact, to fit the required 80 x 37mm PCB dimensions. Removing a component and re-installing it later is often very difficult!

The resistors in the kit are installed vertically, because
PCB space is limited. It was important to design it to fit

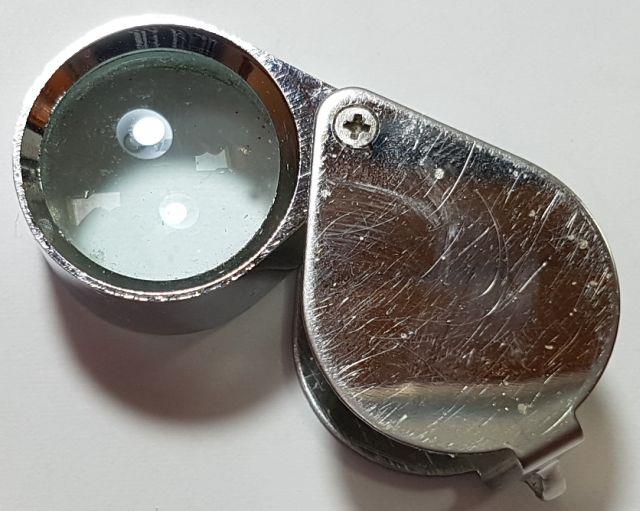
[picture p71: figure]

on an 80 x 37mm PCB for potential use with other QRP Labs kits such as the Ultimate3S QRSS/WSPR transmitter. You will need to bend the resistor wires as shown in the picture below. On the parts layout diagram there is a small circle around the hole where the body end of the resistor should be installed. This is
not critical (resistors don’t care
which way around they are) but it is
recommended, just to try to ensure that the folded over wire-end of the
resistor doesn’t touch any other
wire or metal part.

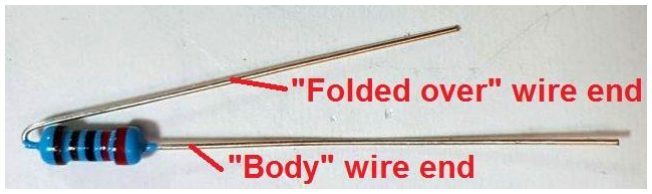
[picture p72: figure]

Please refer to the layout diagram and PCB tracks diagrams below, and follow the steps carefully.

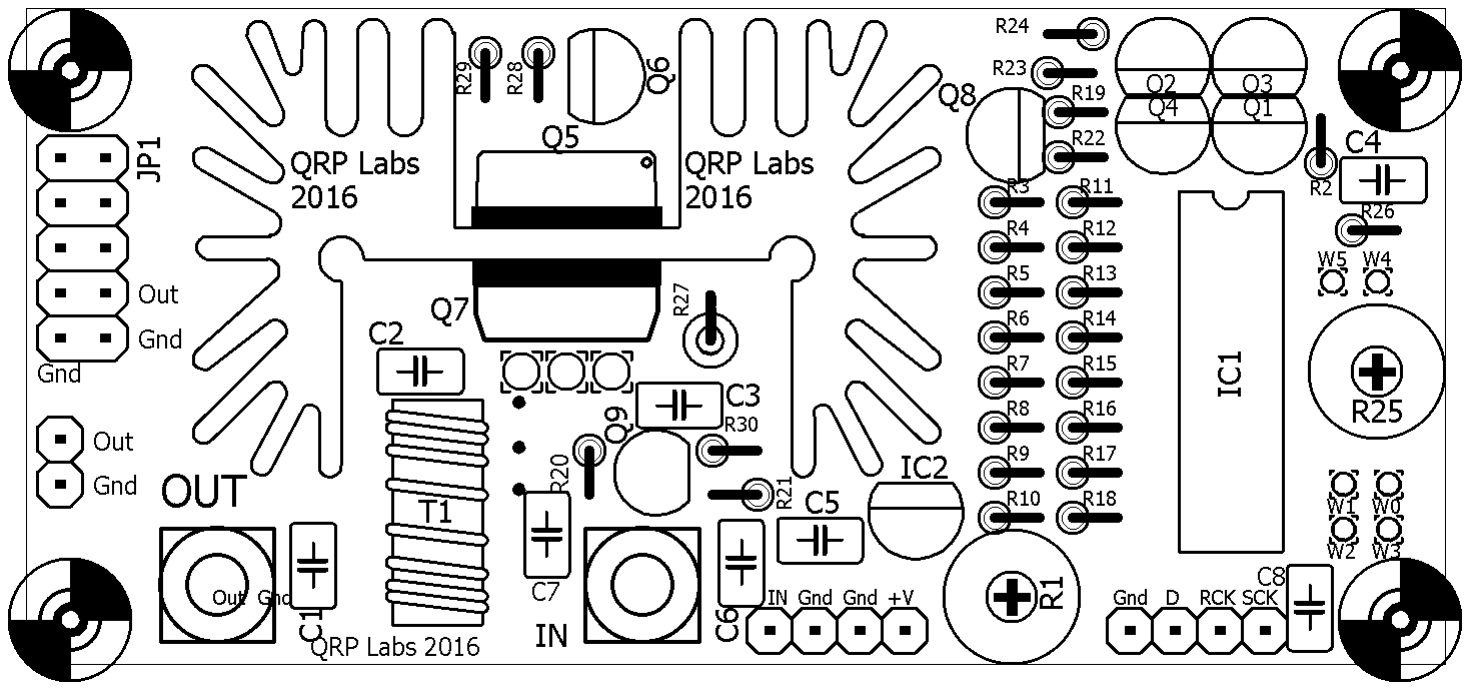
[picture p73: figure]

PCB track diagram. Tracks shown in BLUE are on the bottom layer. Tracks shown in RED are on the top layer. There are only two layers (nothing is hidden in the middle). Not shown in this diagram are the extensive ground-planes. Everything on the bottom layer that isn’t a RED track, is ground-plane! Large areas of the top side are also ground-plane, connected to the bottom ground-plane layer at frequent intervals by vias.

Note that the heatsink is not electrically connected to ground or anything else. The area right under the heatsink has no ground-plane on the top layer. This is to prevent the heatsink potentially scratching the soldermask and connecting to a ground-plane if there was one. For the same reason there are no tracks on the top layer under the heatsink. The metal tabs of the TO220 transistor is NOT connected to ground, and is insulated from the heatsink, so long as all the insulating hardware is properly installed. The heatsink itself is therefore connected to nothing at all.

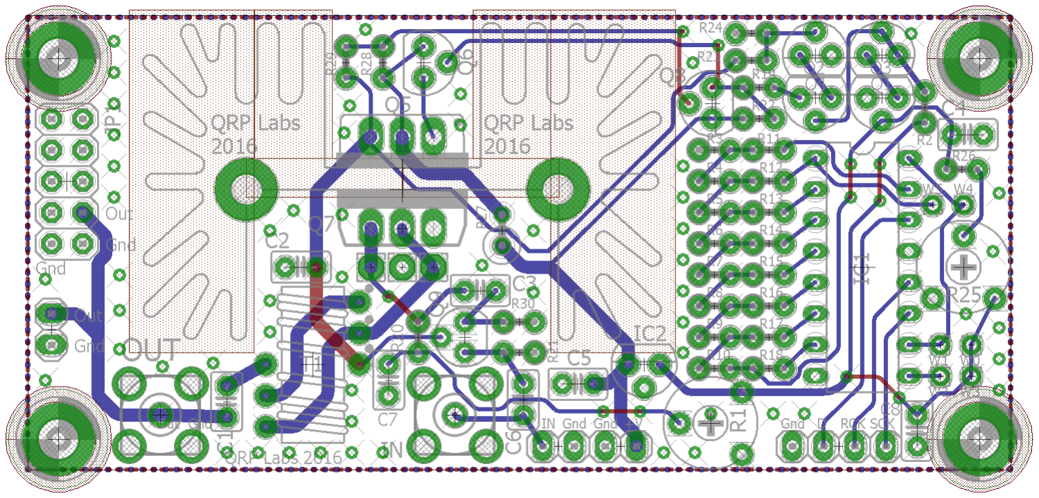
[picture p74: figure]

## 3.1 Inventory parts

This is the full list of parts. Many are not used in this simplified build. Please refer to the parts list.

## 3.2 Install required components

Install and solder the components indicated in this diagram and described as follows.

YELLOW: Capacitors C1, C2, C3, C7 and C8 are 1uF capacitors. The writing on the capacitor is “105”. Be careful – the kit also contains one 1nF capacitor labelled “102” – do not mix them up!

RED: Resistor R20, 3.3K, with colour code with colour code orange-orange-black-brown-brown.

BLUE: 78L05 voltage regulator IC2. Be careful to install this with the same orientation as the white silkscreen printing on the PCB. Also check the label on the component – there are many TO92-style transistors which look similar – do not mix them up!

GREEN: The 4.7K preset bias adjustment potentiometer, with label “472”.

PURPLE: Optionally you can install header pins. Many people prefer to solder wires to header pins, rather than in holes. Or you may wish to use header socket connectors. In this case snap off a 2-pin section and a 4-pin section from the supplied 10-pin header, and install them as shown.

## 3.3 Install jumper wires

The jumper wires are necessary to bypass the power modulator circuit, and to bypass the leakage gate circuit. These parts of the full PA kit assembly are not undertaken in this simplified build.

Four jumpers need to be installed as per the following diagram. This diagram shows the PCB holes/pads in green to make it clear where the jumper wires need to be installed. These jumpers can be made using wire offcuts from the installed components or surplus components.

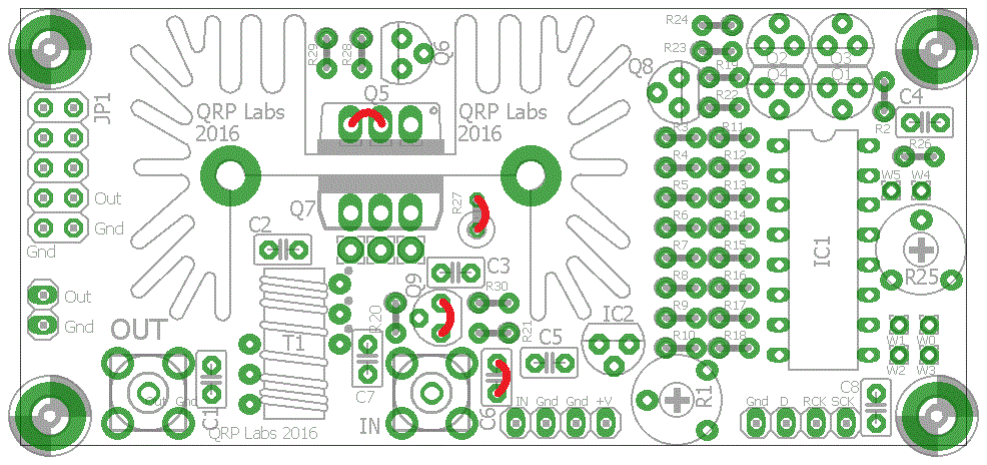
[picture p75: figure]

## 3.4 Install trifilar transformer

The trifilar transformer is installed in the position coloured red in this diagram. The photo (right) shows the board after installing the trifilar transformer. But it is a tricky part of the assembly, so please read and follow these steps carefully.

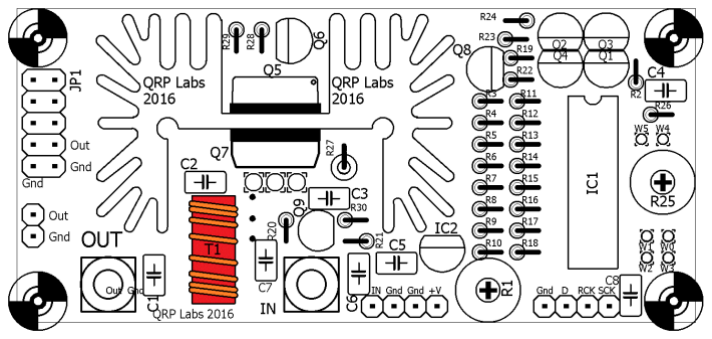
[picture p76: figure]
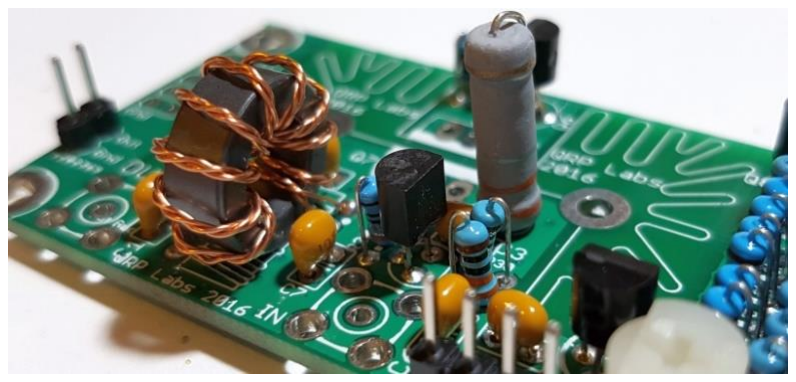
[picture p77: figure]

Firstly, the wire. The best way to un-wind it, without tangling it up, is to think of what the kit-packing person that wound it up did. Then reverse his steps. So, first unwind the tightly wrapped part in the middle where the end of the wire has been secured. Then, open out the spool of wire so that it is a circle. Then unwind the spool, around your fingers, reversing the process of winding it in the first place.

When you have unwound the wire and straightened it, cut it into three approximately equal pieces. These three pieces now need to be tightly twisted together to make the trifilar wire. My method for this is to tie one end in a knot around a small screwdriver shaft. Similarly tie the other end around another small screwdriver. Now clamp one end somehow to something solid. You could use a vice, if you have one. If you don’t, then you have to get creative and think of something. Here I taped it to the edge of the desk. Now you can twist the screwdriver at the free end, repeatedly until you twist the three wires together thoroughly. You need to keep the wire under a little tension to keep the twists evenly spaced.

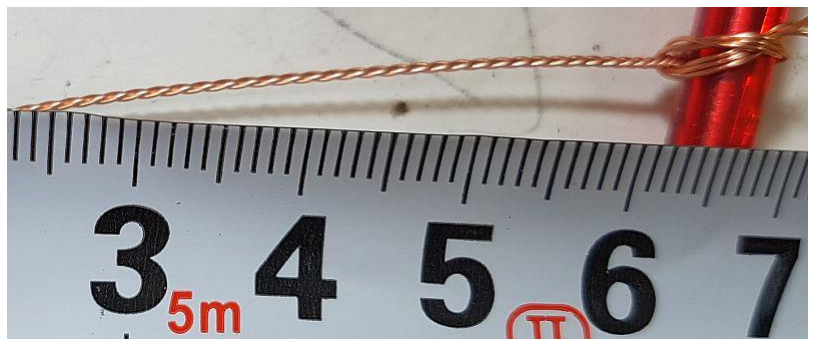
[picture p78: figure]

I put about 70-90 twists into a 25cm length of wire. The end result is something like the photo (right). The measurement scale is in cm.

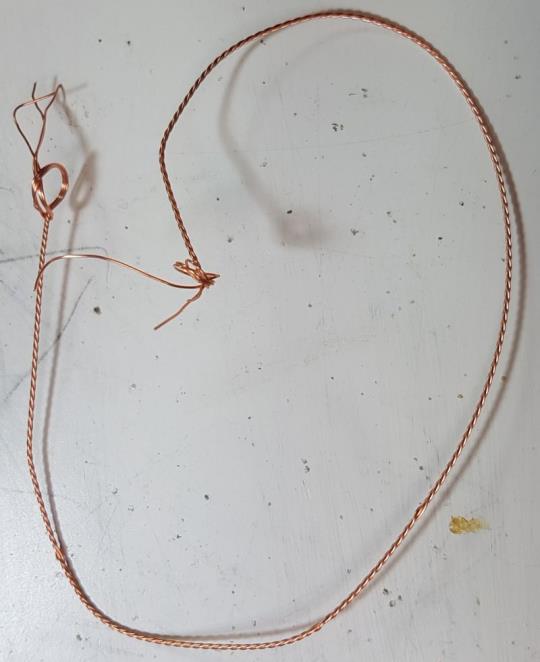
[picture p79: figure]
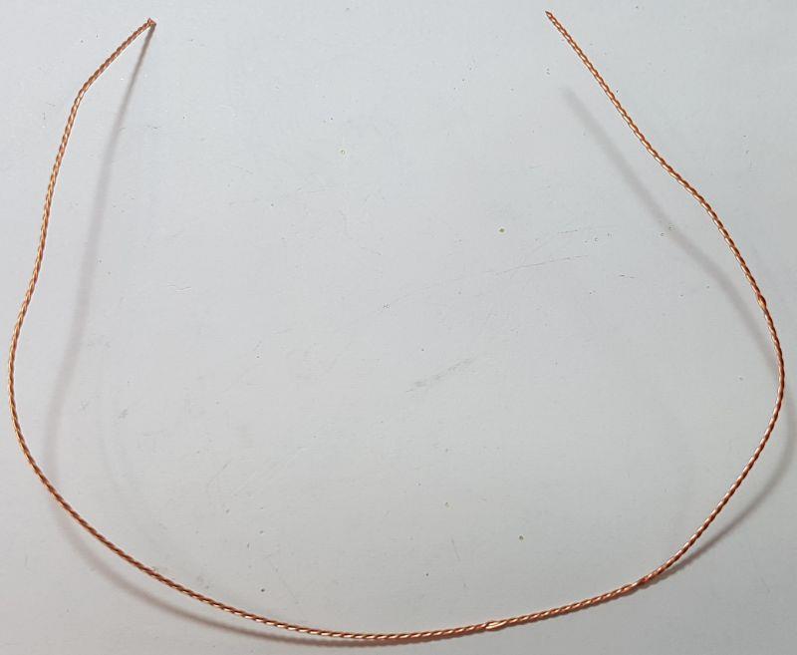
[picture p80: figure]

Now cut off the untidy ends, and this is the piece of wire that will be used to wind the FT50-43 toroidal core as a trifilar transformer.

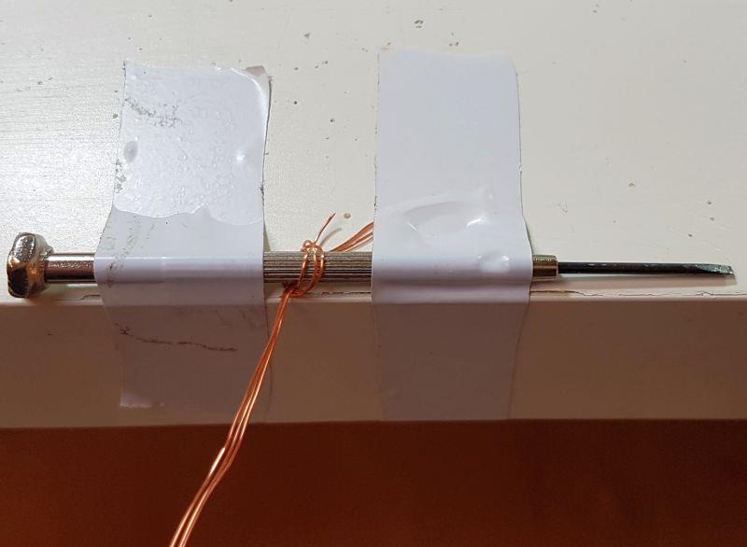
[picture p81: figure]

Hold the core between thumb and finger. Pass the wire first from above, to below. Then take the wire from below, and bring it around to pass through the toroid again to form the second turn. After each turn, ensure the wire is fitting snugly around the toroidal core. Wind 10 turns on the core. Each time through the toroid’s central hole counts as one turn. Cut off the excess wire, leaving about 2.5cm remaining.


Now it’s necessary to identify which wire belongs to which winding. You have three windings twisted together, they all use the same wire. The only way to do this is with a DVM as continuity tester. First, untwist and straighten the wire ends that are not wound around the toroidal core.

Now tin the last few mm at the ends of each wire. You can do this by scraping off the enamel then tinning with the soldering iron; or, hold the wire end in a blob of molten solder for a few (maybe 10) seconds, until the enamel burns off.

Now use a DVM to test for
continuity. Re-arrange the wires
so that there is continuity from A-A, B-B, and C-C in this photo.

Carefully keep this orientation of wires and insert the transformer this way into the PCB. You can carefully cut off those few mm of tinned section of wire, if it won’t fit through the PCB holes. But BE CAREFUL not to lose the
orientation of the wires! The
right wires must be in the right


holes, so that the windings are connected correctly in the circuit!

It’s a good idea to check for continuity A-A, B-B, C-C again with the DVM, just to make sure that you didn’t accidentally mix up the wire orientation while inserting the wires.


Now trim the wires underneath the board, and tin the ends again. The EASIEST way to do this is simply apply solder so that it sits in the hole and surrounds the 1mm of wire ending, and hold the soldering iron in that position for a few seconds until the enamel is burnt away. This tins the wires and solders them to the PCB pads.

You can inspect the joints with a magnifying
glass or jeweller’s loupe. The photograph (right)
shows a joint where the soldering iron has not


been held long enough on the joint. The enamel has not properly burnt off the wire, and there will be no electrical connection to the copper wire. The circuit will not work! So fix it!

You can also test that the wires are properly soldered. Use a DVM to check for continuity (zero ohms resistance) between the indicated points C and A in this diagram and photo. If there is continuity it means that the copper wire is all properly soldered. If not, then go back and check again. You can then check the individual windings to see where the fault lies.



Note that this does NOT necessarily check that you correctly orientated the windings. The only way to do that, was with the DVM continuity check before inserting the transformer; and after identifying the windings, being careful not to mix the wires again while inserting the transformer in the PCB; finally checking again once the wires are inserted but before soldering.

## 3.5 Install heatsink assembly

In this kit the IRF510 transistor final (Q7) is fitted to the metal heatsink. The metal tab of this transistor must not short to ground or to other parts of the circuit. Therefore insulating silicone rubber pads are used, and insulating white plastic washers. In this photo (right) the heatsink is viewed side-on before assembly. The picture shows how the transistor assembly must be put together before soldering.

On the side of the heatsink with the large gap, the silicone pad is placed on the heatsink where the
IRF510 transistor will sit. The transistor is placed
on the silicone pad. The white nylon insulating


washer is pushed into the hole in the transistor tab. The bolt then fits through the hole. The metal bolt does not touch the metal tab of the transistor, and the tab does not touch the heatsink.


In the prototypes I put the bolt on the far side and the nut on the IRF510 side, as shown. Then it is easiest to grab the bolt with pliers while tightening the screw from the other side.

If you have some heatsink compound then this would be a good idea (though the prototypes development and testing did not use it). Take care to align the transistor accurately and tighten the bolt/nut well. You will be rewarded by an assembly which fits easily into the holes on the PCB.

It is difficult to remove and replace transistors later! So before soldering, check once again that the Q7 transistor (IRF510) is in the correct place on the side of the wide opening of the heatsink. Check that everything matches the PCB silkscreen and this diagram (right).

Once the heatsink assembly and transistors are
fitting perfectly into the PCB, you can solder first


the heatsink mounting pins, then the transistor component leads themselves. A high wattage soldering iron may be needed for soldering the heatsink pins, as the heatsink will try to conduct away heat which may lower the temperature of the joint below the melting point of solder. You could leave the heatsink pins unsoldered if it seems troublesome. After soldering the transistor leads, cut off the excess lead length.

Note that the pads for the heatsink mounting pins are not connected to ground (or anything else). The PCB top side has no copper or tracks of any sort under the heatsink; this is to ensure that even if the soldermask accidentally got scratched, there would be no contact between the heatsink and ground or any other electrical connection.

## 3.6 A recommended modification

This modification will be included as
standard on any future PCB revisions. It
involves the addition of a 10-ohm resistor
at the gate of Q7, the IRF510 final PA transistor. The PA does work without this resistor, and indeed it will produce slightly higher power output. However at certain supply voltages and frequencies, instability can occur. When this happens the amplifier superimposes a low frequency oscillation envelope on the wanted RF output. Fitting this 10-ohm resistor resolves this potential problem, at the cost of some power reduction. The measurements made later in this document were made with this 10-ohm resistor fitted.

The modification involves cutting one track
on the BOTTOM side of the PCB, and

soldering a 10-ohm resistor on the bottom side of the PCB. The resistor location is shown in the above circuit diagram fragment which shows the IRF510 PA. The 10-ohm resistor is supplied in the kit and has colour code brown-black-black-silver-brown.


The modification is illustrated in the following diagram and picture.

## 3.7 RD15HVF1 Substitution for VHF operation

The supplied IRF510 transistor works well at HF. However for the VHF bands 6m and above, the gain of the IRF510 in this circuit is very low. If you wish you may substitute the RD15HVF1 transistor or one of its close relatives. These transistors are more expensive but are designed for VHF/UHF power amplifiers and should work well in this circuit.

The pinout of the RD15HVF1 is different to the IRF510! The PCB has a position for the RD15HVF1 transistor if you
wish to use it. If you wish to use
the RD15HVF1 in this circuit,
insert its leads into the set of three holes shown in RED in the diagram. You will need to bend the leads of the transistor outwards slightly, away from the heatsink, so that they are aligned with this set of holes. Take care to insert the transistor leads into the correct holes.


## 4. Connecting and configuring the Power Amplifier kit

## 4.1 Basic connections

The power amplifier kit requires a supply voltage of typically 12 or 13.8V. The amplifier may draw 1 or 1.5A of current so remember to use a well-regulated good quality power supply capable of this. Use thick wires to the PA to avoid voltage drop in the wiring. You may wish to connect an electrolytic capacitor close to the PA kit PCB, particularly if the wires to your supply are long.

The RF input to the amplifier may be connected at the pin header, or you may install an SMA connector for it. If using the pin header, it is a good idea to use a ground connection wire as well as the RF signal connection wire. Thin coax is suitable.

The RF output may be taken from a pin header, or an SMA connector, or the 2 x 5-pin header pads provided. The footprint for the 2 x 5-pin header is provided to facilitate connection to the Ultimate3S kit – if you are using this then please refer to App Note AN004. As usual, remember to connect a low pass filter at the PA output, to attenuate transmitter harmonics.

The 4-pin header with the microcontroller signals that control the 8-bit shift register, DAC and power modulator are NOT used in this simplified construction. They may be left unconnected.

## 4.2 Bias adjustment

Correct bias adjustment is very important! Before connecting power, turn the R1 bias potentiometer completely anti-clockwise (zero volts bias)!

R1 adjusts the bias at the gate of the IRF510 final PA transistor Q7. If the bias is too low, the gain (and power output) of the amplifier will be low. If the bias is too high, the current through Q7 will flow even when there is no signal; this can result in excess power dissipation (though the power modulator circuit removes power to the IRF510
PA final in any case). Efficiency is also reduced and
gain/power output may be reduced also if bias is too high.


Theoretically the ideal bias point for the gate of the MOSFET, is where there is zero idle current through the IRF510 transistor, and where increasing the bias voltage any further would result in idle current starting to flow. This point has optimal power output, if the input signal amplitude is optimum, and it has best efficiency as well as spectral purity of the output. Of course in the real world, everything can (and does) change!

The zero idle current point can be found quite easily if you connect an ammeter (typically a DVM in current measurement mode) in series with the PA kit supply. The adjustment is carried out in the key-up state, or in other words, no RF input (you could disconnect the RF input, for example).

Start with R1 completely anti-clockwise. Observe the current consumption of the PA kit when “idle” (key-up state, not transmitting, no RF input). Then slowly turn the R1 trimmer potentiometer clockwise until you observe a very slight increase in the current consumption. The point where the current just starts to increase is the zero bias point.

An alternative (and arguably simpler) method of bias adjustment is to transmit into a 50-ohm dummy load, measuring power with a power meter or observing on an oscilloscope. Turn the R1 trimmer potentiometer clockwise until maximum power output is obtained, then back off slightly. The bias setting using this method is higher than the zero idle current method. The power output will be higher too.

The gain of the IRF510 amplifier is less at the upper end of the HF bands particularly 28MHz (the 10m band). The input signal is also typically lower, when using for example an Ultimate3S kit as the driver. In these cases, adjusting the PA with a higher bias voltage can improve the gain/power output at the high frequency end of its range of operation.

If using this PA in a multi-band transmitter and desiring maximum power output, you could adjust the bias for best power output on the highest frequency that will be used (for example, 28MHz) where the bias is most critical. The bias setting is much less critical at the lower end of HF.

## 4.3 Heatsink temperature rise; PA kit installation in enclosure

The desired output power of this PA kit in your application has a significant bearing on how you enclose the project. Remember that the heatsink will dissipate a considerable amount of heat. The heat dissipation will cause the temperature of the heatsink to rise. You need to take this into account when deciding what enclosure to use. You may wish to bolt the heatsink to the back of a metal box, for example; or consider a fan to cool the heatsink.

In operation the power modulator transistor will dissipate some heat as it is an imperfect switch; the IRF510 final PA will operate at perhaps 50% efficiency or something like that (dependent on many factors). For a power output of 5W you will therefore be dissipating at least 5W, maybe somewhat more.

Another factor to take into account is the transmission mode you will be using. A continuous key-down transmission using FSK modes such as WSPR, will dissipate a much higher average power than an on/off keyed mode such as CW.


As an example, one prototype here was
operated on continuous key-down on
10MHz, with 13.8V supply using an Ultimate3S transmitter as the driver. The power output was set to 5W using the maximum DAC value (meaning excess power was also dissipated in the power modulator). An overall current consumption of 1.06A was recorded. The assembly was lying on the workbench with no enclosure, and no forced air cooling. It took about half an hour for the temperature of the heatsink to stabilise. By that time it had reached a temperature of 61C which was a rise of 33C above the ambient temperature of the lab. The transmission was switched off after 40 minutes (see chart).

In summary: Enclosing the PA kit in an enclosure will increase the temperature rise; using fan-assisted cooling would reduce it. There are many factors that will influence heat dissipation. The above discussion should be taken as a guideline only – your mileage may (WILL) vary!

## 5. Power Amplifier characteristics

Please refer to section 5 of the full PA kit assembly instructions. The measurements there were made with the full assembled kit. This simplified kit assembly does not suffer voltage drop across the power modulator, nor does it have any attenuation in the leakage gate. Due to this, the output power will be slightly higher with this simplified kit assembly.

## 6. References

- App Note AN004 explains how to use this PA kit in conjunction with an Ultimate3S QRSS/WSPR kit to increase the output power to around 5W, and apply raised cosine RF envelope shaping for a beautiful clean click-free signal. Refer to http://qrp-labs.com/appnotes (http://qrp-labs.com/appnotes)
- For updates relating to this kit please visit the QRP Labs PA Kit page http://qrp-labs.com/pa
- For any questions regarding the assembly and operation of this kit please join the QRP Labs group, see http://qrp-labs.com/group for details

## 7. Document Revision History

- 02-Jan-2017 | 1.0 | Initial revision
- 09-Mar-2017 | 1.01 Corrected typos in toroid core type
- 04-May-2017 | 1.02 Corrected section 3.3 to say four jumper wires (not three)
- 29-Nov-2018 | 1.03 Corrected BS170 in parts list, it is TO92 not TO220 package

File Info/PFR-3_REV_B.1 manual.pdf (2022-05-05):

## The PFR-3 Three band “Portable Field Ready” QRP CW Transceiver 40/30/20 meters Hendricks Kits – www.qrpkits.com KD1JV Designs

## Production manual 6/10/08 Rev B


PFR-3 shown with optional paddle installed. Specifications:

Bands : 40 meters, 30 meters and 20 meters
Tuning range: Full band coverage
DDS VFO with 50 Hz slow tuning rate and 100 Hz fast tuning rate Mode: CW only

Receiver MSD: 0.2 uV typical
Selectivity : 300 Hz
Four crystal IF filter and 600 Hz center frequency audio band pass filter

Receive current, no signal typical:
Active, 47 ma
Idle, 34 ma

Transmitter:
5 watts at 12.0 volts, all bands
Transmitter current: 650 ma (40 M) to 750 ma (20 M) typical at 5 watts. Spurs: - 50 dBc maximum, all bands

5 to 40 wpm internal iambic keyer
Selectable A or B mode
Two (2) 63 character keyer memories.

Coax or balanced line output
Built in BLT (balanced line tuner)

Size: 7.2” wide X 4.2” deep X 1.5” high (less knob height).
Weight: 18 oz, no batteries installed.

Power supply voltage: 8 volts minimum, 12.5 volts maximum. 12 to 9 volts recommend. External power or internal battery pack

# Table of Contents

Group 1 assembly, Microprocessor and display:....5

## DDS frequency calibration and precise BFO

Group 5, SWR bridge and balanced line tuner:....12

## Mounting the board in the cabinet and final wiring:

The difference between A and B modes:.........17

## Using the BLT with end feed wire antennas or

PFR front panel controls and rear panel connectors.

Troubleshooting steps: Divide and conquer....20

Parts check list:

QTY | VALUE | | QTY | VALUE
1 | 10 ohms | Brown, black, black, gold | 1 | 4.7 p or 5p NPO | Disk, brown, black dot on top edge
1 | 51 ohms | Green, brown, black, gold | 3 | 22 p NPO | Disk, brown, black dot on top edge
4 | 470 ohms | Yellow, Violet, brown, gold | 1 | 47 p C0G | Disk, brown, black dot on top edge
11 | 2.2 K | Red, red, red, gold | 1 | 68 p NPO | Disk, brown, black dot on top edge
3 | 4.7 K | Yellow, violet, red, gold | 4 | 100 p C0G | Mono, yellow or NPO disk
1 | 7.5K | Violet, green, red, gold | 6 | 150 p C0G | Mono, yellow
5 | 10 K | Brown, black, orange, gold | 2 | 220 p C0G | Mono, yellow
1 | 51 K | Green, brown, orange, gold | 3 | 330 p C0G | Mono, yellow
5 | 22 K | Red, red, orange, gold | 1 | 560 p C0G | Mono, yellow
4 | 100 K | Brown, black, yellow, gold | 1 | 680 p C0G | Mono, yellow
2 | 330 K | Orange, orange, yellow, gold | 1 | 470 p DISK | Disk, brown
1 | 1 MEG | Brown, black, green, gold | 5 | .001 ufd disk | Disk, brown
1 | 50K audio | Vertical PCB mount | 7 | 0.01 ufd X7R | Mono, yellow
3 | 51 ohm 2W | Green, brown, black, gold | 14 | 0.1 ufd X7R | Mono, yellow
2 | SA612AN | 8 pin DIP IC | 2 | 0.01 ufd film | Film, green
1 | LM358N | 8 pin DIP IC | 1 | 30 p trimmer | Green
1 | LM386N | 8 pin DIP IC | 3 | poly-variable | Variable capacitor, dual section
1 | 74HC02N | 14 pin DIP IC | 2 | 10 ufd /16V or 25V | Aluminum electrolytic
1 | ATMEGA48 | 28 pin DIP IC | 1 | 22 ufd /16V or 25V | Aluminum electrolytic
1 | 78L05 | TO-92 plastic | 2 | 100 ufd /16V or 25V | Aluminum electrolytic
1 | 78L06 | TO-92 plastic | 1 | 330 ufd /16V or 25V | Aluminum electrolytic
1 | 1N5817 | Plastic diode shottky rectifier, 1A | 4 | 8 pin DIP sockets
1 | 1N4756A | Larger glass diode, 47V 1W zener | 1 | 14 pin DIP socket
3 | SD101C | Glass diode, fast shottky | 1 | 28 pin DIP socket
1 | FQPF7P06 | TO-220 plastic P MOSFET | 2 | FT37-43 | Ferrite core, gray or black
5 | 2N7000 | TO-92 plastic N MOSFET | 6 | T37-2 Red | Powdered iron core
3 | BS170 | TO-92 plastic N MOSFET | 2 | T37-6 Yellow | Powdered iron core
1 | 4 dig LED | 4 digit multiplexed display module, hi eff | 1 | T100-2 Red | Powdered iron core
1 | Super bright | LED clear | 4 | 6mmx13mm tack | Push button switch
2 | 10 uhy rfc | Brown, black, black, gold | 6 | DP3T slide switch
5 | 4.9152 MHz | Crystals HU-49US | 2 | Stereo jacks
1 | Power jack | 2.5 mm pin | 4 | Knobs
1 | BNC jack | | 1 | Red filter
2 | Binding posts | 1 Red, 1 Black | 1 | PC board
| | | 3 | | Sets of vari-cap mounting hardware
4 | 1/4” 4-40 screw | | 4 | #4 lock washers
| #30, #28, #24 | Magnet wire, #24 hook up wire | 6 | #4 Nylon washers
| | These parts are premounted
1 | AD9834BRUZ | DDS | 3 | 22 K | 0805 chip resistor
1 | 50.00 MHz clk | Clock oscillator | 1 | 22 p | 0805 NPO chip resistor
1 | 10 uhy | 1206 Choke inductor | 2 | 8 p | 0805 NPO chip capacitor
2 | 1.5 uhy | 1206 Choke inductor | 2 | 150 p | 0805 NPO chip capacitor
1 | 815C35UA | 3.5V low drop out regulator | 1 | 220 p | 0805 NPO chip capacitor
3 | 270 ohm | 0805 chip resistor | 4 | 0.01 ufd | 0805 X7R chip capacitor
1 | 3.9 K | 0805 chip resistor | 3 | 0.1 ufd | 0805 X7R chip capacitor
3 | 10 K | 0805 chip resistor

Parts placement overview.


Print this page out for handy reference while building. SMT parts are preassembled.

Group 1 assembly, Microprocessor and display:


- R16 to R23 - 8 places. 2.2K (RED/RED/RED/GLD)
- R24, R52 – 22 K (RED/RED/ORG/GLD) – be careful not to mix up the 2.2 K and 22 K !
- R25 to R27 – 4.7 K (YEL/VOL/RED/GLD)
- R28 and R29, 470 ohms (YEL/VOL/BRN/GLD)
- C32, 48, C50, C51, 0.1 ufd (104, mono, yellow) [note, there is another C48 labeled on the board]
- C52,C53 0.01 ufd (103, mono, yellow)
- C49, 100 ufd / 16V (or 25V) Long lead is plus. Bend leads at right angle to part and lay part flat to board along extended outline. (You will do this with all the other electrolytic caps on the board too)
- U9, 78L05. Do not mix up with the 78L06 or 2N7000 which are in same TO-92 package.
- 28 pin dip socket at U6 When installing sockets, make sure all the pins are sticking out the holes in the board before soldering. If one or more pins happens to fold over under the socket as you insert it, it will be very difficult to remove the socket to fix this once you start soldering pins! Also make sure the notch is facing the right way.
- LED display module. This will only go in one way due to the missing pins on the display and corresponding missing holes on board. Space the display slightly from board so that the pins only stick out 1/32” from bottom of board. Solder two corner pins first, then double check to make sure the display is evenly spaced from the board and not tilted. Re-heating one pin will allow you to make adjustments.
- S1, S2, S3, S4 - Four (4) TACT switches. These have the long red actuators.

C48 location above SMT parts.


- D5, 1N5817 diode, black body. Band on part goes towards line on part outline.
- C48, 0.01 ufd (103) [C48 designation repeated on board by mistake, this one is located between the phone jacks and is labeled as C30 on schematic]
- Paddle and phone jacks.
- DP3T slide switch. (ON/OFF) – make sure switch is flush to board before soldering more than one mounting tab.
- C35, 10 ufd / 16V (or 25V) Again, long lead is plus and lay down part flat to board. Located above SMT parts, next to the R37 location.

Group 1 smoke test:

- Install the ATMEGA48 microprocessor chip into the U6 socket.
- Connect a 9 to 12 volt power supply to the power input pads next to the on/off switch. A 9 volt radio battery would be adequate for this test.
- Apply power to the board and turn on power switch if it is not already on.
- The LED display should light up with four “8”s for a second. This is the display test. Then the display should display “40” for another couple of seconds (indicating the band), then 030.0 (this is the frequency)
- Clicking closed the Tune UP or Tune DN switches should make the display increment or decrement.
- Clicking the RIT switch should make the left most decimal point on the display light up.
- The DDS chip should also be working at this point. This can be tested with a frequency counter connected to the R39/R41 junction at U7 or general coverage receiver tuned to about 2.115 MHz (+/- 1 kHz) with a short pick up lead for an antenna placed near the DDS chip (U7)

Group 2 Assembly, receiver section:


R15 | 10 ohm | BRN/BLK/BLK | C3 | 4.7 p or 5p | NPO, DISK | BROWN
R1 | 51 ohm | GRN/BRN/BLK | C4,C27 | 22 p | NPO, DISK | BROWN
R3 | 470 ohm | YEL/VOL/BRN | C7,11,13,14 | 100 p (101) | C0G | YELLOW
R13 | 2.2 K | RED/RED/RED | C8,9,10,79 | 150 p (151) | NPO, DISK | BROWN
R9 | 7.5 K | VOL/GRN/RED | C21 | 470 p (471) | DISK | BROWN
R4,R5,R11,R12 | 10 K | BRN/BLK/ORG | C17,18,77,78 | .001 u (102) | DISK | BROWN
R8 | 51 K | GRN/BRN/ORG | C22, C23 | 0.01 u (103) | FILM | GREEN
| | | C5, C12 | 0.01 u (103) | MONO | YELLOW
R10 | 100 K | BRN/BLK/YEL | C6,15,19,20 | 0.1 u (104) | MONO | YELLOW
R6,R7 | 330 K | ORG/ORG/YEL | C25,26,28 | 0.1 u (104) | MONO | YELLOW
R14 | 1 MEG | BRN/BLK/GRN | C24 | 10 u/16V or 25V | LAY FLAT | ELECTRO
L2,3 | 10 uHy | BRN/BLK/BLK/GLD | C29 | 22 u/16V or 25V | LAY FLAT | ELECTRO
| | | C31 | 100 u /16V or 25V | LAY FLAT | ELECTRO
D1,2 | Glass diode | SD101
U5 | 6V reg | 78L06 | Q1,2,3,4 | 2N7000 | MOSFET
NOTE: L2/L3 look like resistors, but the body is a little shorter and fatter. Do not mix up with 10 ohm resistor. Also, be careful not to mix up 51 ohm resistor with 1 MEG, as colors are very similar.
X1,2,3,4,5 | Crystals | Tack solder case to solder pads next to crystal case. Running fine grit file along
| | edge of crystal case will make the solder easier to stick.
C16 | 30 p trimmer (Green) | Make sure flat side of trimmer faces line on outline. This can be mounted to bottom side of board for easier access once board is wired into cabinet.
U1,2,3,4 | 8 pin sockets | Make sure all the pins come through the board holes!
V1 | 50 K variable resistor | Solder mounting tabs to board.
| The following parts | mount on Bottom of board
C1/2 | Poly-varicap | Mounts on bottom of board. Use 2.5 mm washers between board and cap.
L1 | T37-2 (red core) | 40 turns, 24” of # 30 wire
T1 | T37-2 (red core) | 40 turns (#30) secondary, 5 turns primary see next page for winding details.

L1 and T1 are mounted on the bottom side of the board!
T1 winding: Wind with # 30 wire. T1 must be wound in a specific way so that the “hot” end of each winding will end up on the same side of the core and line up with the proper holes in the board. Wind the core in a counter clockwise direction, passing the wire down into the hole from the top side of the core as you hold it. At the end of 40 turns, make a short loop and continue winding five (5) more turns. The start and end wire ends will go into the two pads towards the top edge of the board, with the start end going into the pad labeled “S”. The wire which makes the loop will be sniped to separate the wire and these go into the two


holes towards the center of the board. It is important to get the windings in the proper holes or the receiver sensitivity will be poor.

## Group 2 smoke test:

Install U1 and U2 (SA612A) into sockets
Install U3, LM358
Install U4, LM386 NOTE : U4 pin 1 faces “down”, the opposite direction of U1, U2 and U3

The receiver section is now done and should now be functional. Give the BFO trimmer (C16) about a ¼ turn from its factory setting. If you look closely in the trimmer hole, you will see an arrow at one end of the screwdriver slot. When the arrow points towards the flat side of the body, it is a maximum capacitance. When it points to the round end opposite the flat end, it is at minimum. Using leads connected to the BNC connector, you can tack these wires across R1 in order to connect up an antenna (make the connections on the bottom of the board). The end of R1 near Q1 is the signal side of the resistor. Apply power to the board and you will be receiving in the 40 meter band. Adjust the Rx tuning cap (C1/2) for best band noise or signal. The peak should occur near full counterclockwise rotation. Plugging in a paddle to the paddle jack and then operating the paddle should result in hearing the side tone sending dits and dahs. The MENU function switch annunciations can now also be heard.

DDS frequency calibration and precise BFO setting adjustment:

If you have an accurate frequency counter, the DDS frequency can be calibrated. Without calibration, the operating frequency maybe off as much as +/- 200 or 300 Hz on the 20 meter band and to lesser extent on the lower bands. This is due to variations in the reference clock oscillator for the DDS chip. Calibration is done at 10.000,000 MHz, so it could be possible to zero beat WWV, but it is better left alone if an accurate frequency counter is not available. It is also possible to tweak the IF offset frequency so that it is centered in the passband of the crystal filter. This adjustment is done with the aid of an Oscilloscope, which could be a virtual one running on PC, as all you need to see is audio frequencies. The IF offset adjust mode is also used to set the BFO trimmer to match the side tone of the rig and this can be done by ear.

Entering Calibration modes:
While holding the DOT paddle and MENU switch closed, turn power on to the board. The LED display will read [CAL.r].

Reference frequency calibration:

A frequency counter connected to the TP1 test point near the DDS chip will now read about 10 MHz. Use the Tune up and Tune down switches to adjust the frequency to be exactly 10.000,000 MHz. Once this is done, store by clicking the KEYER switch. Or you can skip this adjustment by clicking the KEYER switch. This will store the default values and advance to the offset adjustment

IF offset adjust and BFO trimmer set:

Once the MENU switch has been clicked, the LED display will now read [CAL.o]. Connect an Oscilloscope to Pin 7 of U3. You will see the audio product detector beat note on this pin. If you do not have an Oscilloscope, do not make any adjustments to the IF offset frequency and just go do the BFO adjustment.

Tune through the pass band of the crystal filter using the tuning switches. You will likely see the amplitude of the signal peak a little at the edge of the pass band, just before the amplitude rolls of sharply. Tune to one end of the pass band, the point the amplitude of the signal starts to roll off. Count how many clicks of the tuning switch it takes to get to the other end of the pass band. Divide that number by 2 and tune back up or down depending on which way you went initially by that number of clicks to center the frequency in the pass band of the filter.

BFO adjustment:

Plug headphones into phones jack and you will hear the side tone and BFO beat note. Adjust the volume control until they have about the same volume. Adjust the BFO trimmer until both tones are the same. The tones will wobble when they get close to being equal and seem to merge when they are. This can also be seen on an Oscilloscope. Once you match the tones, store the adjusted IF offset or leave the default values in place by clicking the MENU switch The rig will now reset.

Group 3 assembly: Transmitter section.


Pretests:
Before installing L7, we need to make a few tests first.
- Make sure R37 is 100K!
- Put rig in straight key mode by applying power with dash paddle closed or use straight key. If using paddle, dot paddle will now key the transmitter.
- Measure the voltage on pins 3 and 11 of U8. They should read about 3.5 volts. If not, check soldering of R37 and check for 5 volts on pin 14.
- Measure the voltage on pins 1 and 13 of U8. They should read 0 volts.
- Key the transmitter and measure the voltage on the L7 pad to the right, next to C57. The voltage should be about the same as the supply voltage to the board. If not, check the connections and proper values of R34, R35 and R36. Also check Q5.
- With the transmitter keyed, check the voltage on pins 1 and 13 of U8 again. These should now read about 2.5 volts. Since these pins now have a square wave at the transmitter frequency on them, exactly how a DVM responds to this signal may depend on the particular DVM used.
- If all these tests are OK, it is now safe to install L7.
R53 | 2.2 K | RED/RED/RED
R35, 36 | 22 K | RED/RED/ORG
R2,R34,R37 | 100 K | BRN/BLK/YEL
D6 | Not used
D7 | 1N4756A | Glass diode, large
C54 | 0.01 ufd (103) | MONO, Yellow
C55, 57, 58 | 0.1 ufd (104) | MONO, Yellow
C59 | .001 ufd (102) | Disk, brown
C56 | 330 ufd/16V or 25V | Electro lay flat
Q5 | 2N7000 | TO-92
Q7,8,9 | BS170 | TO-92
Q6 | FQPF7P06 | TO-220
U8 | 14 pin socket | 74HC02A IC
DO NOT | MOUNT L7 YET | Do pretests first
L7 | 8 T on FT37-43 | 8” #28 black core

Group 4, low pass filters:


R30 | 2.2 K (RED/RED/RED)
R31 | 10 K (BRN/BLK/ORG)
R32 | 22 K (RED/RED/ORG)
C76 | 0.01 ufd (103, mono)
C68,C71 | 150 pfd (151, mono)
C67,C64 | 220 pfd (221, mono)
C69,C63,C60 | 330 pfd (331, mono)
C65 | 560 pfd (561, mono)
C61 | 680 pfd (681, mono)
C62 | 68 pfd (68, disk)
C66 | 47 pfd (47, disk)
C70 | 22 pfd (22, disk)
Low pass filter | Coils mount from bottom | Of board!
L8 | 17 turns on T37-2 | Red core 10” #28
L9 | 19 turns on T37-2 | Red core 10” #28
L10 | 13 turns on T37-2 | Red core 8” #28
L11 | 15 turns on T37-2 | Red core 8” #28
L12 | 14 turns on T37-6 | Yellow core 8” #28
L13 | 18 turns on T37-6 | Yellow core 10” #28
S5, S6 | DP3T slide switch

Group 5, SWR bridge and balanced line tuner:


- R48, 470 ohm (YEL/VOL/BRN)
- R49, R50, R51 - 51 ohm, 2 watt (GRN/BRN/BLK)
- D3 – SD101, small glass diode
- D4 – clear LED – Align flat side of LED with flat on part outline. Long lead goes into hole opposite the flat. Space bottom of LED 5/16” from top of circuit board.
- S7 – DP3T slide switch
- S8 - DP3T slide switch
- S9 – DP3T slide switch – this mounts above T3. Cut pins flush to board after soldering.
- T2 – Black FT43-37 core. Use # 28 wire and wind 25 turns as secondary and 5 turn primary in middle between ends of the secondary turns. Secondary ends go to into the two outside holes and the primary goes into the two middle holes.
- T3 – Mounts on bottom of board. Core is about same diameter as the mounting holes for the wire connections. See below for winding and mounting details.
- C72/73 and C74/75 Poly-variable capacitors. Mount on bottom of board with 2.5 mm washers on screws between board and body of capacitor. These washers space the body of the cap slightly from the bottom of the board. Adjust the trimmers on the bottom of C74/75 to be fully meshed.

Winding T3:

- Cut a 30” (2 1/2 foot) length of the # 24 wire.
- Wind 11 turns on the T100-2 core (this is the large red core)
- Start the winding of the core by passing the starting end of the wire into the hole from the top (side facing you as you hold it) and wind by passing the long end of the wire up from the bottom of the core. Wind the rest of the turns in a counter clock wise direction. Winding the core in this fashion will make the ends of the wire more or less line up with the staggered holes in the board. Try to wind the wire fairly flat to sides of the core.
- Pull the 6th turn slightly away from the middle, outside edge of the core. (this is actually turn 5 ½)
- Scrape away the insulation on the wire of this 6th turn, just a little near the middle of the core.
- Cut a 2” length of the # 24 wire and tin one end.
- Attach this wire to the 8th turn on the core. Make a small, half loop on the end of the wire and lightly crimp to wire on core, then solder.
- Cut a 18” length of the # 24 wire and wind 6 turns inter-weaved between the first winding and centered around the tap you just made, so there are 3 turns on either side of the tap. It is easiest the start the winding of these turns from the center tap of the first winding.
- Now cut a 8” length of the # 24 wire and wind 1 turns on either side of the tap, for a total of 2 turns. This winding will also be inter-weaved between the other two windings.
- Push the windings together so they are close to each other and not spaced around the core.
- The core is mounted to the bottom of the board and the wires are soldered from the top. Suspend the core slightly off the bottom of the board so that the wires do not touch the ends of the switch mounted above it. In fact, it is a good idea to snip the ends of the switch terminals flush to the board before mounting the coil. Be careful not to put the High Z winding into the pads marked “OUT”, as these pads will connect to the binding posts on the cabinet.


This diagram shows how the wire should be wound on the core so the wire ends more or less line up with the mounting holes in the board. The LZ winding is shown with an extra 2 turns.

## Final tests:

The board is now complete and the only thing left to test is the transmitter. Connect the BNC jack to the COAX terminals on the board by S9. Now connect a watt meter and dummy load to the jack. Make sure both BAND switches are set to the same band, you might as well start with 40 meters. Set the Tune / Operate switch to the operate position and the COAX / BLT switch to the coax position. Apply power to the board and send some dots. There should be some power output showing on the watt meter. If not, remove power and start looking for missing solder connections, that the insulation on the toroid coils has been soldered through and that both band switches are in the same position. If you see power output, go on and check the other two bands.

Power output
Power output is influenced by both power supply voltage and the way in which the turns on the transmitter low pass filter coils are spaced around the core. To measure full power output, put the rig in straight key mode or use “Tune” mode. With a 12.0 volt supply, power output should be close to 5 watts on all bands, with the possible exception of 20 meters, which seems to be running more like 4.5 watts on average. If power output is higher than 5 watts, move some of the turns on L8, L10 or L12 (depending on the band) closer together and recheck the power output. Repeat if needed to get close to 5 watts output. If power out is less than 5 watts, try making the spacing of the turns more evenly spaced around the core. If power output is significantly lower (or higher) than it should be, double check the number of turns on the coils. Remember, a turn is each time the wire passes through the center of the core. Having one extra turn is common, as many forget to count the first turn when the wire is initially passed through the center of the core. This can have a significant affect on the power output.

## Mounting the board in the cabinet and final wiring:

It is possible to enlarge the holes for the three tuning caps with a step drill so that the knobs are recessed and reduce the overall height of the rig. You will also need to cut down the nylon spacers and screw. If you decide to do this, be careful – you don't want to scratch the paint job on the cabinet!
- Solder the end of a 4.5” length of hook up wire to each of the pads labeled “OUT” under T3. These wires attach to the bottom side of the board. Since T3 covers these holes, the solder connections are made from the top of the board.
- Tape the red acetate filter to the inside of the led window.
- Slide the board into the top piece of the cabinet at an angle with the phone jacks at the front of the board down. To ease mounting, place all slide switches to the center position. Be careful not to bend the SWR led.
- Center the phone/paddle jacks in the chassis holes, and secure the board with the 4-40 x 1/4” screws and lock washers.
- Attach the nylon spacers to the tuning caps with the screw and 2.5mm lock washer. A small drop of super glue into the screw hole on the tuning cap will help keep the screw from coming loose. (You may want to wait until you are sure you will not have to remove the board from the cabinet for some reason before gluing the screw in place)
- Push the brass knob extension all the way down onto the volume control and secure the knob with the set screw. (Personally, I prefer not to use a knob on the volume control, KD1JV)
- Place the three knobs on the tuning caps. Set the knob as low as it can go without rubbing against the cabinet
- Mount the two binding posts, DPDT toggle switch, Coax jack and external power jack to the rear of the cabinet.
- Wire up the binding posts, switch and coax jack as shown in the diagram below. The wires going from the coax jack back to the board should be tightly twisted together and take a direct path back to the pads on the circuit board. The red wire between binding post, switch and coax connector is optional.


- Twist two 8” lengths of hook up wire together.
- Solder to external power jack
- Solder the other end to the EXT and GND pads next to the On/Off switch
- The wire for connecting to the power jack to the board should be routed along the outside edge of the board.

Once the wiring from the board to the rear panel is completed it is still possible to remove the board from the cabinet but it is a little tricky to do. Remove the mounting screws and gently push the board towards the rear of the case to free the phone jacks from the holes in the front of the case. Then gently angle the board up. When remounting the board, the main problem might be getting the SWR LED to line back up with the hole.

Photo of final panel wiring


Battery holder mounting:


Mount battery holder to bottom of cabinet as shown below. These are attached to the bottom side of the cabinet with double sided tape, which is already attached to the bottom of the holders. Leave a small space between the sides of the battery holders as when the batteries are installed it will billow out the sides a little. Connect wires to the battery holder terminals as shown the diagram below. Be quick about soldering the wires, as the plastic will melt if you leave the iron on too long. Wire the [+] terminal to pad labeled “BAT” next to power switch and the [-] terminal to the pad labeled “GND”

Fuses:

There are no fuses built into the rig but it is a good idea to add one. A fuse could prevent damage to your power supply or even a fire if something should go wrong. For the external supply, use a power cord with an in-line fuse holder and use a 1.5 or 2 amp fuse. Adding a fuse to the battery pack is a bit more of a problem. A 2AG sized fuse holder could be added to the bottom half of the cabinet just above the battery pack and located so it sits between the power jack and receiver input coils.

## Operation:

Power supply:

The PFR-3 rig should be powered by no more than about 12 volts and no less then 8 volts. Maximum supply current at full transmitter output is typically less than 800 ma. If a 13.8 volt bench supply is used to power the rig, two silicon rectifier diodes should be added in series with the positive supply lead to drop the voltage down closer to 12 volts. This will ensure the rig does not put out more than about 5 watts. 5 watt output at 12 volts was chosen as this is the typical voltage a gel-cell battery settles down to after it has been removed from its charger. Below 8 volts, the 6 volt regulator for the receiver will start to loose regulation. Since transmit power output is dependent on supply voltage, a variable supply is a handy way to adjust the power output level. At the minimum supply voltage of 8 volts, the transmitter will deliver about 2 watts output. Transmitter current will also be reduced at lower supply voltages, extending battery life.

Power switch:

The power switch has three positions. OFF, Internal (battery) power and External power.

When the rig is first turned on, the display will show all “8”s for a second. This is the segment display test. Then the display will indicate the currently selected band , “20”, “30” or “40”. The band numbers will be displayed for a couple of seconds, then the display will change to show the operating frequency. Since only four digits are available, only the 100 kHz to 100 Hz digits are displayed. MHz digits are implied by the currently selected band. The initial operating frequencies loaded when the rig is powered on or the band is changed are 7.030,000 MHz for 40 meters, 10.110,000 MHz for 30 meters and 14.060,000 MHz for 20 meters.

Power save mode:

After about 5 minutes of no switch activity the rig will go into a power save mode by blanking the display and the processor is put to sleep. The decimal point will stay on to indicate that the rig still has power applied. This will reduce the supply current from about 47 ma to 34 ma. Not a huge current savings, but if the rig is being run on batteries every ma counts. The rig will “wake up” if any switch (other than Band) or the paddle is used.

### Selecting operating band:

Two slide switches are used to select the operating band. Both switches MUST be in the same band position for proper operation. The band switch located near the top, center of the cabinet tells the processor which band you want to use and will indicate the selected band on the display for a second when the band is changed or on power up, as noted above. The switch located near the top, left of the cabinet is used to connect the output of the low pass filter to the antenna. If the two band switches are not in sync, there will be no signals in the receiver and the transmitter might be damaged if you transmit at this time. If you change bands and then return to a previously used band, the frequency the rig was tuned to on that band will be restored. This feature could be handy if your jumping between bands in a contest. Operating frequencies are lost when power is turn off and the rig will load the default frequencies again on power up.

After you change bands, you must re-peak the receiver input with the Rx peak control.

## Tuning:

Tuning is done with two push button switches. These switches are operated best by “clicking” them to the side, rather then pushing straight down. Tuning steps are in 50 Hz increments. A momentary click of the switch will change the frequency by 50 Hz. Since the display only has 100 Hz resolution, it will take two clicks of the switch to see a change of frequency on the display. Holding one of the tuning switches closed for longer than about one (1) second will start an auto tune mode, where the frequency will change in 100 Hz steps at a rate of about 10 steps per second, so long as the switch is held closed.
When the switch is released, normal 50 Hz “one click” tuning is restored.

Note: If you are in the fast tuning mode and quickly change tuning directions, the tuning may continue the direction that it was in. This is because there is a slight delay between releasing the switch and the processor detecting that a different switch has been closed.

Tuning limits:
Tuning is restricted to be within the currently selected ham band. This is to prevent out of band transmission. Full band coverage is available. 7.000,000 to 7.300,000 on 40, 10.100,000 to 10.150,000 on 30 and 14.000,000 to 14.350,000 on 20. Even though you can tune into the phone band, SSB signals will not be intelligible due to narrow CW filter.

RIT (receiver incremental tuning)

Clicking the RIT switch will activate RIT. The left most decimal point on the display will light when you are in RIT mode. When in RIT mode, the receive frequency is changed by the tuning switches and the transmit frequency stays were it was when RIT was activated. Clicking the RIT switch again will exit RIT mode and restore the original receive frequency. If RIT is on when the band is changed RIT will be automatically turned off.

DFE mode (direct frequency entry)

This mode allows you to go directly to a specific frequency by entering it in with the paddle. Clicking and holding closed the RIT switch for longer than one (1) second will activate this mode. The display will change to display [- - -.-] when DFE mode is enabled. Enter the frequency you wish to go to, starting with the 100 kHz digit and finishing with the 100 Hz digit. As each digit is entered, it will be shown on the display and shift from right to left as additional digits are entered. If a number is not recognized, a “?” will be sent by the side tone. Once the 100 Hz digit is entered, the rig will re-tune to that frequency provide it is within the normal tuning limits of the current band. If it outside the band, the frequency at which the rig was tuned to when DFE was enabled will be restored and DFE mode exited. If you make a mistake or wish to exit the DFE mode at anytime before the 100 Hz digit is entered, you can escape by clicking any of the switches.

Note: DFE mode is not available in straight key mode or if RIT is on.

MENU switch (Keyer functions) :

The MENU switch is used to access various keyer functions. Which function is selected is determined by how long the switch is held closed. Keyer functions are selected in this order: send message, change keyer speed, TUNE mode, enter messages and select iambic A or B mode of operation. Note: When in straight key mode, none of the MENU switch functions are available, with the exception of sending keyer message 1, assuming a message is already stored in that location.

Sending a Message:
Two, 63 character (including word spaces) Morse messages can be stored in memory. One of these messages can be sent by first clicking and releasing the KEYER switch and then tapping the DOT paddle to send message one, or tapping the DASH paddle to send message two. This must be done within 1 second of releasing the switch or the change code speed mode will be activated. Once a message has started sending, it can be terminated by closing the DOT paddle. If a character is being sent at the time of dot or dash closure, it must be held closed until that character has finished being sent.

When in straight key mode, only message 1 is available, as the DASH input is always grounded by the straight key plug.

Changing keyer code speed:

If sending a message has not been selected using the paddle after clicking and releasing the MENU switch, speed change mode will be activated. The current code speed is shown on the display as [C xx], where xx is the current speed. Keyer speed is changed by closing either the DOT paddle to increase speed or closing the DASH paddle to decrease speed. The selected speed is shown on the display. Once the desired speed is indicated on the display, release the paddle and wait about two (2) second and speed select mode is automatically exited.

Tune Mode:
This mode is used if you have an automatic antenna tuner which needs to see a steady carrier for a few seconds to operate. For manual tuners, it is easier and less stressful on the PA to simply send a string of dots as you fiddle with the tuner.

To enable tune mode, click and hold close the MENU switch until the letter “T” is annunciated by the side tone and release the switch. When you then release the MENU switch, the display will blank and a character which resembles a lower case “t” will appear on the left most digit. The transmitter can now be keyed by closing and holding closed either the dot or dash paddle. When you wish to return the rig to normal operation, click any of the switches.

Storing a message:

Holding closed the MENU switch for four (4) seconds will active the message entry mode. Release the switch when the letter “M” is annunciated by the side tone, which occurs after the tune mode letter “T” has been annunciated. The receiver is then muted and you can now start to enter your message by using the paddle. If you accidentally activate this mode and do not wish to enter a message, click the MENU switch to abort before touching the paddle. The Letter “X” will be annunciated and the rig will go back to normal operation. There is no visual indication that message entry mode is active.
Up to 63 characters (including word spaces) may be entered. If you exceed this limit, the letters “EM” will be annunciated by the side tone and you will have to start again. Note that “ideal” letter and word timing is used to determine letter element groups and word groups. Of these two, the letter timing is most critical. If do not pause long enough before starting a new letter, a letter space will not be detected. If you pause too long, it will be interpreted as a word space. It may take some practice to enter a message correctly. I ensure a word space is inserted, it is best to pause somewhat longer than you normally would between word letter groups.

When you have finished entering the message, click the MENU switch. The message you have entered will be sent by the side tone so you can check the accuracy of the message. If it sounds good, store it by closing either the DOT or DASH paddle. DOT will store it into message location 1 and DASH into location 2. If you wish to redo the message, click the KEYER switch again. “EM” will be annunciated by the side tone and you can now re-enter the message.

Selecting Iambic A or B modes.
Iambic A mode is the default keyer mode. To switch to B mode or back to A mode, hold the MENU switch closed for about four (4) seconds until the letter A or b appears on the display (b looks like a 6 on the display) then release the switch. The letter which appears on the display will be the mode the keyer will be set to when you release the switch. The Morse letter “A” or “B” is also annunciated by the side tone.

The difference between A and B modes:
In A mode, if both paddles are closed at the same time, alternating code elements are sent. If you close the dash paddle first and then hold both the dash and dot paddle closed, the keyer will send dah-dit-dah-dit-dah so long as the paddles are held closed. When the paddles are released, the keyer will simply stop sending at the end of the code element which might be being sent at the time the paddles are released, if any.

In B mode, alternating code elements are also sent when both paddles are closed, but this time an extra and opposite code element will be tacked on the end of the string when the paddles are released. Therefore, to send a letter such as “K”, you just have to close the dash paddle first, then close the dot paddle and release both paddles when the dot starts to be sent. dah-dit-dah will be automatically sent. In A mode to send this same letter you would have to keep the dash paddle closed until the second dash has started to be sent before releasing the paddles.

In B mode, the “both paddles closed” condition is sensed at the end of the inter-element space. Therefore, to insert an extra element, both paddles need to be held closed at least until the next to last element you want to send is has started. If the “both paddles closed” condition is sensed any earlier, it is nearly impossible to send a simple letter such as an “A” or “N” and not have a “R” or “K” be sent instead. Even so, it is easy to accidentally add an extra element if your not quick to release the paddles which makes B mode a bit difficult to get the hang of with out a lot of practice, especially at higher code speeds.

Both A and B modes have dot and dash memory while an element is being sent. So, if you tap the dot paddle while a dash is being sent, the dot will be sent after the dash is finished and vice-a-versa.

Straight key mode:

If a monaural plug is in the paddle jack at power up (the sleeve grounds the dash input pin), the rig will power up in straight key mode. This allows using either a straight key or external keyer. While in straight key mode, none of the keyer switch functions will be available. If a message has been previously stored in the keyer memories, only memory location 1 will be available, (tap the straight key closed with in 1 second of clicking the keyer switch) as this is selected with the dot input pin, now controlled by the straight key.

Using the SWR bridge and BLT tuner:
Note that S7, S8 and S9 are three position switches but only two positions are used. The two positions to the left are the same.

TUNE / OPRT SWITCH:

Sliding S7 to the TUNE position switches in the SWR bridge. The LED will now indicate the relative amount of SWR. The brighter the LED, the higher the SWR is. When the LED is not lit or is very dim indicates 1:1 SWR.

COAX / BLT SWITCH

S8 is used to switch between a direct coax connection to the BNC jack or the BLT (balanced line tuner). The Coax position is of course used if you are using a resonate, coax feed antenna or an external tuner. The BLT position is used when the built in tuner is desired and is normally used with ladder line feed antennas, but can also be used for end feed antennas or possibly matching coax feed antennas which need a little tweaking.

Using the BLT:

Note: The handle of the switch on the rear panel should be slanted towards the coax jack when using either a balanced line on the binding posts or just a coax feed antenna.

Before transmitting, adjust the TUNE and LOAD capacitors for best band noise or signal strength. Now switch from Operate to Tune mode with S7. Now transmit a string of dits or dahs and fine tune the TUNE and LOAD capacitors so that the SWR LED gets very dim. This of course, is easier said than done. The tuning is very sharp and if you tune too fast you will never see the LED get dim. A further complication is the Load and Tune controls are interactive.

First slowly adjust the LOAD until you see even the slightest dimming of the LED. Now adjust the TUNE and see if you can make it even dimmer. Go back to LOAD and see if this will dim the LED farther. If no farther improvement can be made, advance the TUNE slightly (try clockwise first) which will make the LED brighter again, then try the LOAD. Working back and forth a few time between the Tune and Load controls should enable you to make the LED become very dim or go out completely. In most cases when using a ladder line feed antenna, you will use the HI-Z setting of the BLT. In some cases, you may only be able to find a match using the Low-Z setting.

Once you find the match, you might want to mark the positions of the controls on the panel using some stick on dots. This will speed up retuning after switching bands.

Using the BLT with end feed wire antennas or coax.
Switching the handle of the rear panel switch so it faces the binding posts will ground the black balanced line binding post and connect the Red post to the coax jack. End feed wire antennas can now be connected to the Red binding post and a counter pose to the Black post. Use the High Z position of S9 if the wire is near a 1/2 wave in length. Use the Low Z position if the wire is near a ¼ wave or less in length. The Low Z position is also used when using the BLT to match a coax feed antenna.

Using a speaker instead of headphones:

The amount of current the audio amplifier can deliver to a speaker is limited by the current available from the 78L06 regulator. A small, efficient speaker at low or modest volume should be alright. However, it would be a good idea to use an amplified speaker such as those used for PC sound, as this would keep the load on the PFR audio amplifier to a minimum.

Also, since the PFR does not have AGC, be careful when using in-the-ear “ear bud” type headphones. Turn the volume control down when tuning across the band so that if you run across a strong station, it does not blow your ears off!

Paddle wiring:
The paddle jack uses “standard” wiring:

Tip is Dot
Ring is Dash
Sleeve is ground

There is no paddle sense reverse built into the firmware.

PFR front panel controls and rear panel connectors.


## Troubleshooting:

With careful assembly, your PRF-3 kit should work right off. Unfortunately, this is not always the case and some troubleshooting will be required. This job goes a lot quicker if you have a signal generator, Oscilloscope and frequency counter, but alas, most of you will only have a DVM to work with.

The most common reason a kit does not work is because of assembly errors, the most common being soldering issues. Soldering issues include missing solder connections, solder shorts between pads which are not connected together, not using enough heat in places so solder only sticks to a component lead and does not flow into the solder pad and not properly tining magnet wire leads so there is no continuity through a coil. Less common but still something to look for is miss-placed parts. It is often easy to miss-read the color codes on resistors, especially those with similar colors, but in a different order.

The above problems can often be found with a simple but careful visual inspection of the board. It does help to have an idea of which general area the problem maybe in as to narrow down the search.

Bad parts:
All new, prime parts are supplied with the kit. It is very, very unlikely any were bad prior to installation. Unless the part was physically damaged during assembly, it is safe to assume the part is good. However, some parts, in particular, the 2N7000 and BS170 MOSFETs can be damaged by static while handling and soldering. Some of the ICs can be damaged if they are installed backwards in the socket and power applied. However, since the regulators which supply voltage to the ICs have limited current capability and have over current shut down, it is quite likely the IC will survive being installed backwards.

## Troubleshooting steps: Divide and conquer

The best way to find out what doesn't work is to first find out what does work. The first step is to make sure proper power supply voltages are present. If the output of a regulator is lower than it should be and/or the package is getting hot, something is dragging the output down. This could be caused by one of the aluminum electrolytic capacitors being installed backwards, a solder short or an IC plugged in up side down.

The next step is to check the voltages on the IC pins. If one or more of these voltages are off significantly, it may not mean the IC is bad, but something is affecting the voltage on that pin. Before asking for a replacement part, check the parts connected to those pins and of course, the soldering in that area.

If you still have a problem, its time to start tracing the signal paths. For the receiver, it is easiest the start with the output and work towards the input. For the transmitter, start at the input and work towards the output.

Group 1, the processor and display:
There is very little go wrong here. If the processor is getting it's +5 supply, it should work. Although there could be problems with things connected to the various input and output pins which will affect it's operation. If there is a missing segment or digit on the display, it is likely there is a missing solder connection or short. The same is true if a paddle or the switches don't work or there is a “stuck switch” problem.

Group 2, the receiver:
The audio stages are very easy to test. You should hear some “hiss” when the volume control is turned all the way up and you should hear the side tone when using the paddles. You should be able to hear 60 cycle hum if you touch pins 4 and 5 of U2 with your fingers. If you hear the side tone but not any hiss or hum which touching pins 4 and 5 of U2, the mute switch Q4 might be shorted out. If the voltages on pins 3 and 5 of U3 are not correct, C24 might be in backwards or the R7 and R12 values interchanged.

The crystal filter and U2 product detector/ BFO oscillator is tested when using the DDS offset calibration mode. There is little to go wrong here other than soldering problems.

Still no luck getting the rig to work?

We will try to first help you via email. Sometimes we can nail the problem right off, but often it can be of no real help. We can't look over your shoulder to see whats going on and we're not psychic! Often, we can't do much more than repeat what has already been said in the above troubleshooting guide. To be of help we need as much information as possible about the problem. Simply saying that it does not work is of little use.

If all else fails, a repair service is available for a flat $35.00 fee. If you want the rig to be insured on return shipping, add another $5.00. DX stations will also have to add extra funds to cover air mail postage. It would be helpful if a short note explaining what kind of problem your having is included. We will try to repair and return the rig as quickly as possible, but it could take a few weeks in some cases, depending on other work loads from the day job.

Send the rig with a check or MO for the repair fee to:

Steven Weber, KD1JV
Steve's Electronics
633 Champlain St
Berlin, NH 03570

IC pin voltage charts: Small deviations from listed voltages acceptable due to DVM and voltage regulator tolerances

Note: LED display driver pin voltage vary with digits displayed so typical voltages not shown

IC U1, U2 SA612 mixer

Pin 1 | 1.4 V | IN
Pin 2 | 1.4 V | IN
Pin 3 | 0 V | GND
Pin 4 | 3.8 V | OUT
Pin 5 | 3.8 V | OUT
Pin 6 | 5.9 V | OSC
Pin 7 | 5.4 V | OSC
Pin 8 | 6.0 V | V+

IC U3 LM358 op amp

Pin 1 | 3.0 V | OUT
Pin 2 | 3.0 V | - IN
Pin 3 | 3.0 V | + IN
Pin 4 | 0 V | GND
Pin 5 | 3.0 V | + IN
Pin 6 | 3.0 V | - IN
Pin 7 | 3.0 V | OUT
Pin 8 | 6.0 V | V+

IC U4 LM386 audio amp

Pin 1 | 1.25 V | feedback
Pin 2 | 0 V | - IN
Pin 3 | 0 V | + IN
Pin 4 | 0 V | GND
Pin 5 | 2.9 V | OUT
Pin 6 | 6.0 V | V+
Pin 7 | 3.0 V | Bypass
Pin 8 | 1.25 V | feedback

## IC U6 MEGA 48 MPU processor

Rx | Tx | Pin function
Pin 1 | 5.0 V | 5.0V | reset
Pin 2 | 5.0 V | 5.0 V | DDS CLK
Pin 3 | 5.0 V | 5.0 V | DDS EN
Pin 4 | 5.0 V | 0 V | Paddle DOT in
Pin 5 | 5.0 V | 0 V | Paddle DASH in
Pin 6 | ------- | ------- | Digit 3
Pin 7 | 5.0 V | 5.0 V | Vcc
Pin 8 | 0 V | 0 V | GND
Pin 9 | -------- | -------- | Decimal point
Pin 10 | ------- | --------- | “d' segment
Pin 11 | -------- | --------- | Digit 1
Pin 12 | -------- | --------- | Digit 2
Pin 13 | -------- | --------- | Digit 4
Pin 14 | -------- | --------- | “e” segment
Pin 15 | -------- | --------- | “f” segment
Pin 16 | ---------- | --------- | “b” segment
Pin 17 | --------- | -------- | “g” segment
Pin 18 | --------- | -------- | “a' segment
Pin 19 | --------- | --------- | “e” segment
Pin 20 | 5.0 V | 5.0 V | AVcc
Pin 21 | 5.0 V | 5.0 V | Aref
Pin 22 | 0 V | 0 V | GND
Pin 23 | 5.0 V | 5.0 V | A/D switch input
Pin 24 | 2.5/1.5/.22 | Same | A/D Band input
Pin 25 | 0 V | 5.0 V | MUTE out
Pin 26 | 0 or 5 V | 2.5 V | Side tone out
Pin 27 | 0 V | 5.0 V | Tx enable
Pin 28 | 5 or 0 V | 5 or 0 V | DDS Data

## IC U8 74HC02 NOR GATE

Rx | Tx
Pin 1 | 0 V | 5V square wave | out
Pin 2 | 0 V | 0 V | in
Pin 3 | 3.5V | 3.5V square wave | in
Pin 4 | 5V | 5V | out
Pin 5 | 0V | 0V | in
Pin 6 | 0V | 0V | in
Pin 7 | 0V | 0V | GND
Pin 8 | 0V | 0V | in
Pin 9 | 0V | 0V | in
Pin 10 | 5V | 5V | out
Pin 11 | 3.5V | 3.5V square wave | in
Pin 12 | 0V | 0V | in
Pin 13 | 0V | 5V square wave | out
Pin 14 | 5.0 V | 5.0V | Vcc
Pins 1 and 13 will measure about 2.5 volts with DVM when transmitting steady carrier.

## Schematics:

## Receiver audio


CPU, DDS, Tx

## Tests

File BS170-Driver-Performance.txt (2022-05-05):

BS170
-----

DC bias -> 2.2v @ gate.

5v @ drain

28 MHz - good sine wave - terminated in 50 ohms -> 5.4Vpp, 2.4Vp

8v @ drain

28 MHz - good sine wave - terminated in 50 ohms -> 7Vpp, 3Vp

9v @ drain

28 MHz - good sine wave - terminated in 50 ohms -> 7.5Vpp

12v @ drain

28 MHz - good sine wave - terminated in 50 ohms -> 8.8Vpp. 190mW at max even
WITHOUT LPF.

12.5v @ drain. DC bias 2.35v @ gate. I"dq" -> 7-8mA. 28 MHz - good sine wave -
terminated in 50 ohms -> 9.6Vpp. Vp -> 4v -> 160 milliwatts WITHOUT LPF but
decent looking sine wave.

With 3 pole LPF (220 pf + 260 nH + 220 pF). Vp -> 3.76v. Vpp -> 7.5v. Around
130 mW - decent looking stable single wavish.

28 MHz @ 13.8v -> Vp -> 4v. Vpp -> 8v. With 3 pole LPF. 160 mW. Decent looking
clean wave.

Test at 7 MHz -> 21 Vpp -> 1.1W -> enough to blow RD16HHF1!

Some other results with shortcut LPF:

14 MHz -> 18 Vpp
21 MHz -> 12.6 Vpp
28 MHz -> 8.8 Vpp :)

Mitsubishi RD00HVS1
-------------------

36ma Idq

12.5v drain

28 MHz -> 8.9Vpp. Not a big difference over BS170 at all!

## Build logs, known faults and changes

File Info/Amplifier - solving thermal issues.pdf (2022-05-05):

thestone.zone (http://thestone.zone/radio/2021/01/14/capacitors.html)

## Amplifier - solving thermal issues

4-5 minutes

Last time, (http://thestone.zone/radio/2021/01/10/hellschreiber-transmit.html) my amplifier worked great. I did some testing on the air, got 8 watts of power out, etc. But one issue popped up – transmitting for a little while heated something up and produced some odd changes in power output and current consumption. With some gracious and patient help from some smart people, I’ve figured out what caused it, fixed it, and come out way ahead of where I thought I was!

### Describing the problem

When I would key up the transmitter, the power amplifier would produce 8W. But after 5 seconds it would hit 8.9W; after 10 seconds, 11.42W; and at 19.8 seconds 13.1W! Worse, though, shortly thereafter, power would drop to about 3 watts, with an increase in current consumption.

It was my understanding that it shouldn’t be thermal runaway, since I am using MOSFETs. But I couldn’t really find any articles or discussions that matched what I was seeing. So I posted on QRZ, (https://forums.qrz.com/index.php?threads/curious-thermal-behavior-in-amplifier.743786/) hoping the homebrew intelligentsia could help me out.

### Answers obtained!

Things started to make sense when I went through all the things that get hot when transmitting. The output transformer gets pretty warm; the low pass filters got similarly warm. But what got

Amplifier - solving thermal issues | about:reader?url=http%3A%2F%2Fthestone.zone%2Fr...
1 of 5 | 11/4/21, 14:08

really, really hot was the capacitors in the low pass filter…

The QRZ wizards suggested my capacitors were not spec’d for the voltage levels I was throwing at them, and probably not a type that’s ideal for RF. Since I just grabbed them out of a bulk pack I had sitting around (which doesn’t even include references or specs), that seemed like a pretty good working theory.

At the power levels I was seeing, voltage levels would be hitting 30-50v. So I needed to replace them with something better. Here is the “before” shot of the low pass filter:

And, since it will turn out to be relevant, my sweeps with the NanoVNA had shown somewhat lackluster performance (note the roughly 2.2 dB insertion loss!):

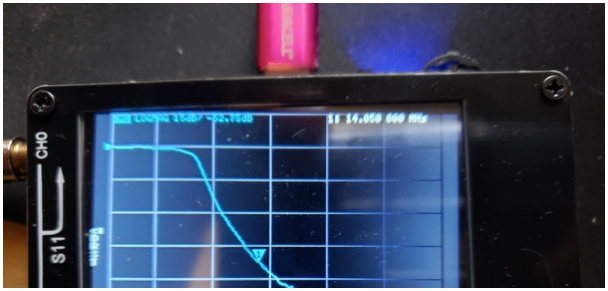
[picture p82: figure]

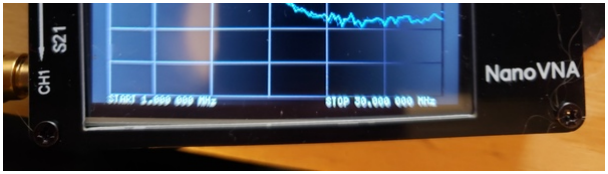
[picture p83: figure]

Apologies for the blurry image, it’s the only image I have from way back then!

### Pretty blue capacitors

I ordered some TDK caps (https://www.mouser.com/ProductDetail/810-FG24C0G2W102JNT6/) rated for 450v. They sure were expensive (as capacitors go), but the blue color looked nice. Mouser even upgraded my shipping to overnight, and they showed up the next day!

I removed the old yellow capacitors, and replaced them. Now the filter looks really snazzy:

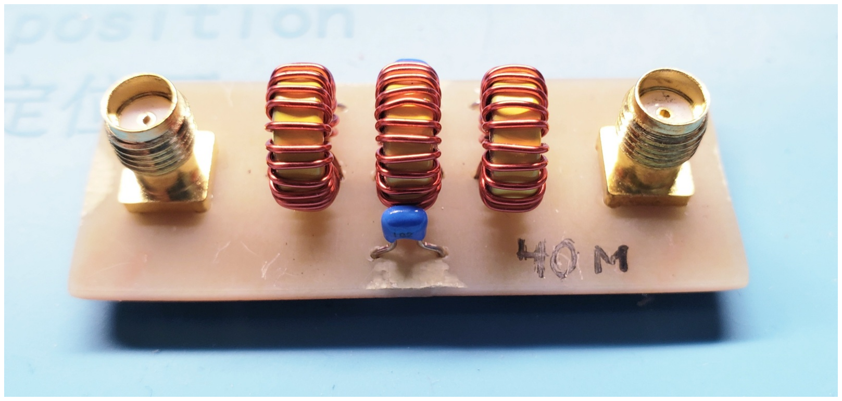
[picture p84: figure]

What was even more exciting was the VNA results. Only half a dB of loss at 7MHz, and a couple more dB down at the harmonics. The cutoff frequency moved up a bit, but not enough to be a problem. This is a useful experience for me – I’ll never use cheap capacitors in a filter again!

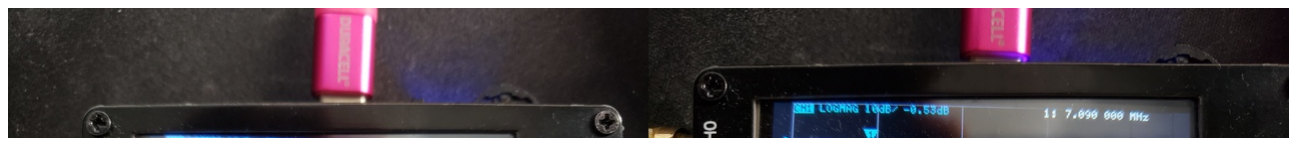
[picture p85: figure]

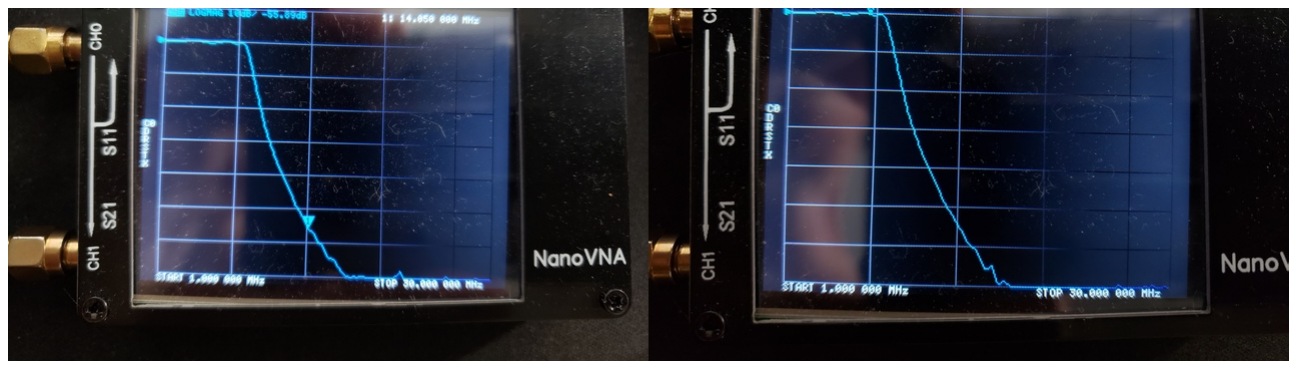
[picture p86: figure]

### Testing with the transmitter

So, with initial indications suggesting this is now a much nicer filter, I attached it inline with the transmitter, and fired it up. I was greeted with this beautiful result on the oscilloscope:

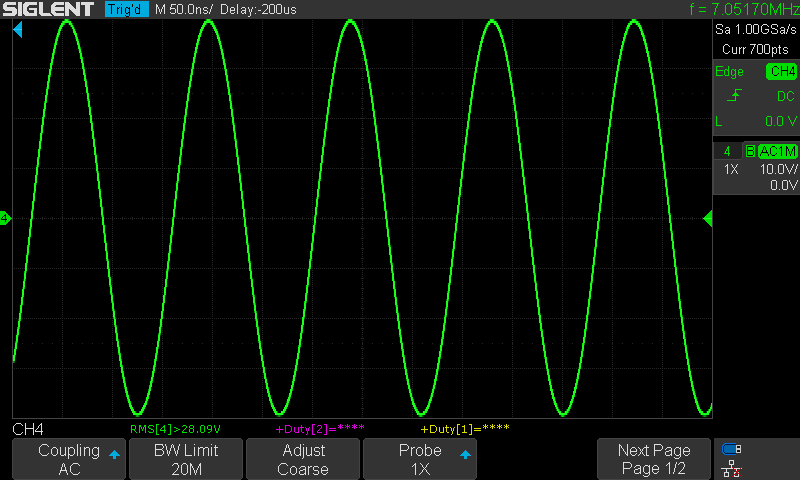
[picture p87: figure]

Just over 15 watts, and it was instant. No thermal variation – change over 30 seconds keyed up was less than 0.2 Vrms. I was so surprised initially, that I at first thought I’d left the dummy load disconnected. Nope, it was connected, and the measurement was real!

### Conclusions

I will pay much more attention to voltage ratings on capacitors. And I need to buy a stock of new ones that are more suitable for RF projects.

And my amplifier works a whole lot better than I thought it did. I just couldn’t see it because of the inadequate low pass filter.

This design is simple, hits a much higher power level than I ever really planned for in my future digital transceiver design. There are still a couple things worth playing with on this design, but it should work well for a full-suite transceiver.

Finally, the satisfaction of hunting down, learning some things, and solving an interesting problem is great. I’m especially thankful for some of the online community resources available to me. I don’t really have anyone local I can ask these kinds of questions, and the willingness of others who know so much more than me to answer my silly questions is wonderful.

Next time might be receiver stuff!

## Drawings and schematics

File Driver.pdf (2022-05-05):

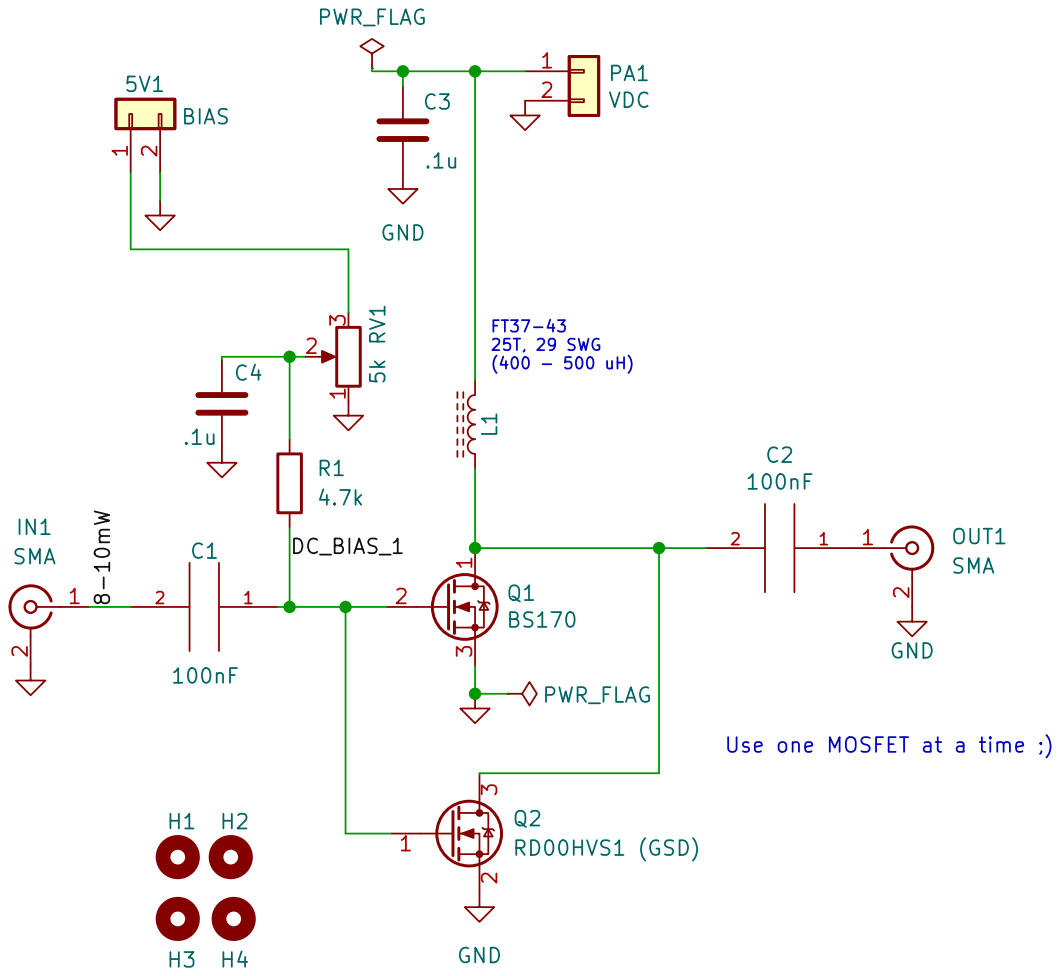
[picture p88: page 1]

File: Driver.kicad_sch Sheet: / Dhiru Kholia (VU3CER)

Id: 1/1 Title: Experimental-Driver Block

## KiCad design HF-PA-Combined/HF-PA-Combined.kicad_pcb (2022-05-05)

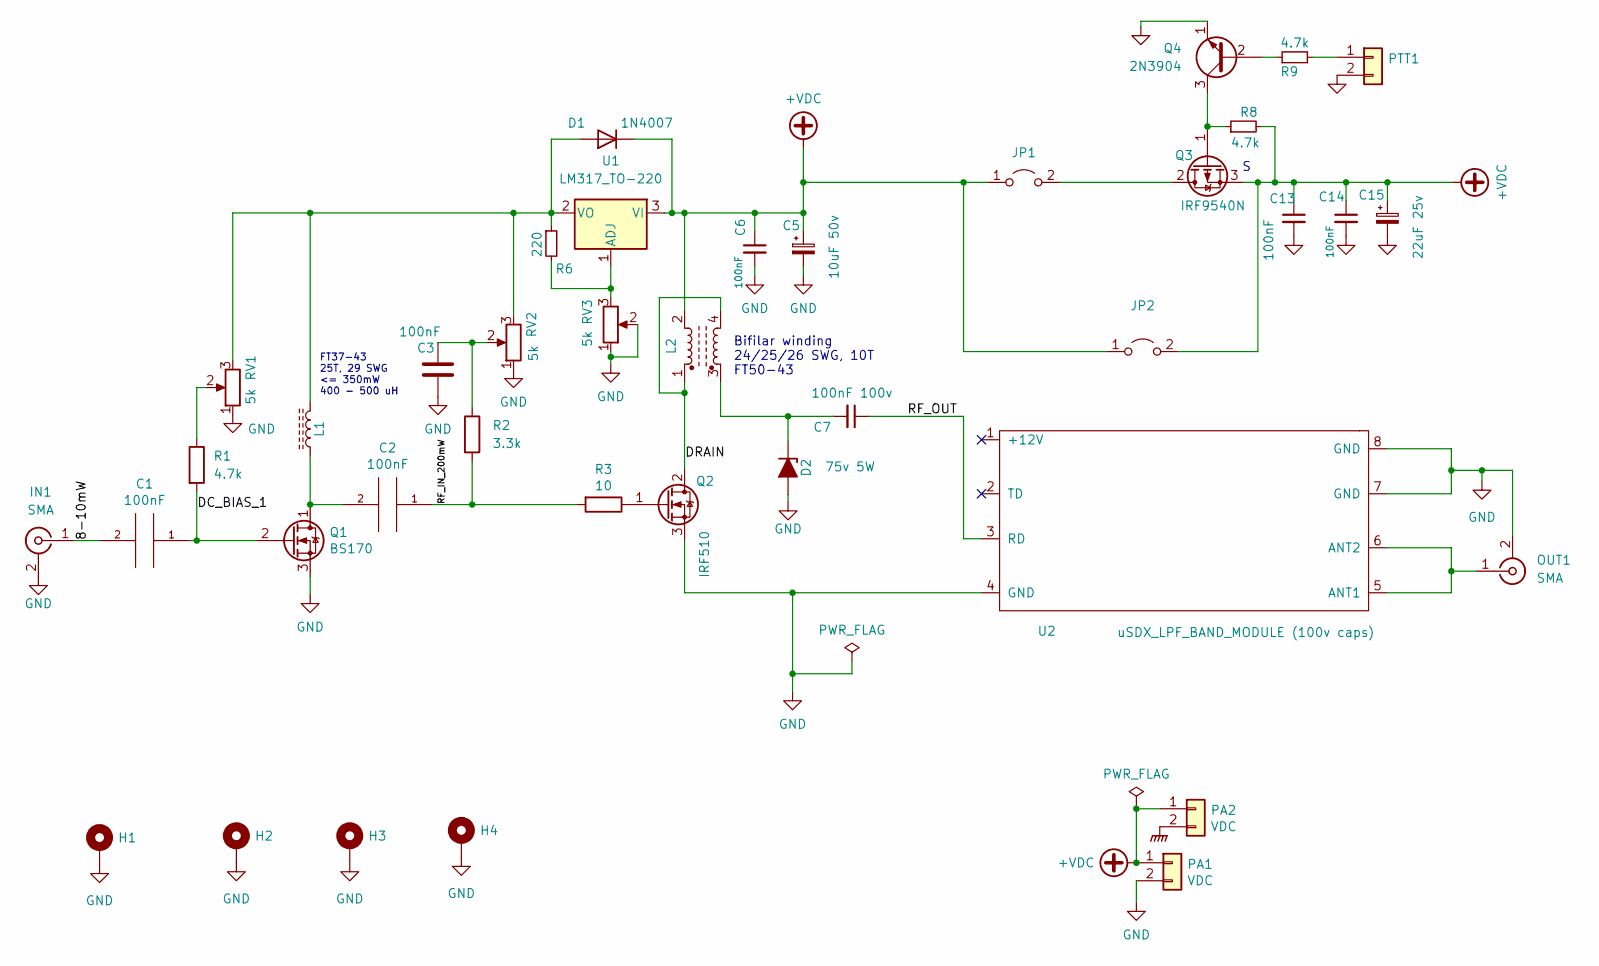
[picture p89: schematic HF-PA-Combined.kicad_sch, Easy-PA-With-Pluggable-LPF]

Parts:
C1, C2, C3, C6, C13, C14: 100nF; C_1206_3216Metric_Pad1.33x1.80mm_HandSolder
C5: 10uF 50v; C_1206_3216Metric_Pad1.33x1.80mm_HandSolder
C7: 100nF 100v; C_1206_3216Metric_Pad1.33x1.80mm_HandSolder
C15: 22uF 25v; CP_Radial_D5.0mm_P2.50mm
D1: 1N4007; D_DO-41_SOD81_P2.54mm_Vertical_KathodeUp
D2: 75v 5W; D_DO-201_P5.08mm_Vertical_AnodeUp
H1, H2, H3, H4: MountingHole_Pad; MountingHole_3.2mm_M3_ISO7380_Pad
IN1: SMA; SMA_Amphenol_901-144_Vertical
JP1, JP2: Jumper_2_Open; PinHeader_1x02_P2.54mm_Vertical
L1: L_Ferrite; L_Toroid_Vertical_L10.0mm_W5.0mm_P5.08mm
L2: L_Ferrite_Coupled; FT50-43 Transformer
OUT1: SMA; SMA_Amphenol_901-144_Vertical
PA1, PA2: VDC; PinHeader_1x02_P2.54mm_Vertical
PTT1: PTT; PinHeader_1x02_P2.54mm_Vertical
Q1: BS170; PinSocket_1x03_P2.54mm_Vertical
Q2: IRF510; TO-220-3_Vertical
Q3: IRF9540N; TO-220-3_Vertical
Q4: 2N3904; PinSocket_1x03_P2.54mm_Vertical
R1, R8, R9: 4.7k; R_1206_3216Metric_Pad1.30x1.75mm_HandSolder
R2: 3.3k; R_1206_3216Metric_Pad1.30x1.75mm_HandSolder
R3: 10; R_1206_3216Metric_Pad1.30x1.75mm_HandSolder
R6: 220; R_1206_3216Metric_Pad1.30x1.75mm_HandSolder
RV1, RV2, RV3: 5k; Potentiometer_Runtron_RM-065_Vertical
U1: LM317_TO-220; TO-220-3_Vertical
U2: uSDX_LPF_BAND_MODULE (100v caps); uSDX_LPF_Band_Module

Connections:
+VDC: C5.1, C6.1, C13.1, C14.1, C15.1, D1.1 (K), JP1.1 (A), JP2.1 (A), JP2.2 (B), L2.2, PA1.1, PA2.1, Q3.3 (S), R8.2, U1.3 (VI)
/8-10mW: C1.2, IN1.1 (In)
/DC_BIAS_1: C1.1, Q1.2 (G), R1.2
/DRAIN: L2.1, L2.4, Q2.2 (D)
/RF_IN_200mW: C2.1, R2.2, R3.2
/RF_OUT: C7.1, U2.3 (RD)
GND: C3.2, C5.2, C6.2, C13.2, C14.2, C15.2, D2.2 (A), H1.1, H2.1, H3.1, H4.1, IN1.2 (Ext), OUT1.2 (Ext), PA1.2, PTT1.2, Q1.3 (S), Q2.3 (S), Q4.1 (E), RV1.1, RV2.1, RV3.1, RV3.2, U2.4 (GND), U2.7 (GND), U2.8 (GND)
GNDPWR: PA2.2
unnamed: C2.2, L1.1, Q1.1 (D)
unnamed: C3.1, R2.1, RV2.2
unnamed: C7.2, D2.1 (K), L2.3
unnamed: D1.2 (A), L1.2, R6.1, RV1.3, RV2.3, U1.2 (VO)
unnamed: JP1.2 (B), Q3.2 (D)
unnamed: OUT1.1 (In), U2.5 (ANT1), U2.6 (ANT2)
unnamed: PTT1.1, R9.2
unnamed: Q2.1 (G), R3.1
unnamed: Q3.1 (G), Q4.3 (C), R8.1
unnamed: Q4.2 (B), R9.1
unnamed: R1.1, RV1.2
unnamed: R6.2, RV3.3, U1.1 (ADJ)

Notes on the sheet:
Bifilar winding 24/25/26 SWG, 10T FT50-43
FT37-43 25T, 29 SWG <= 350mW 400 - 500 uH

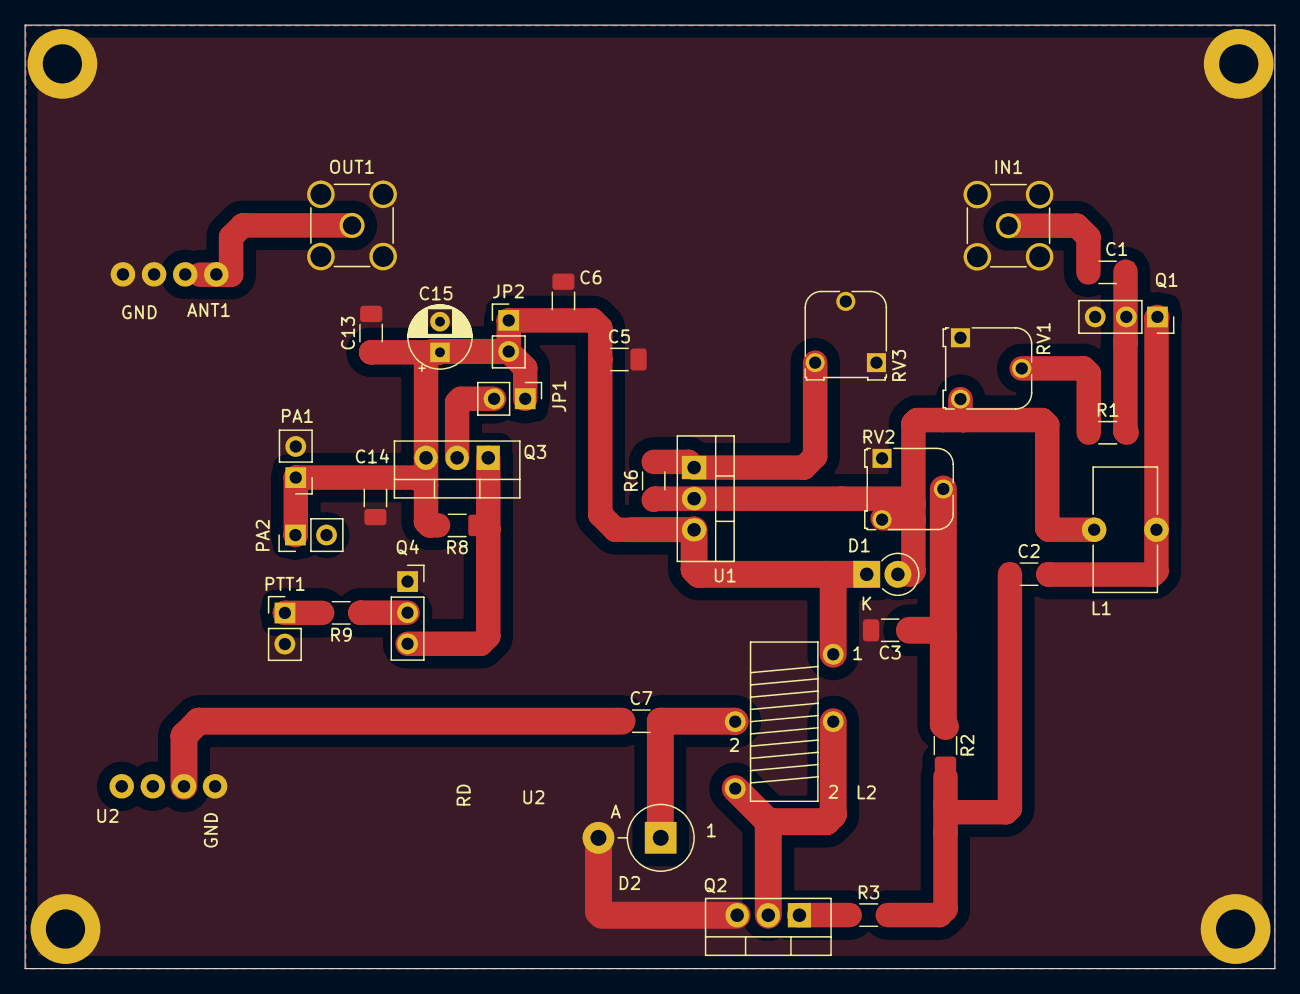
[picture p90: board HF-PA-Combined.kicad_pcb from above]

Board: 2 copper layers, 102.0 x 77.0 mm, 39 parts (0 on the bottom side), 19 nets.

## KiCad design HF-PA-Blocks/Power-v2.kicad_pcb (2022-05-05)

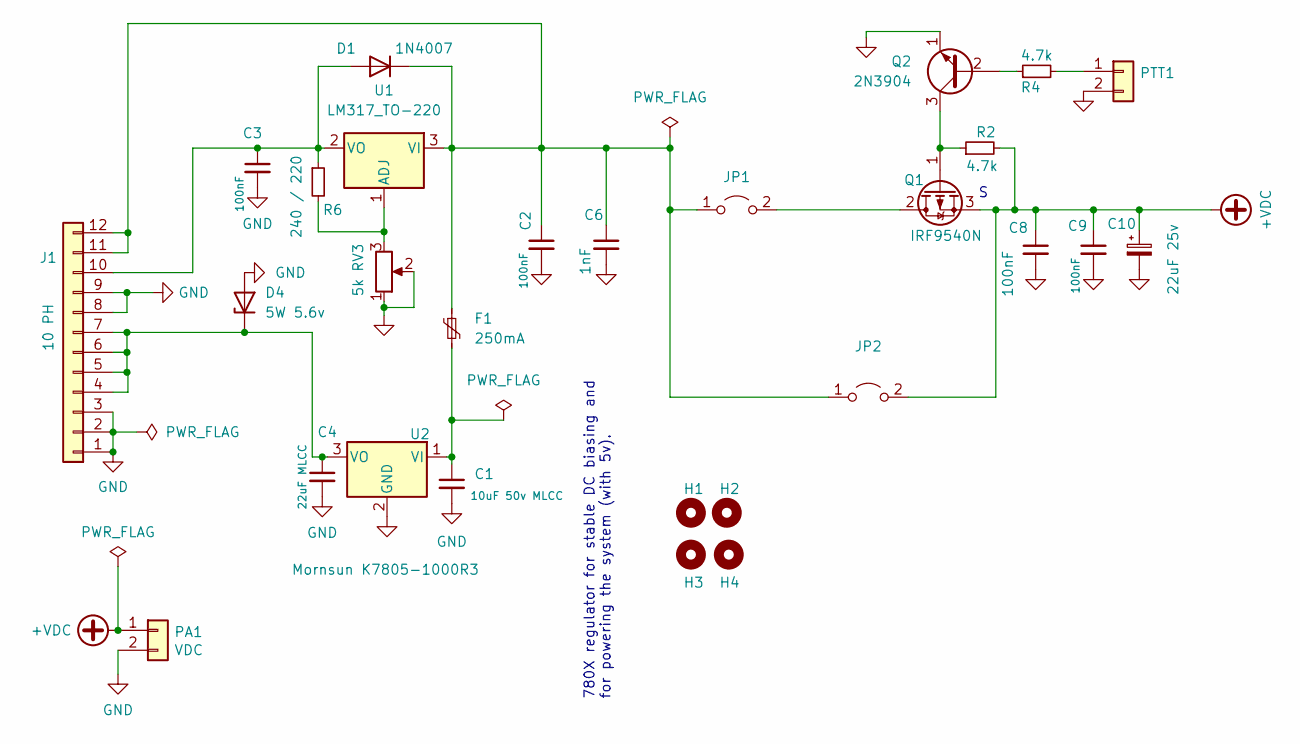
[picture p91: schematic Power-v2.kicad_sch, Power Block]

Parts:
C1: 10uF 50v MLCC; C_1206_3216Metric_Pad1.33x1.80mm_HandSolder
C2, C3, C8, C9: 100nF; C_1206_3216Metric_Pad1.33x1.80mm_HandSolder
C4: 22uF MLCC; C_1206_3216Metric_Pad1.33x1.80mm_HandSolder
C6: 1nF; C_1206_3216Metric_Pad1.33x1.80mm_HandSolder
C10: 22uF 25v; CP_Radial_D5.0mm_P2.50mm
D1: 1N4007; D_SMA_Handsoldering
D4: 5W 5.6v; D_DO-15_P5.08mm_Vertical_KathodeUp
F1: 250mA; C_Disc_D5.0mm_W2.5mm_P5.00mm
H1, H2, H3, H4: MountingHole; MountingHole_2.2mm_M2
J1: 10 PH; PinHeader_1x12_P2.54mm_Vertical
JP1, JP2: Jumper_2_Open; PinHeader_1x02_P2.54mm_Vertical
PA1: VDC; PinHeader_1x02_P2.54mm_Vertical
PTT1: PTT; PinHeader_1x02_P2.54mm_Vertical
Q1: IRF9540N; TO-220-3_Vertical
Q2: 2N3904; PinSocket_1x03_P2.54mm_Vertical
R2, R4: 4.7k; R_1206_3216Metric_Pad1.30x1.75mm_HandSolder
R6: 240 / 220; R_1206_3216Metric_Pad1.30x1.75mm_HandSolder
RV3: 5k; Potentiometer_Runtron_RM-065_Vertical
U1: LM317_TO-220; TO-220-3_Vertical
U2: Mornsun K7805-1000R3; TO-220-3_Vertical

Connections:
+VDC: C8.1, C9.1, C10.1, JP2.2 (B), PA1.1, Q1.3 (S), R2.2
GND: C1.2, C2.2, C3.2, C4.2, C6.2, C8.2, C9.2, C10.2, D4.2 (A), J1.1, J1.2, J1.3, J1.8, J1.9, PA1.2, PTT1.2, Q2.1 (E), RV3.1, RV3.2, U2.2 (GND)
unnamed: C1.1, F1.2, U2.1 (VI)
unnamed: C2.1, C6.1, D1.1 (K), F1.1, J1.11, J1.12, JP1.1 (A), JP2.1 (A), U1.3 (VI)
unnamed: C3.1, D1.2 (A), J1.10, R6.1, U1.2 (VO)
unnamed: C4.1, D4.1 (K), J1.4, J1.5, J1.6, J1.7, U2.3 (VO)
unnamed: JP1.2 (B), Q1.2 (D)
unnamed: PTT1.1, R4.2
unnamed: Q1.1 (G), Q2.3 (C), R2.1
unnamed: Q2.2 (B), R4.1
unnamed: R6.2, RV3.3, U1.1 (ADJ)

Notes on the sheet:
780X regulator for stable DC biasing and for powering the system (with 5v).

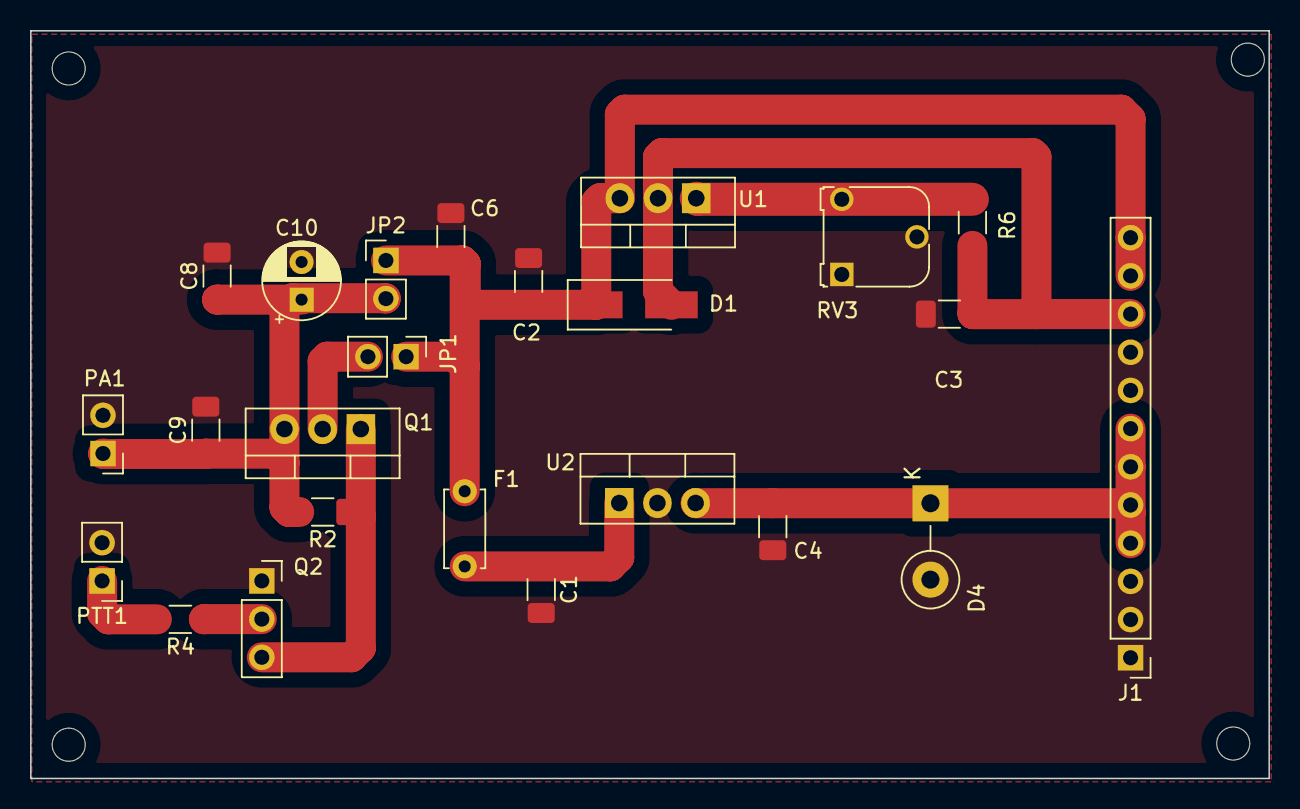
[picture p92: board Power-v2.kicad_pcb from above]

Board: 2 copper layers, 82.4 x 49.7 mm, 28 parts (0 on the bottom side), 11 nets.

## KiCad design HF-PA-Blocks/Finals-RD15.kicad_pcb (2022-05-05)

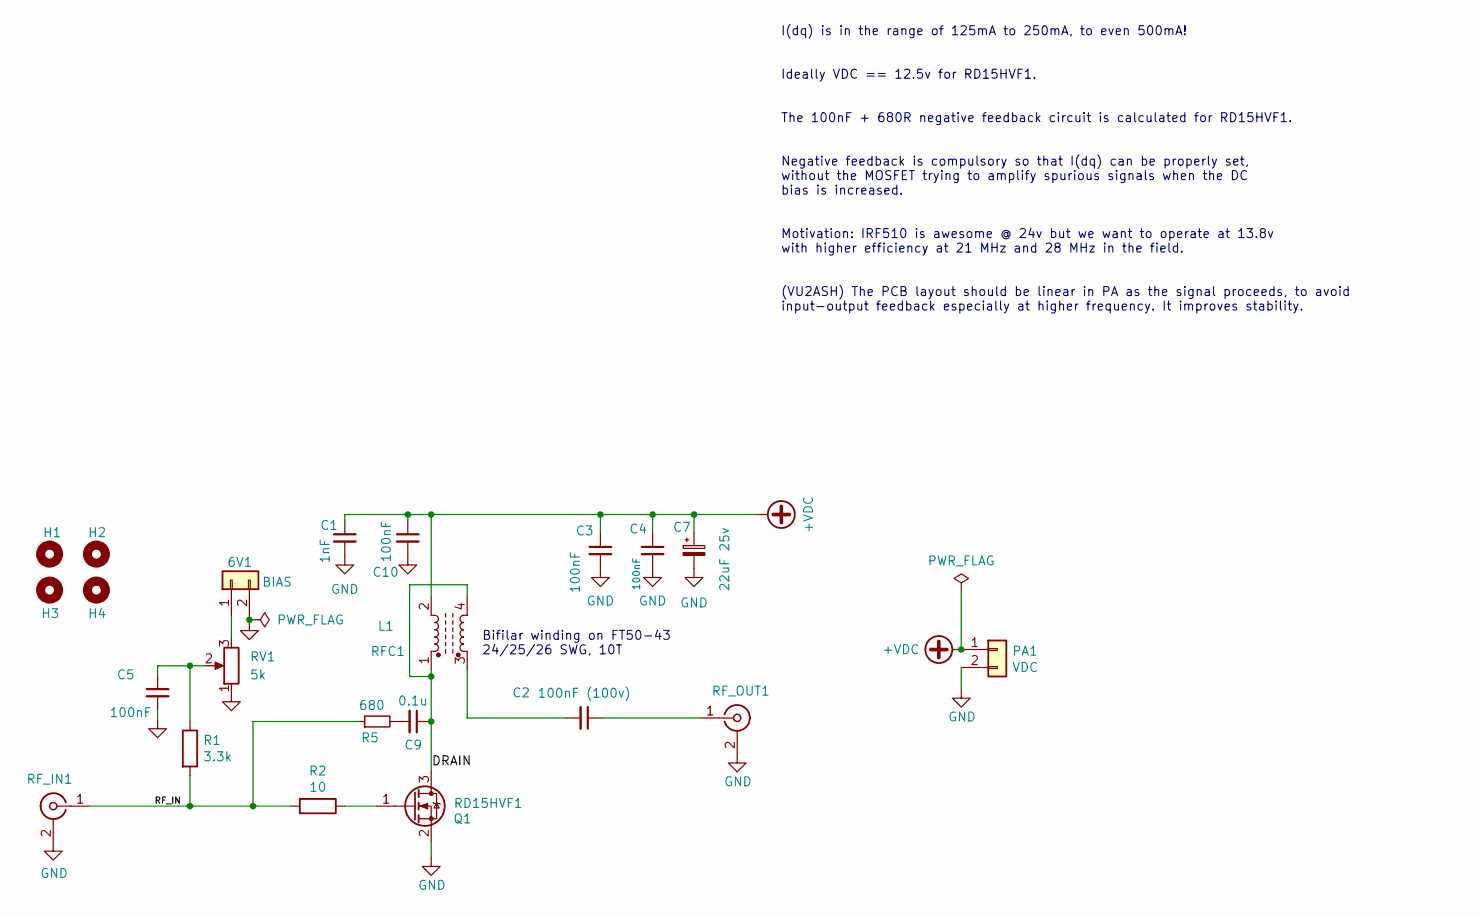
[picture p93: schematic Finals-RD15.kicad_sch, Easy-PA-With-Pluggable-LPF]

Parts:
6V1: BIAS; PinHeader_1x02_P2.54mm_Vertical
C1: 1nF; C_1206_3216Metric_Pad1.33x1.80mm_HandSolder
C2: 100nF (100v); C_1206_3216Metric_Pad1.33x1.80mm_HandSolder
C3, C4, C5, C10: 100nF; C_1206_3216Metric_Pad1.33x1.80mm_HandSolder
C7: 22uF 25v; CP_Radial_D5.0mm_P2.50mm
C9: 0.1u; C_1206_3216Metric_Pad1.33x1.80mm_HandSolder
H1, H2, H3, H4: MountingHole; MountingHole_2.2mm_M2
L1: RFC1; FT50-43 Transformer
PA1: VDC; PinHeader_1x02_P2.54mm_Vertical
Q1: RD15HVF1; TO-220-3_Vertical
R1: 3.3k; R_1206_3216Metric_Pad1.30x1.75mm_HandSolder
R2: 10; R_1206_3216Metric_Pad1.30x1.75mm_HandSolder
R5: 680; R_1206_3216Metric_Pad1.30x1.75mm_HandSolder
RF_IN1: Conn_Coaxial; SMA_Amphenol_901-144_Vertical
RF_OUT1: Conn_Coaxial; SMA_Amphenol_901-144_Vertical
RV1: 5k; Potentiometer_Runtron_RM-065_Vertical

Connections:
+VDC: C1.1, C3.1, C4.1, C7.1, C10.1, L1.2, PA1.1
/DRAIN: C9.1, L1.1, L1.4, Q1.3 (D)
/RF_IN: R1.2, R2.2, R5.1, RF_IN1.1 (In)
GND: 6V1.2, C1.2, C3.2, C4.2, C5.2, C7.2, C10.2, PA1.2, Q1.2 (S), RF_IN1.2 (Ext), RF_OUT1.2 (Ext), RV1.1
unnamed: 6V1.1, RV1.3
unnamed: C2.1, RF_OUT1.1 (In)
unnamed: C2.2, L1.3
unnamed: C5.1, R1.1, RV1.2
unnamed: C9.2, R5.2
unnamed: Q1.1 (G), R2.1

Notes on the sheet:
I(dq) is in the range of 125mA to 250mA, to even 500mA! Ideally VDC == 12.5v for RD15HVF1. The 100nF + 680R negative feedback circuit is calculated for RD15HVF1. Negative feedback is compulsory so that I(dq) can be properly set, without the MOSFET trying to amplify spurious signals when the DC bias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
Bifilar winding on FT50-43 24/25/26 SWG, 10T

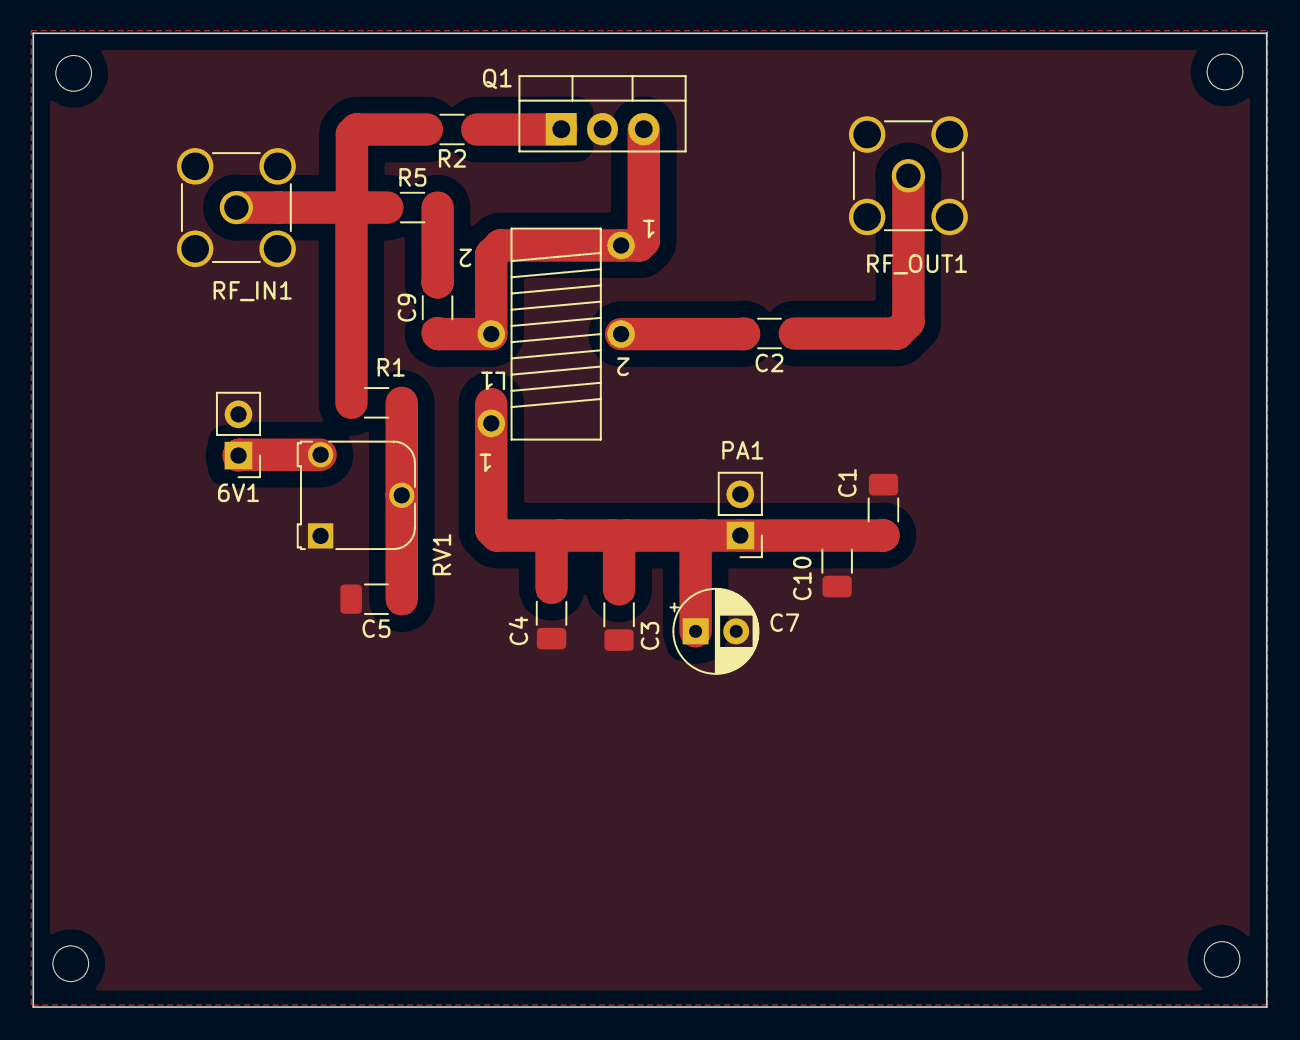
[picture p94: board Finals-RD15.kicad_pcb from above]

Board: 2 copper layers, 76.0 x 60.0 mm, 22 parts (0 on the bottom side), 10 nets.

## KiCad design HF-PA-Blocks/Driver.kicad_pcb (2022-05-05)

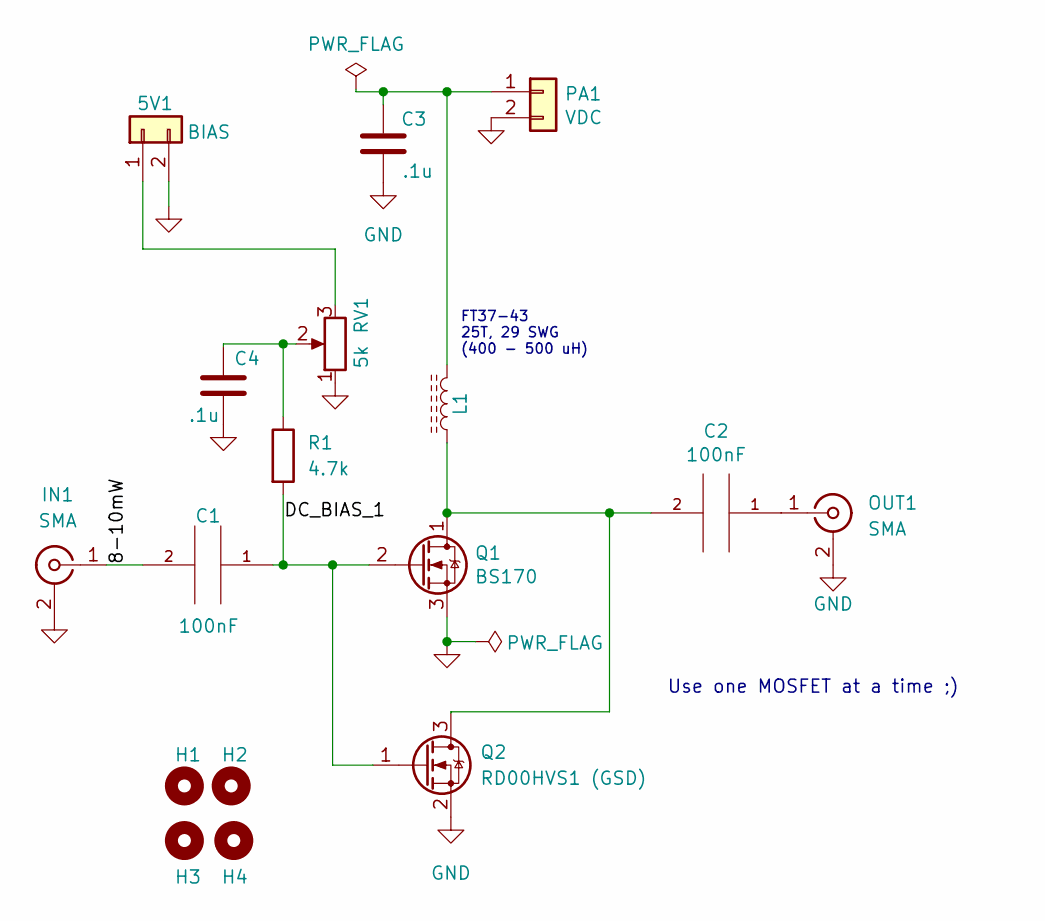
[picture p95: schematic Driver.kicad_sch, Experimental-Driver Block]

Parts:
5V1: BIAS; PinHeader_1x02_P2.54mm_Vertical
C1, C2: 100nF; C_1206_3216Metric_Pad1.33x1.80mm_HandSolder
C3, C4: .1u; C_1206_3216Metric_Pad1.33x1.80mm_HandSolder
H1, H2, H3, H4: MountingHole; MountingHole_2.2mm_M2
IN1: SMA; SMA_Amphenol_901-144_Vertical
L1: L_Ferrite; L_Toroid_Vertical_L10.0mm_W5.0mm_P5.08mm
OUT1: SMA; SMA_Amphenol_901-144_Vertical
PA1: VDC; PinHeader_1x02_P2.54mm_Vertical
Q1: BS170; PinSocket_1x03_P2.54mm_Vertical
Q2: RD00HVS1 (GSD); PinSocket_1x03_P2.54mm_Vertical
R1: 4.7k; R_1206_3216Metric_Pad1.30x1.75mm_HandSolder
RV1: 5k; Potentiometer_Runtron_RM-065_Vertical

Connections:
/8-10mW: C1.2, IN1.1 (In)
/DC_BIAS_1: C1.1, Q1.2 (G), Q2.1 (G), R1.2
GND: 5V1.2, C3.2, C4.2, IN1.2 (Ext), OUT1.2 (Ext), PA1.2, Q1.3 (S), Q2.2 (S), RV1.1
unnamed: 5V1.1, RV1.3
unnamed: C2.1, OUT1.1 (In)
unnamed: C2.2, L1.1, Q1.1 (D), Q2.3 (D)
unnamed: C3.1, L1.2, PA1.1
unnamed: C4.1, R1.1, RV1.2

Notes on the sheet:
Use one MOSFET at a time ;)
FT37-43 25T, 29 SWG (400 - 500 uH)

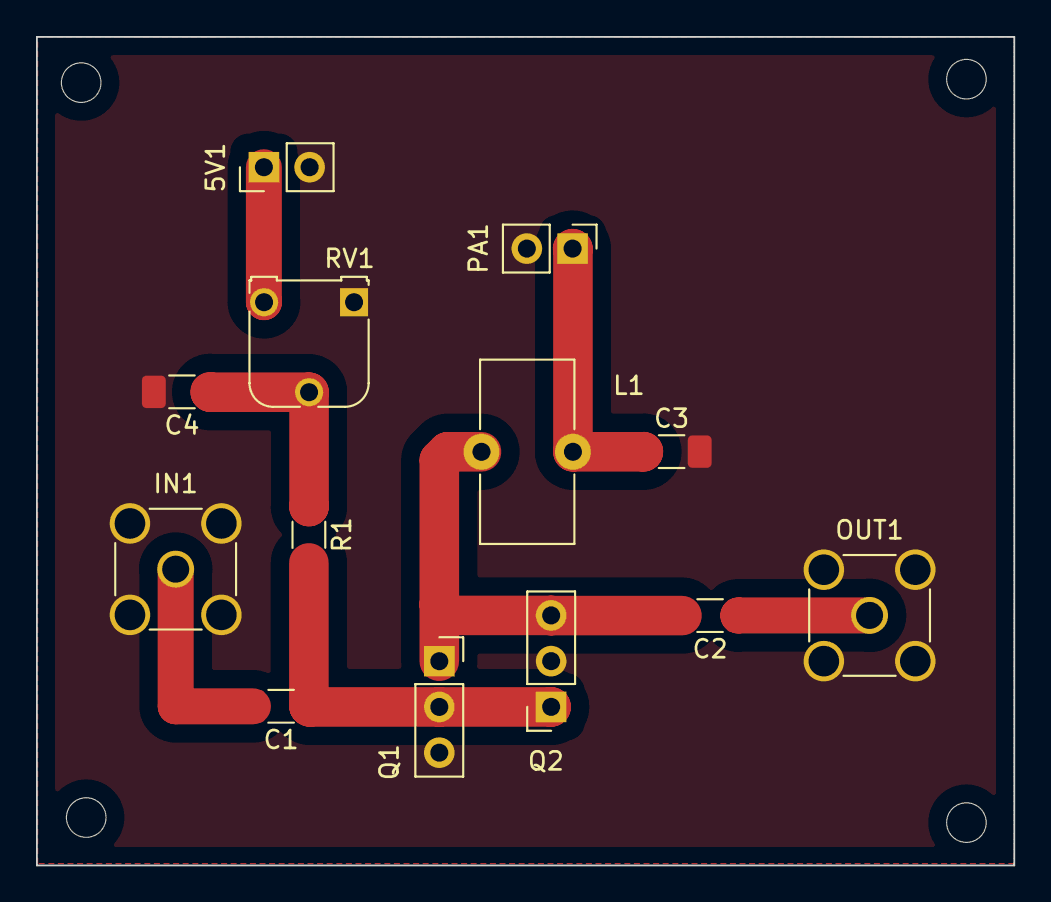
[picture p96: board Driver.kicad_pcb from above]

Board: 2 copper layers, 54.3 x 46.0 mm, 17 parts (0 on the bottom side), 8 nets.

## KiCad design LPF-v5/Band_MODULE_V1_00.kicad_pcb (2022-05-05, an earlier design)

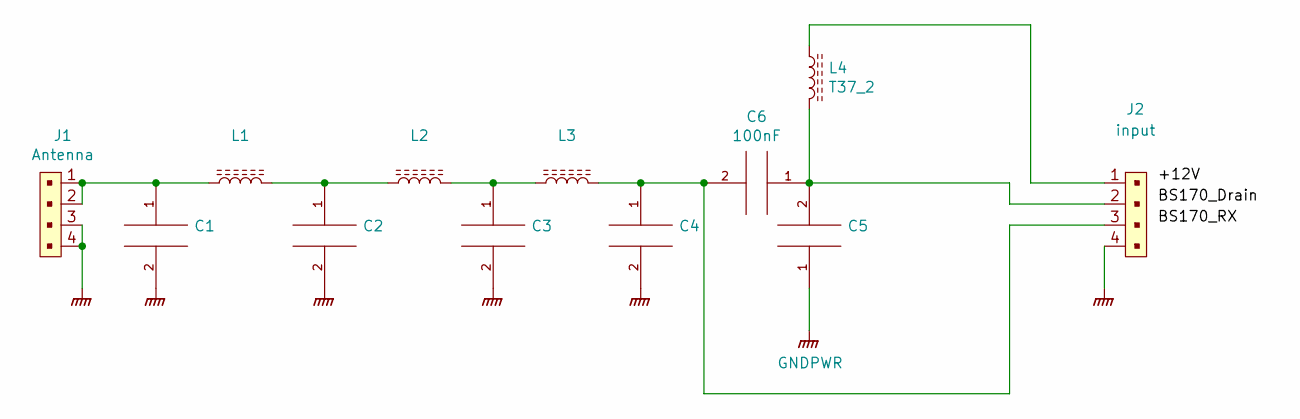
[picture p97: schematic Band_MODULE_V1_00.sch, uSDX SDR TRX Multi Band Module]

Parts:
C1, C2, C3, C4, C5: C_Disc_D5.0mm_W2.5mm_P2.50mm
C6: 100nF; C_Disc_D5.0mm_W2.5mm_P2.50mm
J1: Antenna; PinHeader_1x4_P2.54mm_Drill1.02mm; MPN 0022232041; Digi-Key_PN WM4202-ND
J2: input; PinHeader_1x4_P2.54mm_Drill1.02mm; MPN 0022232041; Digi-Key_PN WM4202-ND
L1, L2, L3: L_Toroid_Vertical_L10.0mm_W5.0mm_P5.08mm
L4: T37_2; L_Toroid_Vertical_L10.0mm_W5.0mm_P5.08mm

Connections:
GNDPWR: C1.2, C2.2, C3.2, C4.2, C5.1, J1.3, J1.4, J2.4
unnamed: C1.1, J1.1, J1.2, L1.1
unnamed: C2.1, L1.2, L2.1
unnamed: C3.1, L2.2, L3.1
unnamed: C4.1, C6.2, J2.3, L3.2
unnamed: C5.2, C6.1, J2.2, L4.2
unnamed: J2.1, L4.1

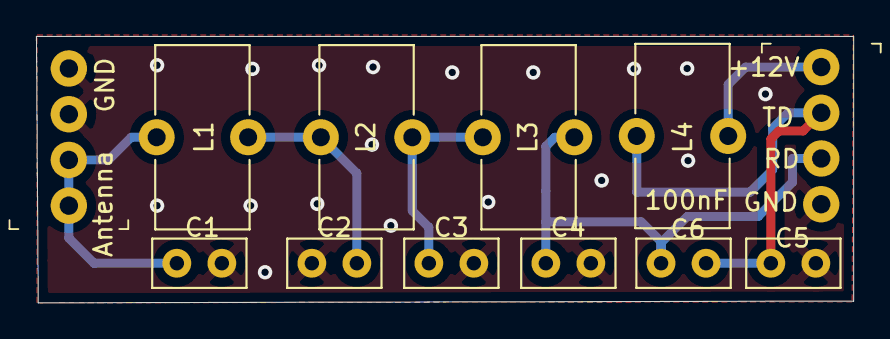
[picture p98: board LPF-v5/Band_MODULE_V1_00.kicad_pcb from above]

Board: 2 copper layers, 45.4 x 14.8 mm, 12 parts (0 on the bottom side), 7 nets.

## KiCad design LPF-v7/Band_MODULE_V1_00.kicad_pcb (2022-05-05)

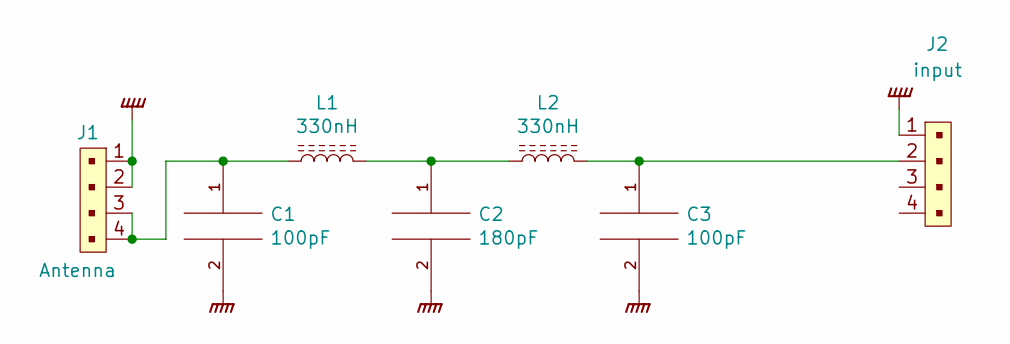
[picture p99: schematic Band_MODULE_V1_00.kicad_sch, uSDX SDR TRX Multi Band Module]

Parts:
C1, C3: 100pF; C_Disc_D5.0mm_W2.5mm_P2.50mm
C2: 180pF; C_Disc_D5.0mm_W2.5mm_P2.50mm
J1: Antenna; PinHeader_1x4_P2.54mm_Drill1.02mm; MPN 0022232041; Digi-Key_PN WM4202-ND
J2: input; PinHeader_1x4_P2.54mm_Drill1.02mm; MPN 0022232041; Digi-Key_PN WM4202-ND
L1, L2: 330nH; L_Toroid_Vertical_L10.0mm_W5.0mm_P5.08mm

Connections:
GNDPWR: C1.2, C2.2, C3.2, J1.1, J1.2, J2.1
unnamed: C1.1, J1.3, J1.4, L1.1
unnamed: C2.1, L1.2, L2.1
unnamed: C3.1, J2.2, L2.2

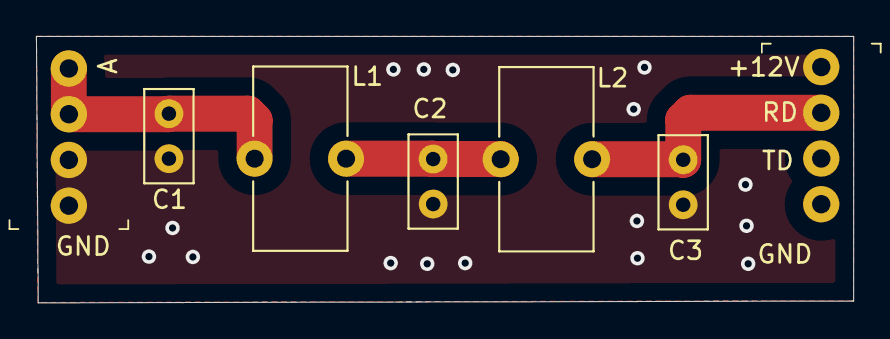
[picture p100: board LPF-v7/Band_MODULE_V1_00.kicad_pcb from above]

Board: 2 copper layers, 45.4 x 14.8 mm, 7 parts (0 on the bottom side), 4 nets.
